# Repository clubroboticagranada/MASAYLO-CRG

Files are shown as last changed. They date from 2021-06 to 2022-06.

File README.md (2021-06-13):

# MASAYLO-CRG
MASAYLO-CRG es un robot creado a partir de la idea de Antonio Gómez (https://github.com/agomezgar/masaylo) del que se van a desarrollar las tres versiones que se describen en la documentación y que tiene como propósito principal ser un robot sencillo de imprimir y de construir y que pueda servir para iniciar en el tema STEAM al alumnado desde los últimos cursos de educación primaria hasta bachillerato y ciclos formativos pasando por las distintas etapas de la ESO.

[Acceso a la documentación del proyecto](https://clubroboticagranada.github.io/MASAYLO-CRG/)

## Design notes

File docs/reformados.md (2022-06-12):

# <FONT COLOR=#8B008B>Mejoras en algunos diseños</font>
***
En este apartado se incluyen los enlaces a los archivos originales de diseño y los archivos en formato stl y step de algunas partes en las que se ha detectado una posible mejora de los diseños originales, todos ellos sin perder la base de la que se partió.

## <FONT COLOR=#007575>**Brazo aparta objetos**</font>
Se ha detectado un debilidad estructural en la parte circular del alojamiento para la pala del servo que es debida fundamentalmente a dos cosas: la primera es porque es muy fino y la segunda está en la forma en que se imprime, que provoca una debilidad por estar en el sentido de las capas. También se ha reforzado la anchura de la pala para hacer un poco mas consistente.

A continuación se ponen los enlaces a todos los archivos.

<center>

| Archivo | Comentarios |
|---|---|
| [brazo-reformado-src.FCStd](../img/3D/modificados/src/brazo-modificado-src.FCStd) | Brazo aparta objetos con alojamiento para la pala del servo reforzado y con mas anchura de pala |

</center>

| Imagen | Archivo STL | Archivo STEP |
|:-:|---|---|
| Brazo aparta objetos reforzado | [brazo-modificado.stl](../img/3D/modificados/stl/brazo-modificado.stl) | [brazo-modificado.step](../img/3D/modificados/step/brazo-modificado.step) |

</center>

En las imágenes siguientes vemos el brazo en tiempo de diseño, impreso en 3D y un detalle de la parte del alojamiento de la pala donde se aprecia mucho mejor el detalle del refuerzo.

</center>

| Captura | Imagen | Detalle |
|---|---|---|
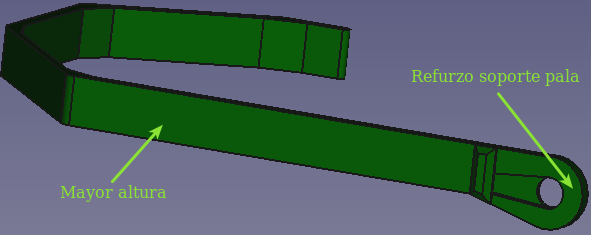
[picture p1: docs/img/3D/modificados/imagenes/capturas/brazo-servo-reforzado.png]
Captura del brazo reforzado
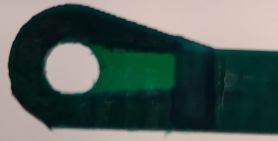
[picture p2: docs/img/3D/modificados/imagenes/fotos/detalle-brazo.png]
Detalle del brazo reforzado
|  | Imagen del brazo reforzado |  |

</center>

## <FONT COLOR=#007575>**Ballcaster**</font>
Se ha detectado un problema de falta de deslizamiento en determinadas superficies lo que provoca que el robot no se mueva todo lo bien que debiera en esos casos. A título de ejemplo indicaremos que sobre un determinado tipo de suelo de vinilo se mueve de forma correcta pero sobre otro suelo vinílico de otra marca ya no lo hace. Esto nos ha llevado a diseñar dos nuevos modelos para el ballcaster, uno se basa en un tornillo de cabeza perdida de M6 de 30 mm de longitud y el otro en poner la clásica canica como superficie de contacto.

A continuación se ponen los enlaces a todos los archivos.

<center>

| Archivo | Comentarios |
|---|---|
| [soportes-ballcaster-modificados.FCStd](../img/3D/modificados/src/soportes-ballcaster-modificados.FCStd) | Archivo fuente con el diseño de los dos tipos de ballcaster |

</center>

| Imagen | Archivo STL | Archivo STEP |
|:-:|---|---|
| Ballcaster con canica | [soporte-ballcaster-canica.stl](../img/3D/modificados/stl/soporte-ballcaster-canica.stl) | [soporte-ballcaster-canica.step](../img/3D/modificados/step/soporte-ballcaster-canica.step) |
| Ballcaster con tornillo de cabeza perdida | [soporte-ballcaster-cabeza-perdida.stl](../img/3D/modificados/stl/soporte-ballcaster-cabeza-perdida.stl) | [soporte-ballcaster-cabeza-perdida.step](../img/3D/modificados/step/soporte-ballcaster-cabeza-perdida.step) |

</center>

En las imágenes siguientes vemos ambos modelos en tiempo de diseño, impresos en 3D y un detalle del elemento ya montado.

</center>

| Captura | Imagen | Montaje |
|---|---|---|
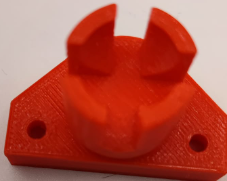
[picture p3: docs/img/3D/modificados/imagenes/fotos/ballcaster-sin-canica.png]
Imagen del ballcaster para canica
| Captura del ballcaster para canica |  | Montaje del ballcaster para canica |
| Captura del ballcaster para tornillo de cabeza perdida | Imagen del ballcaster para tornillo de cabeza perdida | Montaje del ballcaster para tornillo de cabeza perdida |

</center>

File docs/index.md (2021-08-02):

# <FONT COLOR=#8B008B>MASAYLO - CRG</font>
MASAYLO-CRG es un robot creado a partir de la idea de Antonio Gómez (https://github.com/agomezgar/masaylo) del que se van a desarrollar las tres versiones que se exponen a continuación

## <FONT COLOR=#007575>**MASAYLO-CRG-UNO**</font>
Esta versión, basada en la placa [Keyestudio UNO](https://wiki.keyestudio.com/Ks0172_keyestudio_UNO_with_Pin_Header_Interface) está pensada para que el alumnado de los últimos cursos de primaria y los del primer ciclo de ESO trabajen los temas STEAM. En la imagen siguiente vemos el aspecto que presenta el robot MASAYLO-CRG-UNO en fase de diseño. La programación de este modelo la podemos realizar a partir del IDE de Arduino (instalando la librería correspondiente) o a partir del entorno gráfico MASAYLOBLOCKLY.

<center>

| Aspecto general de MASAYLO-CRG-UNO |
|:|
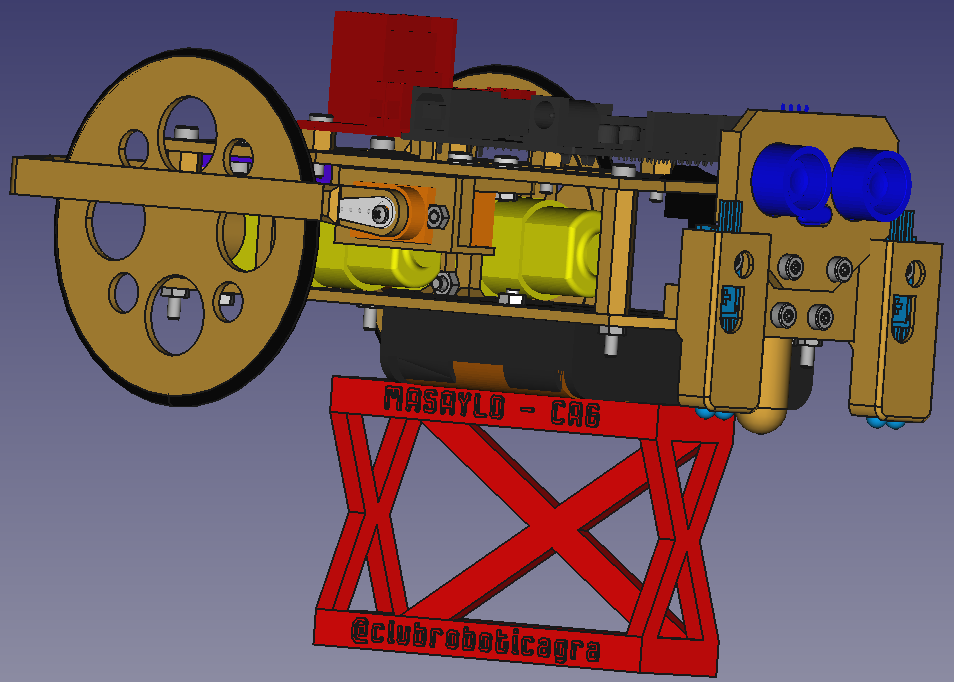
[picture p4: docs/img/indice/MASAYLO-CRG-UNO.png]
Aspecto general de MASAYLO-CRG-UNO
|  |

</center>

## <FONT COLOR=#007575>**MASAYLO-CRG-NANO**</font> 
Se trata de un modelo totalmente similar al anterior pero que en esta ocasión va a utilizar una placa tipo Arduino Nano con una shield que permite también disponer de pines de conexionado rápido. En la imagen de la izquierda vemos la placa y en la de la derecha la shield. El aspecto del robot una vez montado es totalmente similar al de la imagen anterior con la salvedad del cambio de placa.

<center>

| Aspecto placa Nano | Aspecto de la shield para placa Nano |
|:|:|
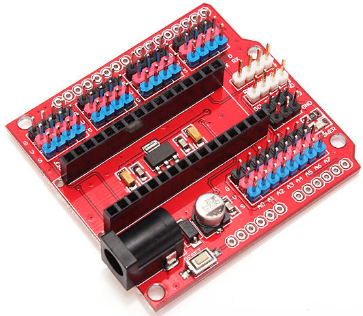
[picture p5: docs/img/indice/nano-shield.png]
Aspecto de la shield para placa Nano
| Aspecto placa Nano |  |

</center>

## <FONT COLOR=#007575>**MASAYLO-CRG-IoT**</font> 
En este caso el modelo se implementa a partir de una placa Node MCU ESP32 con shield que incluye los drivers para motores. Este modelo se dirige a los últimos cursos de ESO, bachillerato y Ciclos Formativos y su principal objetivo, sin dejar atrás la sencillez del robot, es trabajar, además de los temas STEAM, el Internet Of Thing (IoT) o internet de las cosas. Básicamente el robot va dotado de conexión WiFi con todo lo que ello conlleva. La idea principal es poder programarlo a partir de un entorno de programación por bloques, poder desarrollar APPs para móviles o tablets para su control a partir de un entorno gráfico como Blocky, montando nuestro propio servidor para tal fin. Otro objetivo de este robot es poder realizar colaboraciones a distancia consistentes en, por ejemplo, ejercer el control de un robot situado en cualquier parte del mundo desde el lugar en el que el alumnado está trabajando con la APP. En la imagen siguiente a la izquierda vemos el aspecto de la placa ESP32 y a la derecha el de la shield. El aspecto del robot una vez montado es totalmente similar al montado para la versión UNO con la salvedad del cambio de placa y que el driver de motores está integrado en la shield.

<center>

| Aspecto placa Node MCU ESP32 de 30 pines | Aspecto de la shield para placa ESP32 |
|:|:|
| Aspecto placa Node MCU ESP32 de 30 pines | Aspecto de la shield para placa ESP32 |

</center>
  
El propósito principal es que sea un robot sencillo de imprimir y de construir y que pueda servir para iniciar en el tema STEAM al alumnado desde los últimos cursos de educación primaria hasta bachillerato y ciclos formativos pasando por las distintas etapas de la ESO.

Se ha pretendido que los diseños 3D sean fácilmente imprimibles, sin necesidad de soportes y aconsejamos una altura de capa de 0.2mm. Se ha procurado que los tiempos de impresión sean lo más cortos posible pero al mismo tiempo versátiles para las posibles diferencias entre las distintas placas a utilizar. En el apartado de descripción del hardware se pondrán algunos enlaces recomendados para adquisición del material aunque, como no podía ser de otra manera, cada quien lo puede adquirir donde mejor le parezca.

Cualquiera de los modelos puede ser utilizado para otra etapa formativa u objetivo y lo podremos adaptar a nuestras necesidades, siendo esto posible porque se suministran los archivos fuente de diseño y programación y para ello solamente tenemos que cumplir con los requisitos establecidos en las [licencias](./Miscelanea/lic.md).

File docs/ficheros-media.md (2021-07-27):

# <FONT COLOR=#8B008B>Ficheros 3D para impresoras de precisión media</font>
En este apartado se incluyen los enlaces a los archivos originales de diseño y los archivos en formato stl y step.

Los archivos disponibles en este apartado están diseñados pensando en imprimir en impresoras 3D estándar de bajo coste. Estas impresoras se caracterizan por tener ciertas tolerancias en las impresiones finales, requerir calibraciones con cierta asiduidad, etc. Las impresiones con los archivos de este apartado están pensados para compensar estas tolerancias, en especial en los problemas típicos que se no han presentado, como son el ajuste del eje de los motores a la ranura de la rueda o el encaje de las tuercas empotradas en su alojamientos.

## <FONT COLOR=#007575>**Archivos fuente de diseño**</font>
Creados con [FreeCAD](https://www.freecadweb.org/) que puedes modificar, cambiar según necesidades o utilizar para aprender el manejo de esta potente herramienta.

<center>

| Archivo | Comentarios |
|---|---|
| [ruedas](../img/3D-media-precision/src/ruedas-hueco-eje-mayor.FCStd) | Rueda con una sola junta tórica y dos versiones para dos juntas, una con esta juntas y la otra separadas. |
| [soporte-ballcaster-media.FCStd](../img/3D/src/soporte-sensores-IR-ballcaster.FCStd) | Solamente contiene la pieza del ballcaster. El soporte de los sensores verticales de IR es el mismo que en alta precisión |

</center>

## <FONT COLOR=#007575>**Archivos STL y STEP**</font>
* Archivos en formato **stl**, listos para llevar a tu programa de laminación preferido y hacerlos realidad con tu impresora.

La configuración de impresión debe adaptarse en cada caso a la impresora disponible, aunque hacemos las siguientes recomendaciones:

- Balsas: No
- Soportes de impresión: No
- Resolución: 0,2 mm
- Relleno: 15 - 20%
- Marca de filamento: cualquiera
- Color del filamento: el preferido
- Material: PLA

* Archivos en formato **step**, para poder cargarlos en otros programas de diseño CAD.

En la tabla siguiente están los enlaces a estos dos tipos de ficheros.

<center>

| Imagen | Archivo STL | Archivo STEP |
|:-:|---|---|
| Rueda una junta | [rueda-una-junta.stl](../img/3D-media-precision/stl/rueda-una-junta-eje-motor-mayor.stl) | [rueda-una-junta.step](../img/3D-media-precision/step/rueda-una-junta-eje-motor-mayor.step) |
| Rueda dos juntas | [rueda-dos-juntas.stl](../img/3D-media-precision/stl/rueda-dos-juntas-eje-motor-mayor.stl) | [rueda-dos-juntas.step](../img/3D-media-precision/step/rueda-dos-juntas-eje-motor-mayor.step) |
| Rueda dos juntas ancha | [rueda-dos-juntas-ancha.stl](../img/3D-media-precision/stl/rueda-dos-juntas-ancha-eje-motor-mayor.stl) | [rueda-dos-juntas-ancha.step](../img/3D-media-precision/step/rueda-dos-juntas-ancha-eje-motor-mayor.step) |
| Ballcaster precisión media | [soporte-ballcaster-media.stl](../img/3D-media-precision/stl/soporte-ballcaster-media.stl) | [soporte-ballcaster-media.step](../img/3D-media-precision/step/soporte-ballcaster-media.step) |
</center>

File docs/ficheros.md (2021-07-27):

# <FONT COLOR=#8B008B>Ficheros 3D para impresoras de alta precisión</font>
***
En este apartado se incluyen los enlaces a los archivos originales de diseño y los archivos en formato stl y step.

Los archivos disponibles en este apartado están diseñados pensando en imprimir en una impresora del tipo [Prusa MK3S, MK3S+, Prusa Mini o Prusa Mini+](https://www.prusa3d.es/) Originales. Estas impresoras, además de tener una calidad de impresión muy buena, están optimizadas para que las impresiones finales tengan muy poca tolerancia, en lo que respecta a dimensiones, con relación a las medidas originales de diseño. Es muy posible,si no disponemos de impresoras como estas o de calidades similares, que al imprimir estos diseños tengamos algún problema a la hora de ensamblar nuestro robot y tengamos que retocar a mano ciertas partes. Ejemplos típicos de esto que se no han dado son el ajuste del eje de los motores a la ranura de la rueda o el encaje de las tuercas empotradas en su alojamientos.

<FONT COLOR=#FF0000><FONT SIZE="5">**Si no dispones de una impresora como las citadas, o similar, te aconsejamos que utilices los archivos que se suministran en el apartado [3D precisión media](./ficheros-media.md)** para las piezas incluidas en dicho apartado.</font></font>

## <FONT COLOR=#007575>**Archivos fuente de diseño**</font>
Creados con [FreeCAD](https://www.freecadweb.org/) que puedes modificar, cambiar según necesidades o utilizar para aprender el manejo de esta potente herramienta.

<center>

| Archivo | Comentarios |
|---|---|
| [plataforma-base-src.FCStd](../img/3D/src/plataforma-base-src.FCStd) | Para colocar el portapilas, los motores DC, el zumbador y el ballcaster o punto de apoyo estilo rueda loca |
| [soporte-zumbador-src.FCStd](../img/3D/src/soporte-zumbador-src.FCStd) | Para colocar un zumbador pasivo. Esta pieza también se puede colocar en la plataforma superior |
| [soporte-sensores-IR-ballcaster.FCStd](../img/3D/src/soporte-sensores-IR-ballcaster.FCStd) | Contiene dos piezas, el ballcaster y el soporte de los sensores verticales de IR |
| [soportes-ultrasonidos.FCStd](../img/3D/src/soportes-ultrasonidos.FCStd) | Contiene los soporte fijo y móvil para el sensor HC-SR04 |
| [plataforma-superior-src.FCStd](../img/3D/src/plataforma-superior-src.FCStd) | Para colocar cualquiera de las placas, el interruptor y sujetar el servo del brazo |
| [ruedas.FCStd](../img/3D/src/ruedas.FCStd) | Rueda con una sola junta tórica y dos versiones para dos juntas, una con esta juntas y la otra separadas. |
| [base-servo-src.FCStd](../img/3D/src/base-servo-src.FCStd) | Pieza para sujetar un servo tipo SG90 |
| [brazo-src.FCStd](../img/3D/src/brazo-src.FCStd) | Brazo aparta objetos con alojamiento para la pala del servo |
| [separadores-src.FCStd](../img/3D/src/separadores-src.FCStd) | M3x5 para placa UNO y driver y M3x28 para unir plataformas base y superior |
| [soporte-pruebas.FCStd](../img/3D/src/soporte-pruebas.FCStd) | Pieza pensada para poner encima el robot y poder hacer pruebas sin que este se mueva del sitio |
| [disco-encoder.FCStd](../img/3D/src/disco-encoder.FCStd) | Disco de 23 mm de diámetro con 20 ranuras acoplable a eje de motor para encoder optico |
| [conjunto-src.FCStd](../img/3D/src/conjunto-src.FCStd) | Muestra la colocación de los distintos elementos en fase de diseño |
| [Todo en un archivo zip](../img/3D/src.zip) | Para descargar todos los archivos en un clic |

</center>

## <FONT COLOR=#007575>**Archivos STL y STEP**</font>
* Archivos en formato **stl**, listos para llevar a tu programa de laminación preferido y hacerlos realidad con tu impresora.

La configuración de impresión debe adaptarse en cada caso a la impresora disponible, aunque hacemos las siguientes recomendaciones:

- Balsas: No
- Soportes de impresión: No
- Resolución: 0,2 mm
- Relleno: 15 - 20%
- Marca de filamento: cualquiera
- Color del filamento: el preferido
- Material: PLA

* Archivos en formato **step**, para poder cargarlos en otros programas de diseño CAD.

En la tabla siguiente están los enlaces a estos dos tipos de ficheros.

<center>

| Imagen | Archivo STL | Archivo STEP |
|:-:|---|---|
| Ballcaster | [ballcaster.stl](../img/3D/stl/ballcaster.stl) | [ballcaster.step](../img/3D/step/ballcaster.step) |
| Base para servo | [base-servo.stl](../img/3D/stl/base-servo.stl) | [base-servo.step](../img/3D/step/base-servo.step) |
| Brazo | [brazo.stl](../img/3D/stl/brazo.stl) | [brazo.step](../img/3D/step/brazo.step) |
| Disco encoder óptico | [disco-encoder.stl](../img/3D/stl/disco-encoder.stl) | [disco-encoder.step](../img/3D/step/disco-encoder.step) |
| Base | [plataforma-base.stl](../img/3D/stl/plataforma-base.stl) | [plataforma-base.step](../img/3D/step/plataforma-base.step) |
| Plataforma superior | [plataforma-superior.stl](../img/3D/stl/plataforma-superior.stl) | [plataforma-superior.step](../img/3D/step/plataforma-superior.step) |
| Rueda una junta | [rueda-una-junta.stl](../img/3D/stl/rueda-una-junta.stl) | [rueda-una-junta.step](../img/3D/step/rueda-una-junta.step) |
| Rueda dos juntas | [rueda-dos-juntas.stl](../img/3D/stl/rueda-dos-juntas.stl)| [rueda-dos-juntas.step](../img/3D/step/rueda-dos-juntas.step) |
| Rueda dos juntas ancha | [rueda-dos-juntas-ancha.stl](../img/3D/stl/rueda-dos-juntas-ancha.stl)| [rueda-dos-juntas-ancha.step](../img/3D/step/rueda-dos-juntas-ancha.step) |
| Porta sensores IR | [porta-sensores-IR.stl](../img/3D/stl/porta-sensores-IR.stl) | [porta-sensores-IR.step](../img/3D/step/porta-sensores-IR.step) |
| Separador M3x5mm | [separador-M3x5.stl](../img/3D/stl/separador-M3x5.stl) | [separador-M3x5.step](../img/3D/step/separador-M3x5.step) |
| Separador M3x28mm | [separador-M3x28.stl](../img/3D/stl/separador-M3x28.stl) | [separador-M3x28.step](../img/3D/step/separador-M3x28.step) |
| Banco para pruebas | [soporte-para-pruebas.stl](../img/3D/stl/soporte-para-pruebas.stl) | [soporte-para-pruebas.step](../img/3D/step/soporte-para-pruebas.step) |
| Soporte para zumbador pasivo | [soporte-zumbador.stl](../img/3D/stl/soporte-zumbador.stl) | [soporte-zumbador.step](../img/3D/step/soporte-zumbador.step) |
| Soporte HC04 fijo | [ultrasonidos-fijo.stl](../img/3D/stl/ultrasonidos-fijo.stl) | [ultrasonidos-fijo.step](../img/3D/step/ultrasonidos-fijo.step) |
| Soporte HC04 movil | [ultrasonidos-movil.stl](../img/3D/stl/ultrasonidos-movil.stl) | [ultrasonidos-movil.step](../img/3D/step/ultrasonidos-movil.step) |
| Todos los archivos en un zip | [Todos los stl en un zip](../img/3D/stl.zip) | [Todos los step en un zip](../img/3D/step.zip) |

</center>

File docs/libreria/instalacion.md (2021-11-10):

# <FONT COLOR=#8B008B>Instalación de la librería para Arduino</font>
La librería se instala como cualquier librería de arduino:

* Descargamos la [Librería](https://github.com/clubroboticagranada/masaylo-libreria/blob/main/Masaylo.zip).

* Abrimos el IDE de Arduino (entorno de desarrollo de Arduino). Para instalarlo si no lo tienes, lo puedes descargar en la dirección: [https://www.arduino.cc/en/software](https://www.arduino.cc/en/software)
* Nos dirigimos al Menú Programa > Incluir librería > Añadir biblioteca .ZIP ...

<center>

| Incluir librería añadir .zip|
|:|
| Incluir librería añadir .zip |

</center>

* En la siguiente ventana elegimos la ruta de la biblioteca o librería a instalar, que en nuestro caso es Masaylo.zip, habrá que recordar dónde la descargamos previamente.

| Incluir librería elegir .zip|
|:|
| Incluir librería elegir .zip |

</center>

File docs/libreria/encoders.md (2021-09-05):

# <FONT COLOR=#8B008B>Encoders y Masaylo</font>
Masaylo puede incorporar dos sensores de infrarrojos tipo encoder, uno en cada una de las ruedas del mismo. Estos dispositivos sirven para poder determinar de forma optica el ángulo de giro que se desplaza cada rueda, y por tanto también somos capaces de conocer los desplazamientos del robot. Con estos elementos podemos girar un determinado ángulo nuestro robot o bien moverlo una cierta distancia.

<center>

| Encoders esquema | Encoders foto |
|:|:|
| Encoders esquema | Encoders foto |

</center>

Las órdenes que tenemos para controlar los encoders son las siguientes:

* ***objetoMasaylo.encoders (pinIzdoEncoder, pinDchoEncoder, diametro cm)***: Configura los pines de los sensores infrarrojos de los encoders y el diámetro en cm de las ruedas. Si no pasas parámetros *objetoMasaylo.encoders()*, pone los valores *objetoMasaylo.encoders(2,3,7.8)*, por tanto se asigna el pin digital 2 al sensor izquierdo y el 3 al derecho, además configura un diámetro de rueda de 7.8 cm. Recordar que esta instrucción al ser de configuración debe estar en el setup de nuestro programa. En el ejemplo *m.encoders (2,3,7.8)*.
* ***objetoMasaylo.distancia (distancia cm)***: Espera hasta que ambas ruedas del robot se han movido la cantidad de cm que le hemos pasado. En el ejemplo *m.distancia (20)*.
* ***objetoMasaylo.angulo (angulo grados)***: Espera hasta que ambas ruedas del robot han girado el angulo pasado. En el ejemplo *m.angulo (90)*.
* ***objetoMasaylo.vueltas (n_vueltas)***: Espera hasta que ambas ruedas del robot Masaylo han girado el numero de vueltas indicadas.

En el ejemplo que presentamos a continuación (ejemplo 3 de la librería), hacemos un bucle for para repetir cuatro veces el desplazamiento del robot 20 cm y el giro hacia derechas de 90º, por tanto el robot debe realizar un desplazamiento en forma de cuadrado. 

<center>

| Uso de encoders |
|:|
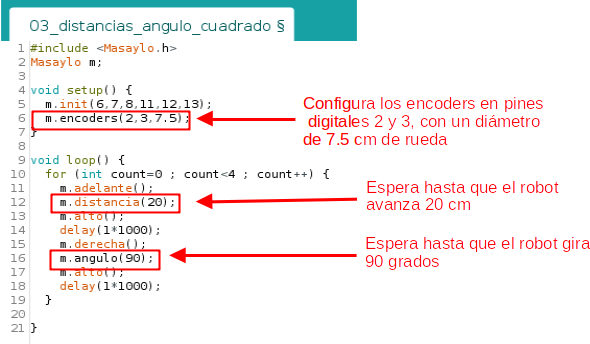
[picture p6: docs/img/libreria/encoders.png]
Uso de encoders
|  |

</center>

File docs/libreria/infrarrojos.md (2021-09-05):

# <FONT COLOR=#8B008B>Infrarrojos y Masaylo</font>
Masaylo incorpora dos sensores de infrarrojos alojados en sendos portasensores en la parte delantera cercanos al suelo, el objeto de los mismos es detectar reflexión o no de luz infrarroja sobre una superficie, pudiendo distinguir entre superficies que reflejan (blanco) y otras que no lo hacen (negro).

<center>

| Infrarrojos |
|:|
| Infrarrojos |

</center>

Las órdenes que tenemos para controlar los sensores de infrarrojos son las siguientes:

* ***objetoMasaylo.infrarrojos (pinIzdoIr,pinDchoIr)***: Configura los pines de los sensores infrarrojos de suelo del robot. Si no pasas parámetros *objetoMasaylo.infrarrojos()*, pone los valores *objetoMasaylo.infrarrojos(14,15)*, asociando el sensor izquierdo al pin 14 (A0), y el derecho al pin 15 (A1), esta instrucción debe estar en el setup de nuetro programa. En nuestro caso del ejemplo *m.infrarrojos (14,15)*.
* ***objetoMasaylo.nIzquierda ()***: Nos devuelve "true" si el sensor de infrarrojos izquierdo está a negro y "false" si no lo está. En nuestro ejemplo *m.nIzquierda()*.
* ***objetoMasaylo.nDerecha ()***: Nos devuelve "true" si el sensor de infrarrojos derecho está a negro y "false" si no lo está. En nuestro ejemplo *m.nDerecha()*.
* ***objetoMasaylo.bIzquierda ()***: Nos devuelve "true" si el sensor de infrarrojos izquierdo está a blanco y "false" si no lo está. En nuestro ejemplo *m.bIzquierda()*.
* ***objetoMasaylo.bDerecha ()***: Nos devuelve "true" si el sensor de infrarrojos derecho está a blanco y "false" si no lo está. En nuestro ejemplo *m.bDerecha()*.

En el ejemplo que presentamos a continuación (ejemplo 9 de la librería), se configura el sensor de infrarrojos, y posteriormente, con varios condicionales, se comprueba todas las combinaciones posibles de estados de blanco y negro de los sensores, para mostrar el estado actual de los mismos en la pantalla del ordenador a través de comunicación serie.

<center>

| Uso de infrarrojos |
|:|
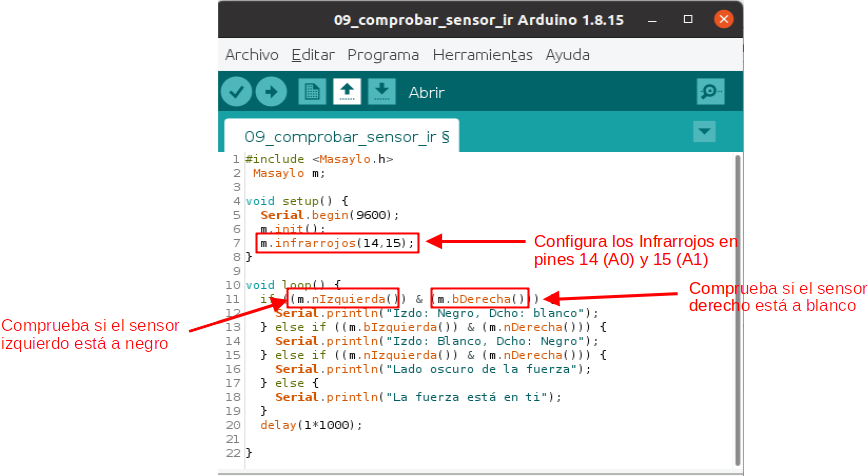
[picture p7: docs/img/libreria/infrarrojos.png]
Uso de infrarrojos
|  |

</center>

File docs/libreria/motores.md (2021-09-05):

# <FONT COLOR=#8B008B>Controlar motores de Masaylo</font>

<center>

| Motores |
|:|
| Motores |

</center>

Para el control de los dos motores de corriente contínua que mueven a Masaylo, lo primero que debemos hacer es crear un objeto tipo robot Masaylo, para ello pondremos la línea antes de void setup(), ***Masaylo objetoMasaylo***, en nuestro caso *Masaylo m* (nuestro robot Masaylo se llama m).

<center>

| Crear objeto Masaylo|
|:|
| Crear objeto Masaylo |

</center>

En la función setup(), ya sabéis que se ejecuta una sola vez, vamos a definir los pines de los motores, lo que se puede hacer de dos maneras:

* Sin pasar parámetros (sin colocar nada entre los paréntesis), ***objetoMasaylo.init()***, en nuestro caso de ejemplo *m.init()*: con esta orden indicamos que los pines de los motores son los que trae por defecto *objetoMasaylo.init(6,7,8,11,12,13)*, siendo el orden de los pines definidos de izquierda a derecha,  pin de control de velocidad de giro (PWM) del motor izquierdo, pin A del motor izquierdo,  pin B del motor izquierdo, pin de control de velocidad de giro (PWM) del motor derecho, pin A del motor derecho,  pin B del motor derecho.
* Pasando parámetros de pines (colocándolos entre paréntesis), ***objetoMasaylo.init (pinPWMMotorIzdo,pinAMotorIzdo,pinBMotorIzdo,pinPWMMotorDcho,pinAMotorDcho,pinBMotorDcho)***, de esta manera podríamos conectar nuestros motores a los pines que deseemos, un ejemplo podría ser *m.init(6,7,8,11,12,13)*.

Pasamos a explicar las instrucciones para mover el robot:

* ***objetoMasaylo.adelante (velocidad)***: Mueve el robot Masaylo hacia delante, le podemos pasar el valor de la velocidad a la que lo hace (entre 0 y 255), si no pasamos valor, paréntesis sin valor, lo hace a 255. En nuestro caso del ejemplo *m.adelante()*.
* ***objetoMasaylo.atras (velocidad)***: Mueve el robot Masaylo hacia atrás, le podemos pasar el valor de la velocidad a la que lo hace (entre 0 y 255), si no pasamos valor,  paréntesis sin valor, lo hace a 255. En nuestro caso del ejemplo *m.atras()*.
* ***objetoMasaylo.izquierda (velocidad)***: Gira (pivota) el robot Masaylo hacia la izquierda, le podemos pasar el valor de la velocidad a la que lo hace (entre 0 y 255), si no pasamos valor, paréntesis sin valor, lo hace a 255. En nuestro caso del ejemplo *m.izquierda()*.
* ***objetoMasaylo.derecha (velocidad)***: Gira (pivota) el robot Masaylo hacia la derecha, le podemos pasar el valor de la velocidad a la que lo hace (entre 0 y 255), si no pasamos valor, paréntesis sin valor, lo hace a 255. En nuestro caso del ejemplo *m.derecha()*.
* ***objetoMasaylo.alto ()***: Para el robot Masaylo. En nuestro caso del ejemplo *m.alto()*.

A continuación vemos estas órdenes reflejadas en el ejemplo 01 de la librería:

<center>

| Ejemplo 01 de la librería |
|:|
| Ejemplo 01 de la librería |

</center>

En el ejemplo 02 vemos como se pasan valores de velocidad a los movimientos de nuestro robot:

<center>

| Ejemplo 02 de la librería |
|:|
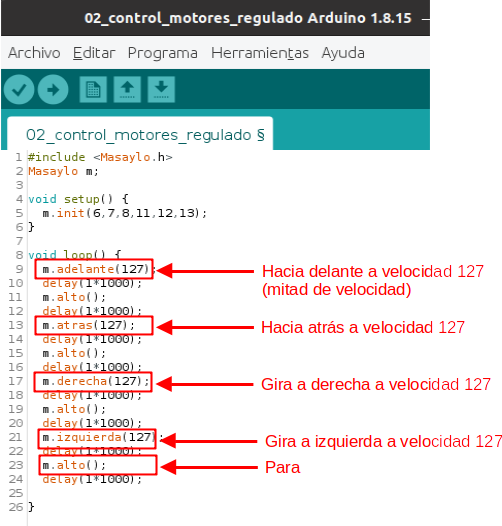
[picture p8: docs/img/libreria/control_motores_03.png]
Ejemplo 02 de la librería
|  |

</center>

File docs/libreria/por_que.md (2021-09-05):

# <FONT COLOR=#8B008B>El por qué de la librería</font>
Unos de los problemas para controlar robots muchas veces es la ausencia de instrucciones amigables en arduino para controlar sus elementos (motores dc, sensor de ultrasonidos, sensores infrarrojos para seguir líneas, control de distancias y giros a través de encoders, servomotores y zumbadores), todo ello pensando en facilitar el uso de dicho robot para estudiantes de secundaria. Por este motivo, a través de la colaboración entre el ***Club de Robótica Granada*** y ***Antonio Gómez***, nos planteamos adaptar la librería de su robot Masaylo para el control de una revisión de dicho robot.

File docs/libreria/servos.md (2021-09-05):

# <FONT COLOR=#8B008B>Servomotores y Masaylo</font>
Masaylo incorpora dos servomotores, uno que nos sirve para girar el sensor de ultrasonidos situado en la zona delantera del robot, y otro para girar el brazo que sirve para capturar objetos. Los servomotores que presenta Masaylo son los microservos *SG-90* que permiten un giro entre 0º y 179º.

| Servomotores |
|:|
| Servomotores |

</center>

Las órdenes que tenemos para controlar los servomotores son:

* ***objetoMasaylo.servos (pin servocabeza, pin servobrazo)***: Configura los pines de los servos de la cabeza y del brazo respectivamente. Si no pasas parámetros *objetoMasaylo.servos()*, pone los valores *objetoMasaylo.servos(5,4)*, por tanto el servo de la cabeza (ultrasonidos) es asignado al pin digital 5 y el servo del brazo al pin digital 4, esta instrucción debe estar en el setup de nuestro programa. En el ejemplo *m.servos(5,4)*.
* ***objetoMasaylo.giracabeza (grados)***: Gira el servo de la cabeza un ángulo dado entre 0º y 179º. En el ejemplo *m.giracabeza (i)*, siendo i una variable en este caso.
* ***objetoMasaylo.girabrazo (grados)***: Gira el servo del brazo un ángulo dado entre 0º y 179º.
  
En el ejemplo que presentamos a continuación (ejemplo 6 de la librería) se configura los pines de los servomotores, para posteriormente producir un movimiento giratorio alternativo del sensor de ultrasonidos, moviéndolo con un microservo de 10º a 170º y de 170º a 10º.

<center>

| Control de servomotores |
|:|
| Control de servomotores |

</center>

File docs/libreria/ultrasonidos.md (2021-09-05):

# <FONT COLOR=#8B008B>Ultrasonidos y Masaylo</font>
Masaylo incorpora un sensor de ultrasonidos en su parte delantera, que nos servirá para medir distancias a los objetos que pueda encontrar en su camino.

<center>

| Sensor de Ultrasonidos |
|:|
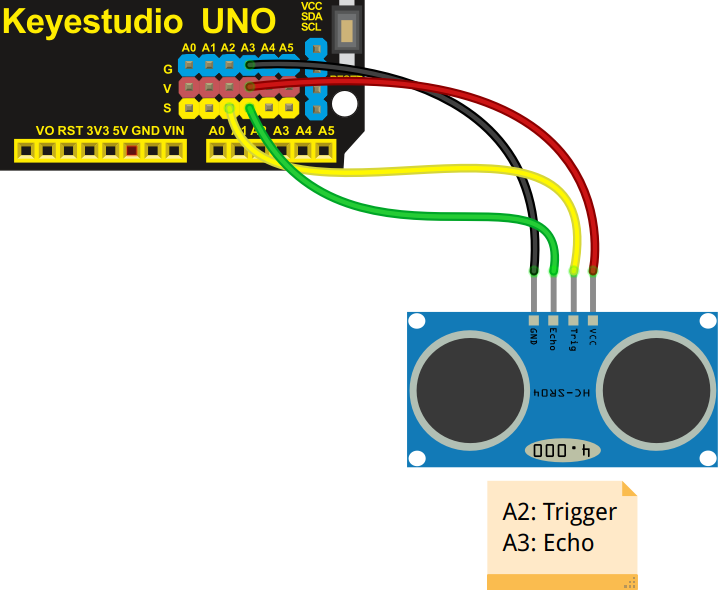
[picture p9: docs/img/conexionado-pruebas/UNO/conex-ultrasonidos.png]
Sensor de ultrasonidos
|  |

</center>

Las órdenes que tenemos para controlar el sensor de ultrasonidos son:

* ***objetoMasaylo.ultrasonidos (pinTrigger,pinEcho)***: Configura los pines trigger y echo del sensor de ultrasonidos. Si no pasas parámetros *objetoMasaylo.ultrasonidos()*, pone los valores *objetoMasaylo.ultrasonidos(16,17)*, de esta forma el pin del Trigger es el 16 (A2), y el pin del Echo es el 17 (A3), esta instrucción debe estar en el setup de nuestro programa. En nuestro caso del ejemplo *m.ultrasonidos (16,17)*.
* ***objetoMasaylo.distancia ()***: Nos devuelve la distancia en cm entre el sensor de ultrasonidos y el objeto que tenga enfrentado. En nuestro caso del ejemplo *m.distancia()*.
  
En el ejemplo que presentamos a continuación (ejemplo 8 de la librería), se configura el sensor de ultrasonidos, para mostrar por el puerto serie la distancia a la que se encuentra un objeto enfrentado al robot masaylo.

<center>

| Uso de ultrasonidos |
|:|
| Uso de ultrasonidos |

</center>

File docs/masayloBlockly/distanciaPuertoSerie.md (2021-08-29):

# <FONT COLOR=#8B008B>Detección de obstáculos. Uso del puerto serie</font>

En esta práctica aprenderemos a inicializar el sensor de ultrasonidos HC-SR04 del robot Masaylo y utilizarlo para detectar obstáculos, calcular la distancia a la que se encuentran y enviar dicho dato a nuestro ordenador para que podamos leerlo de manera directa a través del *monitor del puerto serie*

## <FONT COLOR=#007575>**¿Qué es el monitor del puerto serie?**</font>

El puerto serie es el canal de comunicación que utiliza Arduino para comunicarse con nuestro ordenador a través de nuestro cable USB, para cargar los programas compilados a través del IDE o enviar y recibir información. Los pines digitales 0 (Rx) y 1 (Tx) del microcontrolador son los encargados de realizar dicha comunicación, razón por la que se aconseja dejar ambas patillas sin conectar en nuestro sistema de control si vamos a necesitar comunicación o en el momento de cargar un nuevo programa.

El IDE de Arduino nos facilita dicha comunicación utilizando los comandos *Serial.begin(velocidad)* (la velocidad estándar suele ser de 9600 baudios), y los comandos *Serial.print(texto)* para escribir, *Serial.println(texto)* para escribir con retorno de carro, o *Serial.read(dato)* para recibir información. Para abrir este canal de comunicación, dicha IDE nos ofrece un icono muy característico.

<center>

| Icono de apertura del puerto serie en el IDE de Arduino |
| :-: |
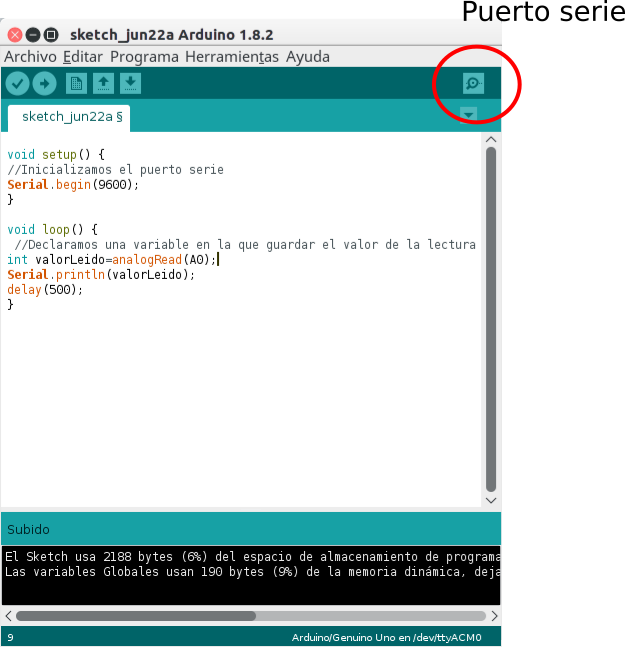
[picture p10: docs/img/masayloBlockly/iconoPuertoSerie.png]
Icono del puerto serie
|  |

</center>

Al hacer click en dicho icono, se abre una nueva ventana en la que Arduino imprimirá la correspondiente información a medida que transcurra el programa.

<center>

| Ventana del puerto serie en el IDE |
| :-: |
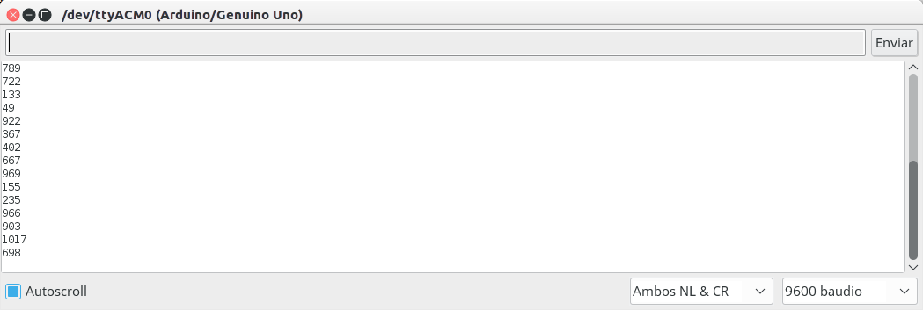
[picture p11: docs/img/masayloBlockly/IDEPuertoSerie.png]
Ventana del puerto serie
|  |

</center>

Como siempre, MasayloBlockly nos facilitará esta tarea. Dentro del conjunto de bloques de programación asignados a "modo experto" (alcanzable, como el lector recordará, a través del icono de preferencias Configuracion ),podemos incluir en la zona de opciones el grupo "Puerto Serie", del que utilizaremos, en esta actividad de iniciación, las siguientes piezas:

| Icono|Función |
|---|---|
 | Inicio del puerto serie | Inicializar el puerto serie a la velocidad en baudios indicada (9600 por defecto, configurable) |
 | Escribir línea | Arduino escribirá en el puerto serie el texto o dato que le indiquemos (incluye un texto editable por defecto, pero lo sustituiremos por la lectura del sensor) |

 <font color=#ff0000>**NOTA: LA PIEZA DE INICIALIZACIÓN DEL PUERTO SERIE NO ESTÁ PREPARADA PARA ENCAJAR CON LAS OTRAS, PUESTO QUE HACE REFERENCIA A UNA TAREA DE CONFIGURACIÓN PREVIA AL HILO GENERAL QUE DESARROLLARÁ EL PROGRAMA. NO HAY PROBLEMA EN DEJARLA EN EL ESPACIO DE TRABAJO DE MODO INDEPENDIENTE DE LAS DEMÁS**
 
 **OTRA NOTA: POR MOTIVOS DE CONFIGURACIÓN, EL MONITOR DEL PUERTO SERIE DE MASAYLOBLOCKLY SÓLO DEVUELVE LECTURAS DESPUÉS DE LEER UN RETORNO DE CARRO. ESO SIGNIFICA QUE SI UTILIZAMOS LA PIEZA *ENVIAR A PUERTO SERIE* SIN COMPLETAR CON *ESCRIBIR LÍNEA*, NO APARECERÁ INFORMACIÓN ALGUNA EN LA VENTANA DE DICHO MONITOR**
 </font>

 Como actividad de ampliación, sugerimos al lector que utilice el bloque de opciones "Textos" disponible en el menú de preferencias para combinar textos con el resultado medido, tal y como podrá ver en la solución final que ofrecemos.

## <FONT COLOR=#007575>**Uso del sensor de ultrasonidos como detector de obstáculos**</font>

En la sección de [análisis de elementos de la versión UNO](../../conexionado-pruebas/UNO/elementos/#sensor-de-distancia-hc-sr04) se explica sobradamente las características y el conexionado del sensor de ultrasonidos. En MasayloBlockly es muy fácil inicializar el sensor de ultrasonidos indicando los pines a que hemos conectado ***ECHO*** y ***TRIGGER***, y obtener lecturas periódicas de la distancia a cualquier obstáculo que se pueda encontrar en el rango de alcance de dicho sensor.

<center>

| El sensor de ultrasonidos puede detectar obstáculos y medir su distancia |
| :-: |
| Ventana del puerto serie |

</center>

Las piezas que utilizaremos para tal fin serán:

| Icono|Función |
|---|---|
 | Inicialización del Sensor | Inicializar el sensor de ultrasonidos indicando los pines TRIGGER y ECHO (por defecto, A2 y A3, pero la pieza es editable) |
 | Lectura de distancia | Esta pieza devuelve la lectura en cm indicada por el sensor en su última lectura |

## <FONT COLOR=#007575>**Objetivos de la práctica**</font>

Como ya hemos explicado, queremos mostrar el uso del puerto serie al usuario no avezado de un modo sencillo, utilizándolo como canal de comunicación para obtener las distancias obtenidas por el sensor de distancia en lecturas periódicas. Podemos, pues, establecer los siguientes objetivos:

+ Inicializar el puerto serie del robot Masaylo estableciendo una velocidad estándar (9600 baudios).
+ Inicializar el robot Masaylo indicando, en su caso, los pines de control de motores.
+ Inicializar el sensor de ultrasonidos indicando los pines de conexión a **TRIGGER** y **ECHO**, en caso de ser distintos a los establecidos por defecto.
+ Realizar una lectura de distancia y pasarla al puerto serie para su lectura por parte del usuario.
+ Esperar un segundo.
+ Repetir el bucle.

<center>

| Práctica: lectura de distancias a través del puerto serie |
|:-:|
| Leyendo el puerto serie |

</center>

### <FONT COLOR=#007575>**Programa: lectura de distancias medidas por el sensor US a través del puerto serie**</font>

La siguiente imagen desarrolla el programa utilizado (<font color=#0000FF>Nota: este programa está disponible en el botón de Ejemplos del menú principal, con el título "Envía la distancia al obstáculo detectado al puerto serie de tu ordenador").</font>

<center>

| Programa: envío de los datos de distancia al puerto serie |
|:-:|
| Programando con PWM |

</center>

### <FONT COLOR=#007575>**Resultado: lectura de distancias a través del puerto serie**</font>

Para abrir el monitor del puerto serie, sólo hay que hacer doble click en el icono Monitor serie para abrir la ventana del monitor y hacer click en el botón ***Arrancar** (debe asegurarse de que la velocidad estipulada es 9600) para iniciar la comunicación con el sistema de control del Masaylo:

<center>

| Lectura de los datos de distancia usando el monitor de MasayloBlockly |
|:-:|
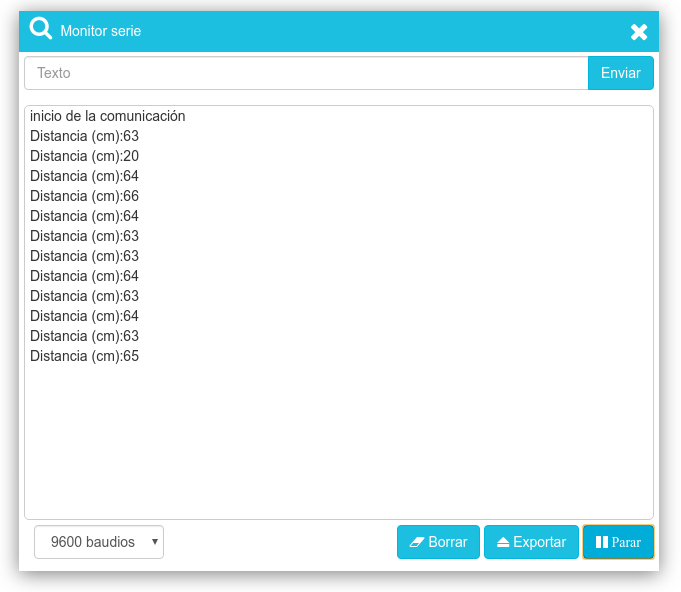
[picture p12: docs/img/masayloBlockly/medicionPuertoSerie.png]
Leyendo el puerto serie
|  |

</center>

### <FONT COLOR=#007575>**Ejercicio de ampliación: programar un sistema de desplazamiento que evite obstáculos**</font>

Con lo mostrado hasta aquí, el lector debería ya estar suficientemente capacitado para programar a Masaylo de modo que éste se mueva de forma autónoma evitando los obstáculos que se presenten. En el botón de Ejemplos del menú principal hay precisamente un algoritmo que cumple este objetivo, llamado "Aprende a detectar obstáculos con el sensor US y a esquivarlos mediante movimientos aleatorios".

<center>

| Ejercicio de ampliación: movimiento autónomo con detección y evasión de obstáculos |
|:-:|
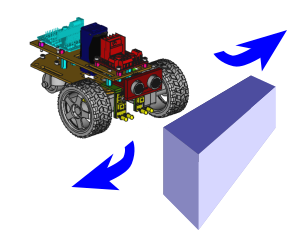
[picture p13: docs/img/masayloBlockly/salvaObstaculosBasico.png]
|  |

</center>

## <FONT COLOR=#007575>**Vídeo explicativo: uso del puerto serie para leer distancias a obstáculos detectados**</font>

<iframe width="560" height="315" src="https://www.youtube.com/embed/zfkvxzSqDQE" title="YouTube video player" frameborder="0" allow="accelerometer; autoplay; clipboard-write; encrypted-media; gyroscope; picture-in-picture" allowfullscreen></iframe>

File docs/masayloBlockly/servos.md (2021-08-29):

# <FONT COLOR=#8B008B>Uso de servomotores en brazo y cabeza</font>

Como se suele decir en inglés, "last but no least", por último, pero no por ello menos importante, Masaylo nos ofrece también la opción de utilizar servomotores de posición de modelo SG-90 o similar que permiten el movimiento angular, si así lo deseamos, del sensor de ultrasonidos (aunque también se nos ofrece la opción de dejarlo fijo) y de un brazo auxiliar que posibilitaría la captura y/o desplazamiento de pequeños obstáculos.

<center>

| Masaylo puede incorporar dos servomotores que agreguen movilidad a algunas partes|
|:-:|
| Instalando servos |

</center>

## <FONT COLOR=#007575>**Inicialización y uso de los servomotores**</font>

En MasayloBlockly podemos encontrar las siguientes piezas de programación para controlar estos servomotores:

| Icono| Función |
|:-:|---|
| Inicio de servomotores | Inicializar los servomotores indicando sus pines para cabeza (sensor de US) y brazo. Si no se va a respetar el conexionado por defecto, es aconsejable utilizar patillas con PWM |
| girarCabeza | Indicar el ángulo al que queremos girar el sensor de ultrasonidos. 90 º constituye la posición central|
| Girar brazo | Cuando Masaylo está en marcha hacia adelante, espera a haber avanzado la distancia indicada antes de pasar a la siguiente orden|
| Esperar a girar un ángulo determinado | Indicar el ángulo al que queremos girar el brazo auxiliar. 90 º constituye la posición central|

## <FONT COLOR=#007575>**Objetivos de la práctica**</font>

Limitémonos en esta ocasión a probar el servomotor del cabezal del sensor de ultrasonidos (el brazo auxiliar obedecería exactamente del mismo modo) de acuerdo a la siguiente pauta:

+ Inicializar el robot Masaylo.
+ Inicializar ambos servos, especificando el pin al que va conectado cada uno.
+ Partiendo de 10 º, realizar el giro hasta una posición de 170 º, con variaciones de 10 º a cada cambio
+ Invertir el proceso y girar progresivamente de 170 º a 10 º
+ Repetición del bucle

### <FONT COLOR=#007575>**Más bloques lógicos: *repetir hasta que* y *repetir por intervalos* . Trabajo con variables**</font>

Seguimos aprovechando para enriquecer nuestro acervo de comandos lógicos, tan necesarios en programación. En esta ocasión, utilizaremos dos nuevas piezas que permiten la repetición en bucle de conjuntos de órdenes conforme al cumplimiento de determinadas condiciones. Además, aunque no es necesario para este programa, utilizaremos variables por primera vez:

| Icono| Función |
|:-:|---|
| Repetir hasta que | Esta pieza nos permite insertar en su seno un conjunto de órdenes que se repetirán **MIENTRAS SE ESTÉ CUMPLIENDO LA CONDICIÓN QUE ESTIPULEMOS**|
| girarCabeza | De comprensión algo más compleja, pero de suma utilidad para el programador, esta pieza cuenta con una variable a la que dar un *valor inicial*, un *valor final* y un *valor de variación*. Los comandos que albergue en su interior se irán repitiendo en bucle mientras dicha variable se encuentre entre su valor inicial y su final, añadiéndole el valor de variación a cada finalización del bucle. Permite crear algoritmos que repiten ciertas secuencias que se repiten progresivamente con ligeros cambios asociados a dicha variable|

Aunque no es el objetivo de estas líneas hacer un estudio exhaustivo de todas las características de cualquier lenguaje de programación, no está de más saber que es común trabajar con variables. A este respecto, MasayloBlockly también presenta su correspondiente bloque de opciones que empieza con el botón **Crear variable** (indicar su nombre en la ventana emergente que aparecerá) para a continuación ampliar el abanico a las siguientes posibilidades:

<center>

| Menú de trabajo con variables en MasayloBlockly|
|:-:|
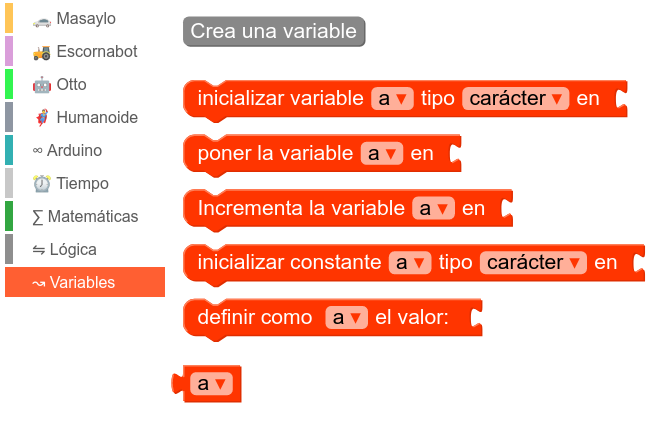
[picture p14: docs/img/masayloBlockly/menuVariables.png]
Menú de variables
|  |

</center>

### <FONT COLOR=#007575> **Programa: giro progresivo a izquierda y derecha** </font>

La imagen siguiente presenta la solución a la práctica propuesta(<font color=#0000FF>Nota: este programa está disponible en el botón de Ejemplos del menú principal, con el título "Gira el cabezal del sensor de ultrasonidos").</font>

Conviene aclarar dos cosas:

1. En condiciones normales, en los bucles que atañen a los movimientos de servomotores, se debe establecer un intervalo mínimo de pausa para no dañar el motor. La librería de Masaylo los incluye ya de serie, por lo que no es necesario, pero en otros robots esto debe ser tenido en cuenta.
2. No es necesario el uso de variables en la segunda parte del programa (habría bastado volver a utilizar una pieza ***Repetir por intervalos***)

<center>

| Práctica: giro del cabezal del sensor de US|
|:-:|
| Giro del cabezal del sensor de ultrasonidos |

</center>

## <FONT COLOR=#007575>**Vídeo explicativo: control de los servomotores de Masaylo**</font>

<iframe width="560" height="315" src="https://www.youtube.com/embed/d8RRcyau6k8" title="YouTube video player" frameborder="0" allow="accelerometer; autoplay; clipboard-write; encrypted-media; gyroscope; picture-in-picture" allowfullscreen></iframe>

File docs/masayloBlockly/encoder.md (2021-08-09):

# <FONT COLOR=#8B008B>Trabajo con encoder. Control básico de distancias y ángulos</font>

Masaylo nos ofrece también la posibilidad de instalar dos encoder modelo  [FC-03](../../conexionado-pruebas/UNO/elementos/#encoder-infrarrojos-fc-03), que permiten un cierto control sobre el ángulo de giro de los motores DC de desplazamiento. Estos sensores, de por sí, son de difícil manejo para los aficionados maker con una cierta experiencia en la implementación de sistemas con Arduino. Además, precisan del manejo de **interrupciones** por parte del microprocesador, concepto éste reservado para estudiantes más avanzados. No obstante, la librería de Masaylo resuelve con cierta elegancia todos estos inconvenientes, permitiendo un control, si no perfecto, sí bastante adecuado de distancias recorridas y ángulos de desplazamiento.
<font color=#ff0000>**Nota: al contrario que en el resto de sensores, los pines de conexión de los encoder no son opcionales. Deben ser forzosamente 2 y 3, aunque puedan intercambiarse entre sí. Esto se debe a que la librería gestiona el funcionamiento de estos sensores basándose en el uso de interrupciones, que en las tarjetas Arduino UNO y NANO deben ser forzosamente estas patillas**</font>

<font color=#0000ff>Repetimos que el uso de estos encoder en Arduino es bastante complicado, por lo que el lector no debería esperar resultados perfectos. Si sujetamos a Masaylo en el aire, es decir, probamos los programas en vacío, obtendremos el funcionamiento más aproximado. Una vez en el suelo, dependiendo del estado de las pilas, podemos encontrar errores más o menos aproximados. </font>

## <FONT COLOR=#007575>**Control de distancias y ángulos en MasayloBlockly**</font>

MasayloBlockly aprovecha al máximo las características de la librería de Masaylo para ofrecernos el siguiente despliegue de opciones:

| Icono| Función |
|:-:|---|
| Inicio de encoders | Inicializar los encoder indicando sus pines a izquierda y derecha. El diámetro hace referencia al de las ruedas de Masaylo. Si el usuario modificara dicho tamaño, debe especificarlo para el correcto cálculo de distancias recorridas. |
| Esperar un número de vueltas determinado | Cuando Masaylo está en marcha hacia adelante, espera a que sus ruedas hayan dado el número de vueltas especificado antes de pasar a la siguiente orden|
| Esperar a recorrer una distancia determinada | Cuando Masaylo está en marcha hacia adelante, espera a haber avanzado la distancia indicada antes de pasar a la siguiente orden|
| Esperar a girar un ángulo determinado | Cuando Masaylo está girando, espera a haber avanzado el ángulo marcado por el usuario antes de pasar a la siguiente orden|

## <FONT COLOR=#007575>**Objetivos de la práctica**</font>

En esta ocasión, nos proponemos utilizar los encoder para hacer que Masaylo haga un recorrido que dibuje un cuadrado de 20 cm. 
Nuestro programa deberá cumplir los siguientes objetivos:

+ Inicializar el robot Masaylo indicando, en su caso, los pines de control de motores.
+ Inicializar los encoder, indicando la patilla a que están conectados (forzosamente deben ser los pines digitales 2 y 3).
+ Repetir en bucle cuatro veces el siguiente conjunto de órdenes:
    + Ir hacia adelante
    + Esperar 20 cm
    + Parar durante 1 segundo
    + Girar a la derecha
    + Esperar a haber completado los 90 º
    + Parar durante 1 segundo
+ Fin del programa. Interrumpir ciclo de trabajo.

### <FONT COLOR=#007575>**Nuevo bloque de control de flujo: uso de bucles**</font>

Aprovechando que hay que repetir conjuntos de órdenes, presentaremos otra de las piezas importantes dentro de la opción **Lógica** de MasayloBlockly: el comando *Repetir x veces*

<center>

| Comando de control de flujo: repetir x veces|
|:-:|
| Leyendo el puerto serie |

</center>

### <FONT COLOR=#007575>**Programa: recorrer un cuadrado perfecto**</font>

La imagen siguiente presenta la solución a la práctica propuesta(<font color=#0000FF>Nota: este programa está disponible en el botón de Ejemplos del menú principal, con el título "Aprende a usar los encoder de ranura para recorrer un cuadrado perfecto").</font>

<center>

| Práctica: recorrer un cuadrado perfecto |
|:-:|
| Leyendo el puerto serie |

</center>

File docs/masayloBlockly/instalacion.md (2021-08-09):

# <FONT COLOR=#8B008B>Mi primer programa. Instalación de librerías</font>
Para compilar y cargar los binarios en Arduino, MasayloBlockly utiliza la herramienta **[arduino-cli](https://github.com/arduino/arduino-cli)**, una solución integral que gestiona la instalación de librerías y tarjetas (Arduino o ESP), la compilación y el volcado del código. Si bien es una herramienta completamente portable y autónoma, MasayloBlockly creará una carpeta en nuestro disco duro (incluso en sus versiones portables) que utilizará para trabajar con archivos temporales. Además, arduino-cli necesita un archivo de configuración e instalar el núcleo de compatibilidad (core) con las tarjetas Arduino y, opcionalmente, tarjetas ESP, así como las librerías que usa MasayloBlockly con estos sistemas de control.

## <FONT COLOR=#007575>**Pasos de instalación detallados**</font>

La primera vez que intentamos compilar/cargar un programa con una nueva versión de MasayloBlockly, el software lo detectará y enviará un mensaje en una ventana emergente indicando que necesita instalar algunas librerías.
<center>

Mensaje de instalación 

</center>

El proceso que sigue a continuación va informando al usuario de manera ordenada en sucesivas ventanas emergentes de los pasos que se van dando. Como el proceso es muy parecido en los sistemas operativos Windows y Linux, procedemos a documentarlo en Linux.

Tras cerrar el primer popup, se abre otro indicando al usuario que espere un mensaje de confirmación. El siguiente paso es crear una carpeta llamada *masaylo* en la carpeta 
> /home/usuario/.masaylo

Una vez creada dicha carpeta, un nuevo mensaje avisa de que se va a proceder a copiar las librerías necesarias en la carpeta 
>/home/usuario/Arduino/libraries

<font color=#00FF00>Si nunca se había trabajado con Arduino antes, dicha carpeta se creará. Si, por el contrario, el usuario ya había experimentado con el IDE de Arduino, dicha carpeta ya existirá, y simplemente se añadirán las carpetas necesarias.</font>
<center>

| Creación de la carpeta .masaylo |
|:-:|
| Paso 1 |

</center>

Como puede verse en la anterior figura, el proceso es lo bastante rápido como para que se solapen algunos pasos. Esto no perjudica en absoluto el resultado final, más bien al contrario.

Una vez copiadas las librerías, se procede a instalar la compatibilidad con las tarjetas Arduino de microcontrolador AVR con las que trabaja MasayloBlockly

<font color=#FF0000>**AVISO: ES NECESARIA UNA CONEXIÓN A INTERNET**</font>
<center>

Paso 2</center>

Dependiendo de la potencia de nuestro ordenador, este proceso puede alargarse un poco. No obstante, en poco tiempo surgirá un nuevo popup de confirmación:

<center>Paso 3</center>

Sólo nos queda instalar la compatibilidad con ESP8266 (como la NodeMCU) y ESP32. Como es opcional, la nueva ventana abierta nos permite elegir si queremos hacer esta instalación.

<center>Paso 4</center>

<FONT color=#FF0000>**DISCLAIMER: Arduino-cli necesita descargar los archivos necesarios para trabajar con estas carpetas de un servidor de Espresiff. Hemos podido comprobar que, en ocasiones, este servidor no responde correctamente y nos podemos encontrar con un mensaje de error. Ello únicamente supone que MasayloBlockly aún no puede trabajar con dichas tarjetas, pero el resto de la instalación se ha llevado a cabo con éxito. En otro apartado hemos dejado un link a un script que nos permitirá volver a intentarlo si nos encontramos con este problema.**</font>

Si elegimos instalar los core de ESP (muy recomendable), se nos avisará de que este proceso puede ser algo más largo que los anteriores.

<center>Paso 5</center>

Si todo va bien, un último mensaje nos confirmará que ya estamos preparados para empezar a trabajar.

<center>Paso 6</center>

## <FONT COLOR=#007575>**Vídeo explicativo: instalación de librerías y archivos de características**</font>

<iframe width="560" height="315" src="https://www.youtube.com/embed/ZMTX7RswBtI" title="YouTube video player" frameborder="0" allow="accelerometer; autoplay; clipboard-write; encrypted-media; gyroscope; picture-in-picture" allowfullscreen></iframe>

## <FONT COLOR=#007575>**¿Qué hacer si falla la instalación de ESP8266 y ESP32?**</font>

Si falla la instalación de tarjetas ESP, no estaremos preparados para usar MasayloBlockly para programar sistemas IoT (Internet of Things, Internet de las cosas), de modo que tenemos dos posibilidades:

+ Desinstalar Masaylo y repetir el proceso (en Linux, bastaría con borrar la carpeta *./masaylo* de nuestra home)
+ Instalar manualmente estas tarjetas con un script (un programa de consola).

### <font color=#0000ff>[LINK A SCRIPT DE INSTALACIÓN DE TARJETAS ESP](instalaESP.zip)</font>

### <FONT COLOR=#007575>**Vídeo explicativo: uso de script de instalación de tarjetas ESP8266 y ESP32**</font>

<iframe width="560" height="315" src="https://www.youtube.com/embed/62xZ-LqR8eM" title="YouTube video player" frameborder="0" allow="accelerometer; autoplay; clipboard-write; encrypted-media; gyroscope; picture-in-picture" allowfullscreen></iframe>

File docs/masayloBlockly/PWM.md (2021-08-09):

# <FONT COLOR=#8B008B>Control de velocidad. Uso de PWM</font>

## <FONT COLOR=#007575>**¿En qué consiste la técnica del PWM?**</font>

Si bien los microcontroladores en que se basan nuestras Arduino pueden **leer** entradas analógicas (señales que pueden tomar infinitos valores de modo variable entre un valor mínimo y uno máximo, normalmente 0 V y 5 V) en algunos de sus pines, no es menos cierto que no pueden **escribir** de este modo en ninguna salida. Ello dificulta en un principio el control de velocidad de robots como Masaylo, que utiliza motores DC cuya velocidad es proporcional al voltaje que  se les aplica. Tal como se explica en el [análisis de elementos de la versión UNO](../../conexionado-pruebas/UNO/elementos/#motores-dc-3-a-6v), la velocidad de dichos motores puede oscilar entre las 125 rpm y las 230 rpm (sin carga) según la tensión varíe entre 3 y 6 V.

Un enfoque del control de movimientos usando salidas digitales sólo permitiría soluciones del tipo todo-nada:

<center>

| Pin de control 1 | Pin de control 2 | Movimiento del motor |
| :---: | :---: | :--- |
| 0 | 0 | Paro |
| 0 | 1 | Sentido de las agujas del reloj MÁXIMA VELOCIDAD |
| 1 | 1 | Sentido contrario al de las agujas del reloj MÁXIMA VELOCIDAD |
| 1 | 1 | Paro |

</center>

La técnica PWM (Pulse Width Modulation, modulación por anchura de pulso) consiste en EMULAR un valor determinado de tensión en un pin alternando los valores mínimo y máximo (0 V/5 V, normalmente) en el tiempo de modo que el equilibrio entre ambos de como resultado final la tensión buscada.

<center>

| Emulación de salidas analógicas por PWM. Imagen de Wikimedia Commons, obra de *Thewrightstuff* |
| :-: |
| Explicación PWM |

</center>

Esta técnica se puede utilizar en algunos pines (no en todos) de nuestras tarjetas microcontroladoras, utilizando el comando *analogWrite(pin,valor)* en el IDE de Arduino en lenguaje C++, siendo *pin* la patilla conectada a nuestro motor y *valor* un número entre 0 (0 V) y 255 (5 V)

## <FONT COLOR=#007575>**Control de velocidad en MasayloBlockly**</font>

Afortunadamente para el estudiante primerizo, con MasayloBlockly **no necesitaremos conocimiento alguno de PWM** para modificar la velocidad de los motores de nuestro Masaylo. En el bloque de opciones correspondiente, disponemos de una única pieza en la que podemos elegir el movimiento (adelante, atrás, izquierda, derecha) y su velocidad en %:

<center>

| Pieza de control de velocidad de movimiento en MasayloBlockly |
| :-: |
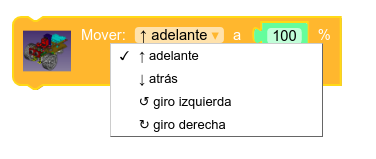
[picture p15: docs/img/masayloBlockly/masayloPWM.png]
Control de velocidad PWM
|  |

</center>

Simplemente haciendo click en la entrada de la pieza referida a la velocidad, podremos modificarla sin problemas a un valor entre 0 % y 100 %
Ello hace infinitamente más fácil programar la secuencia de movimientos de nuestro robot a velocidad controlada en nuestras primeras aproximaciones a la robótica educativa (si bien, obviamente, recomendamos al estudiante avanzado que se familiarice con el control PWM en el IDE de Arduino a través de *analogWrite()*);

## <FONT COLOR=#007575>**Objetivos de la práctica**</font>

Imitando al programa anterior, buscamos ahora la siguiente secuencia de movimientos:

+ Adelante a 100 % durante 3 segundos.
+ Giro a izquierda a 60 % durante 0.5 segundos.
+ Adelante de nuevo a 100 % durante 3 segundos.
+ Giro a derecha a 60 % durante 0.5 segundos.
+ Movimiento hacia atrás a 100 % durante 3 segundos.
+ Giro a izquierda a 60 % durante 1 segundo.
+ Fin de la secuencia.

### <FONT COLOR=#007575>**Programa: movimientos a velocidad variable**</font>

Procedemos de nuevo a crear un programa que cumpla con los objetivos marcados por la práctica, utilizando siempre la misma pieza y eligiendo en cada momento el sentido del movimiento y su potencia, tal y como indica la próxima ilustracion. (<font color=#0000FF>Nota: este programa está disponible en el botón de Ejemplos del menú principal, con el el título "Utiliza PWM para controlar la velocidad de movimientos del Masaylo").</font>

<center>

| Programa: secuencia de movimientos a velocidad variable |
|:-:|
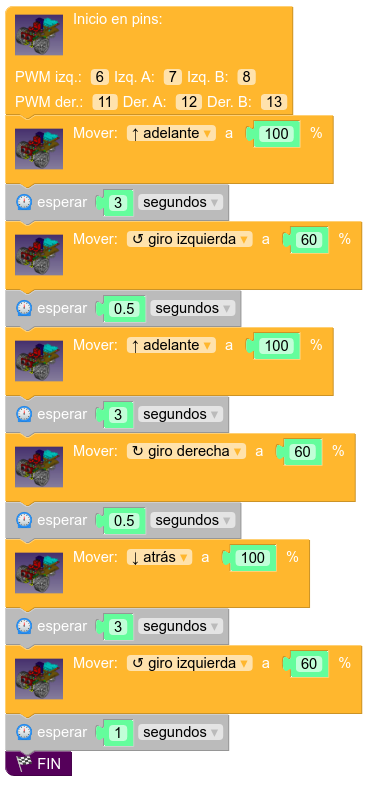
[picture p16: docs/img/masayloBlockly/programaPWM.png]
Programando con PWM
|  |

</center>

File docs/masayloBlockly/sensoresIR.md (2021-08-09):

# <FONT COLOR=#8B008B>Introducción a los bloques lógicos. Uso de sensores de infrarrojos</font>

Pasamos a continuación a familiarizarnos con el uso de los sensores de infrarrojos [FC-51](../../conexionado-pruebas/UNO/elementos/#sensores-de-infrarrojos), que pueden funcionar como sensores de obstáculos a pequeñas distancias o, como es el caso de Masaylo, para discriminar el color negro del blanco, lo que permite la creación de robots siguelíneas.

En esta práctica aprenderemos a inicializar los sensores de infrarrojos, también llamados IR, de Masaylo y utilizarlos para indicar si el robot detecta blanco o negro tanto a su derecha como a su izquierda a medida que éste avanza. Esta información se procesará y se ofrecerá al usuario a través del monitor del puerto serie, al estilo de la práctica anterior con el sensor de ultrasonidos.

<center>

| Práctica: lectura de sensores de infrarrojos a través del puerto  serie|
| :-: |
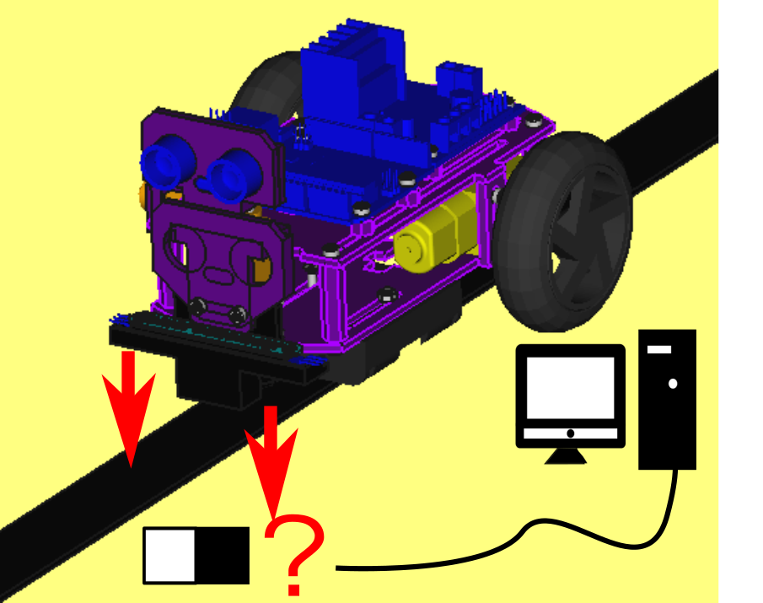
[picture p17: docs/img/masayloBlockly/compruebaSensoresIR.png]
|  |

</center>

## <FONT COLOR=#007575>**Presentación de nuevos bloques. Uso de la lógica en programación. Bloques si/si no**</font>

Para utilizar los sensores de infrarrojos en MasayloBlockly, seguimos la misma filosofía de trabajo que con el sensor de ultrasonidos: inicializar ambos sensores y recoger su lectura, aunque en este caso el abanico de piezas es algo más amplio:

| Icono| Función |
|:-:|---|
 | Inicio de sensores IR | Inicializar los sensores IR indicando sus pines a izquierda y derecha |
 | Negro en sensor izquierdo | Devuelve *verdadero* si pisa negro por la izquierda, y *falso* si pisa blanco |
 | Negro en sensor derecho | Devuelve *verdadero* si pisa negro por la derecha, y *falso* si pisa blanco |
 | Blanco en sensor izquierdo | Devuelve *verdadero* si pisa blanco por la izquierda, y *falso* si pisa negro |
 | Blanco en sensor izquierdo | Devuelve *verdadero* si pisa blanco por la derecha, y *falso* si pisa negro |

 Pero lo realmente importante en esta sección, es que por primera vez vamos a presentar de modo específico el trabajo con bloques lógicos, que si bien han aparecido ya en algún ejemplo de ampliación, no han sido aún tratados con cierta rigurosidad. Dichos bloques están agrupados en la opción **Lógica ** de la zona de bloques de opciones. Como creemos sinceramente en el concepto del aprendizaje significativo, en esta ocasión sólo vamos a trabajar con dos de los bloques de esta agrupación, que permitirán al lector comprender su papel en programación a través de su uso en esta práctica:

| Icono|Función |
|:-:|---|
 | Bloque SI | Bloque de control de flujo SI (si se cumple la condición, se ejecutará el bloque de comandos que se introduzca dentro de este bloque)|
 | Bloque de comparación | Compara dos elementos y devuelve *verdadero* si la condición de comparación se cumple (A *y* B, A *o* B, etc...) |

 El bloque SI, como algunas otras piezas disponibles en MasayloBlockly, incluye un pequeño icono azul de un engranaje en su parte superior izquierda que permite personalizarlo y añadirle funcionalidades (en el caso de la imagen, podemos crear bloques SI/SI NO, SI/DE LO CONTRARIO SI, etc...).

 <center>

| Algunos bloques incluyen un pequeño icono de personalización para complementar su significado|
| :-: |
| Icono del puerto serie |

</center>

## <FONT COLOR=#007575>**Objetivos de la práctica**</font>

Nuestro programa deberá cumplir los siguientes objetivos:

+ Inicializar el puerto serie del robot Masaylo estableciendo una velocidad estándar (9600 baudios).
+ Inicializar el robot Masaylo indicando, en su caso, los pines de control de motores.
+ Inicializar los sensores de infrarrojos, indicando la patilla a que están conectados (por defecto, los pines analógicos A0 y A1).
+ Realizar la lectura de ambos sensores.
+ Pasar el estado de ambos sensores por el puerto serie. Si ambos están en negro, lanzaremos el mensaje "Lado oscuro de la fuerza". Si ambos están en blanco, el mensaje será "La fuerza está en tí" (un guiño del programador a los lectores boomer).
+ Esperar un segundo y repetir el bucle.

Como el usuario pronto comprobará, la personalización del bloque lógico SI nos facilitará mucho el trabajo.

<center>

| Práctica: lectura de distancias a través del puerto serie |
|:-:|
| Leyendo el puerto serie |

</center>

### <FONT COLOR=#007575>**Programa: comprobación de sensores IR a través del puerto serie**</font>

Presentamos a continuación la solución a la práctica propuesta(<font color=#0000FF>Nota: este programa está disponible en el botón de Ejemplos del menú principal, con el título "Envía al puerto serie de tu ordenador la medición (blanco/negro) de tus sensores IR").</font>

<center>

| Programa: envío de la información de los sensores IR al puerto serie |
|:-:|
| Lectura de sensores IR, programa |

</center>

### <FONT COLOR=#007575>**Ejercicio de ampliación: programar un robot siguelíneas**</font>

La programación de siguelíneas (normalmente, una línea negra sobre un fondo blanco) es un clásico en la pedagogía de la Robótica Educativa. El uso de motores DC como los de Masaylo, baratos y accesibles de muy difícil control, complica bastante esta tarea. No obstante, presentamos a continuación una propuesta que puede suponer un buen punto de partida. Dependiendo de las distintas condiciones del circuito y del propio robot, será seguramente necesario adaptarla a dichas circunstancias, moderando las velocidades propuestas.

<center>

| Ejercicio de ampliación: Masaylo siguelíneas |
|:-:|
| Leyendo el puerto serie |

</center>

## <FONT COLOR=#007575>**Vídeo explicativo: uso del puerto serie para leer sensores de infrarrojos**</font>

<iframe width="560" height="315" src="https://www.youtube.com/embed/EG4oevlr-Z8" title="YouTube video player" frameborder="0" allow="accelerometer; autoplay; clipboard-write; encrypted-media; gyroscope; picture-in-picture" allowfullscreen></iframe>

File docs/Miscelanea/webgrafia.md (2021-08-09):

# <FONT COLOR=#8B008B>Webgrafía y bibliografía</font>

***

* [Wikipedia](https://es.wikipedia.org/wiki/Wikipedia:Portada)

* [Wiki de Keyestudio](https://wiki.keyestudio.com/Ks0172_keyestudio_UNO_with_Pin_Header_Interface)

* [Blog de Luis Llamas](https://www.luisllamas.es/)

* [Detalles sobre Arduino Nano CH340](http://actrl.cz/blog/index.php/2016/arduino-nano-ch340-schematics-and-details/)

* [Robótica con Arduino. Introducción a la programación de sistemas de control](https://serendipiaeditorial.com/robotica-con-arduino/) por Antonio Gómez García y María Dolores Nogueras Atance

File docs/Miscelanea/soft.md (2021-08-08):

# <FONT COLOR=#8B008B>Software utilizado</font>

* Dibujo 3D [FreeCAD 0.19](https://www.freecadweb.org/)
  
* Sistema operativo principal: [Ubuntu 20.04.4 LTS (Focal Fossa)](https://releases.ubuntu.com/20.04/)
  
* Paquete ofimático de referencia: [LibreOffice](https://es.libreoffice.org/)
  
* Libreria Material para MkDocs
  
* [Visual Studio Code](https://code.visualstudio.com/)
  
* Creación de GIF animados para Ubuntu [Peek](https://ubunlog.com/peek-gif-animados-ubuntu/)
  
* Sistema principal de capturas de pantalla: [Shutter 0.94](http://shutter-project.org)
  
* Dibujo 2D vectorial [Inkscape](https://inkscape.org/es/)

* Retoque de imágenes [GIMP](https://www.gimp.org/)

* Creación de GIF animado a partir de video con [FFMPEG](https://www.ffmpeg.org/) y [GIMP](https://www.gimp.org/)

* [IDE de Arduino](https://www.arduino.cc/en/software)

* [Masaylo Blockly releases](https://github.com/agomezgar/masayloBlockly/releases)

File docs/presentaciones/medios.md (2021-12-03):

# <FONT COLOR=#8B008B>Apariciones en medios de comunicación</font>

* Entrevista realizada por Onda Cero a Antonio:

<center>

[Enlace a la entrevista](https://www.ondacero.es/emisoras/castilla-la-mancha/ciudad-real/noticias/masaylo-primer-robot-educativo-open-source-origen-castellanomanchego_20211119619786d69e04bd0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)

</center>

* Publicado artículo el día 19 de noviembre en la revista digital EducarCLM: [Enlace al artículo](https://educarenclm.castillalamancha.es/content/masaylo-robot-open-source-de-origen-castellanomanchego)

* Publicado artículo el día 24 de noviembre en el Diario de la mancha, Lanza: [Enlace al artículo](https://www.lanzadigital.com/agenda-cultural/1053424-2/)

* Artículo el día 29 de noviembre de 2021 en [La Tribuna de Ciudad Real](https://www.latribunadeciudadreal.es/amp/noticia/za9c1ffb5-f010-8cd1-61c86735327f85b5/202111/un-simpatico-robot-en-el-ambito-educativo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)

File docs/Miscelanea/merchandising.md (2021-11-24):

# <FONT COLOR=#8B008B>Merchandising</font>
En este apartado simplemente te queremos mostrar algunas de las cosillas que hemos ido haciendo en torno al robot para utilizar en las presentaciones y que los asistentes a las mismas puedan llevarse un pequeño recuerdo.

* **Pegatina rectangular**

Creada con una imagen de Masaylo incluye un código QR que enlaza con la web del proyecto. Su aspecto es el de la imagen siguiente:

<center>

| Archivo fuente | Aspecto |
|---|:-:|
| [Formato svg](../img/merchandising/pegatina-rectangular/pegatina.svg) | Imagen de la pegatina |

</center>

* **Logotipo "I love Masaylo"**

Se crea el logotipo circular con la leyenda y se realizan pegatinas circulares con el mismo. A continuación tenemos la imágenes del mismo en distintas resoluciones.

<center>

| 200 px | 250 px | 300 px | 550 px |
|:-:|:-:|:-:|:-:|
| 200 px | 250 px | 300 px | 550 px |

</center>

* **Se imprime una primera tirada de camisetas como la de la imagen siguiente:**

<center>

Camiseta blanca con logo Masaylo

</center>

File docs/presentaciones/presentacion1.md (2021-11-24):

# <FONT COLOR=#8B008B>Primera presentación de MASAYLO-CRG en sociedad</font>

***Masaylo, el robot educativo Open Source nacido en Ciudad Real***

La tarde del próximo viernes 26 de noviembre de 2021 el IES Maestro Juan de Ávila de Ciudad Real albergará la presentación oficial a la comunidad educativa del robot Masaylo a cargo de D. Federico Coca y D. Manuel Hidalgo, colaboradores del Parque de las Ciencias de Granada, invitados por el profesor Antonio Gómez.

## <FONT COLOR=#007575>¿Qué es Masaylo?</font>
Masaylo es un robot impreso en 3D de carácter Open Source basado en el uso de la tarjeta microcontroladora Arduino, pieza central de las actividades de programación en la materia de Tecnología Robótica que se imparte en 4º de ESO en los centros públicos castellano-manchegos. Dicho robot fue diseñado originalmente por los profesores del IES Maestro Juan de Ávila de Ciudad Real Antonio Gómez y M.ª Dolores Nogueras, aunque ahora es el centro de un proyecto en el que colaboran profesores y expertos de la comunidad maker de varias ciudades de Castilla la Mancha y Andalucía.

Masaylo es un robot de carácter modular concebido para su uso en varias materias de Educación Secundaria, pero también de Educación Primaria. El profesor puede construir varias modalidades de este sistema, dependiendo de su experiencia previa y la complejidad de las actividades que desee desarrollar en el aula. Su diseño se centró desde el principio en ofrecer un montaje sencillo para el profesor o el alumno inexperto, así como escasas exigencias económicas, al ser montable en su mayor parte con materiales ya existentes normalmente en cualquier Aula-Taller de Tecnología.

## <FONT COLOR=#007575>¿Qué significa Open Source?</font>
El término Open Source (“Fuente abierta”, en castellano), es una filosofía basada en compartir diseños, programas y  montajes mediante una colaboración abierta. El movimiento Open Source sostiene que todo el mundo debería tener libre acceso al conocimiento, que al compartirse se extiende y enriquece más fácilmente.

Dentro de su concepción Open Source, todo lo que tiene que ver con Masaylo (diseño, fuentes para imprimir en 3D, instrucciones de montaje, programas…) se pone a disposición de profesores, alumnos y cualquier aficionado interesado en la Robótica para que puedan, no sólo aprender, sino modificar, compartir y distribuir todo lo relacionado con la Robótica a nivel de Educación Secundaria. El grupo de expertos maker que está detrás de este simpático robot mantiene de forma totalmente altruista toda una plataforma que incluye, por un lado, los ficheros que permiten construir todas las piezas utilizando una impresora 3D, como sus fuentes (los archivos de diseño originales que permiten realizar modificaciones a cada pieza), las bibliotecas de programación e incluso un entorno de desarrollo basado en el juego con piezas de tipo<FONT COLOencia de Ciudad Real.

Este tipo de actividades implican la colaboración de alumnos de 4º de ESO con experiencia previa en programación, que actúan como monitores de los niños más pequeños que acuden a estas actividades, enseñándoles a programar y experimentar con distintas magnitudes físicas utilizando robots como Masaylo. Esta concepción asegura un aprendizaje significativo tanto en los jóvenes como en los niños, al basarse en el descubrimiento y la experimentación, además del alto grado de motivación que presenta.

Masaylo ha participado también ya un par de veces en algunos talleres coordinados por el IES Maestro Juan de Ávila que se celebran en el Aula Hospitalaria del HGUCR, actividades éstas que permiten a los niños y niñas ingresados disfrutar por una tarde de actividades de formación y aprendizaje utilizando, de nuevo, el juego y el descubrimiento como herramientas.

En la actualidad se están diseñando también propuestas de formación para profesores de Educación Primaria interesados en proyectos STEAM que les permitiera crear sus propias actividades para sus respectivos grupos clase con autonomía y seguridad.

## <FONT COLOR=#007575>Club Robótica Granada: papel del Parque de las Ciencias en el proyecto</font>
Si bien Masaylo es de factura original ciudadrrealeña, varios integrantes del Club Robótica Granada, entidad fuertemente vinculada al Parque de las Ciencias de esta misma ciudad llevan más de un año participando muy activamente en el continuo rediseño y mejora de este robot desde el punto de vista de la comunidad educativa. Papel particularmente activo e importante en las actuales expectativas del proyecto tienen los dos ponentes de la presentación, D. Federico Coca y D. Manuel Hidalgo, viejos conocidos del mundillo maker y referencias de la robótica educativa a nivel nacional, así como otros profesores igualmente respetados en el ámbito de la educación y la impresión 3D, como D. Pedro Ruiz o D. Prudencio Luna.

El Club Robótica Granada no sólo está teniendo un importante papel en el diseño y desarrollo de este robot, sino que también impulsa de forma muy activa el reconocimiento del proyecto en el ámbito educativo andaluz. Masaylo se ha presentado como alternativa introductoria a la programación en la Escuela Técnica Superior de Ingenierías Informática y de Telecomunicación de la Universidad de Granada (ETSIIT) y en un futuro próximo se realizará una presentación oficial previa en Granada a la comunidad maker andaluza.

## <FONT COLOR=#007575>Ceremonia de presentación</font>
La ceremonia de presentación se realizará el próximo viernes 26 de abril, a las 17’30 h en el Salón de Actos del IES Maestro Juan de Ávila de Ciudad Real y con la colaboración de la Casa de la Ciencia de Ciudad Real.Actuarán como ponentes los desarrolladores de Masaylo D. Antonio Gómez, D. Federico Coca y D. Manuel Hidalgo. Al final de la ceremonia, la Casa de la Ciencia donará un robot Masaylo al Aula Hospitalaria del Hospital General Universitario de Ciudad Real.

## <FONT COLOR=#007575>Video de presentación</font>
A continuación puedes el video de presentación realizado por Antonio:
<iframe width="560" height="315" src="https://www.youtube.com/watch?v=V29Tz-neiIE" title="YouTube video player" frameborder="0" allow="accelerometer; autoplay; clipboard-write; encrypted-media; gyroscope; picture-in-picture" allowfullscreen></iframe>

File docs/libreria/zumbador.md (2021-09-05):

# <FONT COLOR=#8B008B>Sonidos y Masaylo (Zumbador)</font>
Masaylo incorpora un zumbador piezoeléctrico en su parte trasera, que nos servirá para reproducir sonidos y/o melodías.

<center>

| Zumbador |
|:|
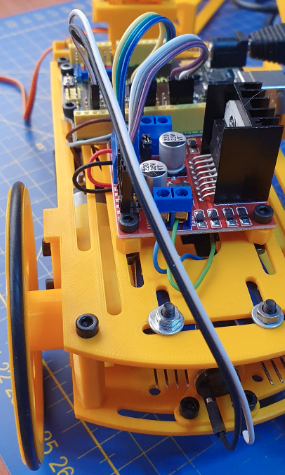
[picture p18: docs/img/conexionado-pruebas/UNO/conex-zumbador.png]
Zumbador
|  |

</center>

Las órdenes que tenemos para controlar el zumbador son las siguientes:

* ***objetoMasaylo.buzzer (pin buzzer)***: Configura el pin del buzzer. Si no pasas parámetros *objetoMasaylo.buzzer()*, pone los valores *objetoMasaylo.buzzer(1)*, por tanto habría que conectarlo al pin digital 1. Esta orden como es de configuración debe estar en el setup de nuestro programa. En el ejemplo *m.buzzer(1)*.
* ***objetoMasaylo.tono (frecuencia Hz, duración ms)***: emite un sonido en el zumbador configurado anteriormente, de una cierta frecuencia en Hz y duración en ms. En el ejemplo hay varias apliacciones como *m.tono (re,duracion)*, siendo re y duración constantes con valores enteros.

En el siguiente ejemplo (ejemplo 10 de la librería), se implementa una escala musical, creando constantes con las frecuencias de las notas de la escala, y constantes con la duración en ms de la nota y el retardo entre nota y nota.

~~~
#include <Masaylo.h>
Masaylo m;

const int do2 = 261;
const int re = 293;
const int mi = 329;
const int fa = 349;
const int sol = 392;
const int la = 440;
const int si = 493;
const int duracion = 500;
const int retardo = 100;

//no hay definiciones

void setup() {
  m.init();
  m.buzzer(1);

}

void loop() {
  m.tono(do2,duracion);
  delay(retardo);
  m.tono(re,duracion);
  delay(retardo);
  m.tono(mi,duracion);
  delay(retardo);
  m.tono(fa,duracion);
  delay(retardo);
  m.tono(sol,duracion);
  delay(retardo);
  m.tono(la,duracion);
  delay(retardo);
  m.tono(si,duracion);
  delay(retardo);

}
~~~

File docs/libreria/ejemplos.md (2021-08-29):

# <FONT COLOR=#8B008B>Ejemplos de Masaylo</font>
La librería de *Masaylo* incorpora una serie de ejemplos para poder probar el robot de forma directa, para ello vamos al menú Archivo > Ejemplos > Masaylo, y escogemos el ejemplo que nos interese.

<center>

| Ejemplos de *Masaylo* |
|:|
| Ejemplos de Masaylo |

</center>

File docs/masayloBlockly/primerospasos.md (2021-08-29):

# <FONT COLOR=#8B008B>Primeros pasos. Vista general de MasayloBlockly</font>

## <FONT COLOR=#007575>**Organización general del escritorio**</font>
El entorno de programación nos ofrece un escritorio dividido en cuatro grandes zonas:

+ Menú principal
+ Menú de opciones de programación (desplegará un submenú con distintos comandos según la opción elegida)
+ Zona principal de trabajo
+ Zona de traducción simultánea a C++ (desplegable o no a elección del usuario)

<center>

| Organización general del entorno de trabajo |
|:-:|
| Organización general |

</center>

## <FONT COLOR=#007575>**Menú principal**</font>

El menú principal ofrece las siguientes opciones, simbolizadas por iconos:

+ Gráfico o código **Modo gráfico/modo texto** Hacer click en este icono conmutará la barra de la zona de opciones de programación por el código en modo texto del algoritmo en el que estamos trabajando, a semejanza de lo que ocurre en la zona de traducción a C++, pero con la opción añadida de **poder editar el código generado** (no es recomendable para usuarios inexpertos), de modo que podamos introducir pequeñas variaciones a nuestro gusto.
+ Nuevo **Nuevo** abre un nuevo programa en blanco, reiniciando el flujo de trabajo (obviamente)
+ Ejemplos **Ejemplos** ofrece una selección de programas precargados, principalmente (en el momento de escribir estas líneas) para *Escornabot* y *Masaylo*
+ Cargar **Cargar programa** abre un programa guardado previamente. Los programas se guardan en formato XML con extensión *.block*
+ Guardar **Guardar programa** guarda nuestro trabajo en el directorio que indiquemos.
+ Configuracion **Preferencias** abre una subventana que nos permite, entre otras cosas, elegir los bloques de comandos de que queremos disponer y el idioma en que queremos trabajar (inglés, francés y español, aunque de momento sólo está garantizado el funcionamiento en español).
+ Monitor serie **Monitor puerto serie** abre una subventana con acceso al monitor del puerto serie.
+ Elección de tarjeta **Tarjetas disponibles** despliega una selección con las tarjetas que MasayloBlockly puede programar. <font color=#ff0000>**Importante: debe elegirse ANTES de empezar a programar, o grabar nuestro programa antes de cambiar de tarjeta, pues cualquier cambio provocará un borrado de la zona de trabajo**</font>
+ Elección de puerto USB **Elección de puerto USB** en este desplegable aparecerán los puertos USB disponibles. El usuario deberá indicar el puerto (normalmente, sólo habrá uno disponible) en que ha conectado la tarjeta Arduino.
+ Compilar **Compilar** Este botón dará la orden de iniciar el proceso de compilación del programa. Si todo es correcto, un mensaje de confirmación lo indicará. De lo contrario, se indicará qué fallo se ha cometido en un mensaje de pop-up. Este proceso no es obligatorio (basta con pinchar directamente en la opción de volcado), **pero es un hábito aconsejable**.
+ Cargar **Cargar** Una vez compilado (aunque, repetimos, no es un paso obligatorio), el siguiente paso es cargar el programa en el sistema de control (robótico o no) que hayamos conectado, previa selección del puerto USB. Al cabo de unos segundos, si se ha elegido correctamente el tipo de tarjeta utilizada y el puerto conectado, un mensaje de confirmación nos indicará que todo el proceso se ha realizado correctamente. Acabamos de volcar nuestro programa en la tarjeta Arduino.
+ Exportar **Exportar** Después de la compilación, se nos ofrece la oportunidad de guardar el programa compilado en binario en nuestro disco duro, con fines educativos o académicos.
+ Cargar **Cargar** Una vez compilado (aunque, repetimos, no es un paso obligatorio), el siguiente paso es cargar el programa en el sistema de control (robótico o no) que hayamos conectado, previa selección del puerto USB. Al cabo de unos segundos, si se ha elegido correctamente el tipo de tarjeta utilizada y el puerto conectado, un mensaje de confirmación nos indicará que todo el proceso se ha realizado correctamente. Acabamos de volcar nuestro programa en la tarjeta Arduino.
+ Deshacer **Deshacer** Deshace el último paso.
+ Rehacer **Rehacer** Rehace el último paso.
+ Snapshot **Tomar instantánea** Graba el programa en su versión gráfica en formato *.png en la carpeta que indique el usuario.
+ Traducir **Desplegar la zona de código** Abre o cierra la zona de traducción simultánea a C++ del programa que el usuario está generando.

## <FONT COLOR=#007575>**Menú de opciones de programación**</font>

De manera muy intuitiva, las distintas agrupaciones de comandos utilizables se ofrecen de manera ordenada en la zona izquierda de la pantalla. Dichos comandos pueden combinarse entre sí (es decir, si por ejemplo empezamos a trabajar con el bloque *Masaylo*, ello no quiere decir que no podamos utilizar piezas de la agrupación *Tiempo* o *Estructura*).

Hay dos modos de trabajo, elegibles desde el icono de Preferencias Configuracion, perfectamente configurables: *"Primerizo"* o *"Experto"*.  Cada uno de ellos nos permite elegir qué agrupaciones de piezas deseamos que aparezca en este menú. Podemos elegir todas las disponibles, o por el contrario podemos especificar sólo las que vamos a necesitar, al objeto de no enfrentarnos a un conjunto excesivo de opciones que pueda hacer el trabajo con este entorno demasiado confuso.
<center>

| Apariencia de la subventana de configuración |
|:-:|
| Ventana de preferencias Podemos elegir las distintas agrupaciones de comandos que queremos usar |
</center>

Obsérvese la presencia del botón **"Vaciar memoria caché"**. Si en algún momento la aplicación ofrece algún comportamiento extraño, o el usuario detecta corrupción o mal funcionamiento en la plantilla que organiza la apariencia de la aplicación, esta opción reseteará al programa a sus opciones de inicio.

## <FONT COLOR=#007575>**Zona principal de trabajo y espacio de traducción simultánea**</font>

En esta zona, inicialmente en blanco, iremos "encajando" las distintas piezas que representen las órdenes que queremos incluir en nuestro programa. 

A medida que vamos especificando las órdenes que queremos añadir al programa, y si hemos activado la zona de traducción simultánea con el icono Traducir, podremos acceder a la redacción del programa equivalente en lenguaje C++ que causaría el mismo efecto en el sistema de control si utilizaramos el IDE de Arduino.
<center>

| Espacio de traducción Simultánea a C++ | 
|:-:|
| Zona de traducción simultánea |

</center>

La zona de traducción simultánea <font color=FF0000>no es editable y por lo tanto no se puede modificar.</font>. Si queremos editar el código necesitaremos utilizar la herramienta Gráfico o código **Conmutación a modo texto**

El espacio de traducción simultánea incorpora, a su vez, dos herramientas útiles, representadas por sus respectivos iconos:

+ Guardar sketch**Guardar sketch** Permite guardar el sketch con extensión *.ino (la extensión estándar para el IDE de Arduino) en la carpeta señalada por el usuario con el nombre que desee.
+ Copiar sketch**Copiar sketch** Guarda el texto del sketch en memoria para utilizarlo en funciones de copia y pega en otros programas.

## <FONT COLOR=#007575>**Conmutación a modo texto**</font>

Como se ha explicado al principio de esta sección, el icono Gráfico o código tiene la función de desactivar el modo gráfico en el que trabaja, haciendo desaparecer el editor visual de código, tornándolo por el texto en lenguaje C++, al estilo de lo que se ve en la *zona de traducción simultánea*, pero con la característica particular de que el usuario puede editar y modificar el código (asumiendo el riesgo correspondiente).
<center>

| La conmutación a modo texto nos permite editar el código |
|:-:|
| Conmutación en modo texto |

</center>

## <FONT COLOR=#007575>**Nota interesante: estructura de un programa en Arduino**</font>

Si bien la meta de MasayloBlockly es permitir a sus usuarios programar sus propios robots/sistemas de control sin tener conocimiento de C++, esta información sobre los códigos *.ino sí que puede resultarle útil.

Por definición, cualquier código en Arduino tiene, COMO MÍNIMO (obviando la inclusión de librerías y la declaración de variables globales), dos funciones generales en las que se introducen las órdenes correspondientes a cada "pieza" de nuestra zona de trabajo:

+ **Función de configuración** ***(setup)***. En esta función introducimos todos los comandos referentes a la configuración (entradas, salidas, uso digital/analógico...) del sistema. <font color=#00FF00>**ESTA FUNCIÓN SE EJECUTA AL ARRANCAR EL PROGRAMA, UNA ÚNICA VEZ. AL LLEGAR A LA ÚLTIMA ORDEN, DA PASO A *loop()***</font> Para repetir esta función, habría que reiniciar la tarjeta o apagar y volver a encender el sistema.
+ **Función principal** ***(loop)***. Empieza después de ejecutarse la función ***setup()***. Esta función contiene los comandos generales que regirán el comportamiento de nuestro robot o sistema de control, gobernados por nuestra tarjeta controladora, sea ésta Arduino, ESP8266 o ESP32. <font color=#00FF00>**ESTA FUNCIÓN SE REPITE INVARIABLEMENTE. CADA VEZ QUE LLEGA A LA ÚLTIMA ORDEN QUE CONTIENE Y LA EJECUTA, VOLVERÁ DE NUEVO AL COMIENZO. ES LO QUE SE CONOCE COMO UN BUCLE**</font>. Dependiendo del programa, el conjunto de comandos que contiene esta función puede llegar a ejecutarse <ins>varias veces por segundo</ins>.

¿Qué implica esta filosofía de programación?. Que el usuario novel puede cometer un fallo como el del siguiente ejemplo: supongamos que queremos programar a un robot **Masaylo** para que al arrancar, vaya hacia adelante durante un segundo, y luego se pare. Eso supone dar tres órdenes (nos pararemos con más detalle sobre las características de este programa en próximas secciones). El problema es que dichas órdenes se estipulan (como puede verse en la ilustración) dentro de la función *loop()*. Según lo que acabamos de explicar, ello supone que al llegar a la última orden **(ALTO)**, el bucle se reiniciará, ejecutando inmediatamente de nuevo la orden **ADELANTE**, que obviamente anula el paro de los motores. El resultado práctico es que nuestro Masaylo empezará un movimiento hacia adelante continuo, sin que podamos percibir que el robot se detenga nunca.

<center>

| Ejemplo de programa con resultado inesperado debido a la repetición en bucle de las órdenes |
|:-:|
| Programa en bucle con resultado inesperado |

</center>

¿Significa ello que no podemos crear programas que se ejecuten una única vez?. No, por supuesto. Para ello podemos utilizar una pieza especial denominada <font color=#00FFA9>FIN</font>, disponible en el bloque **Arduino** en el modo Primerizo, y en el bloque **Estructura** en el modo Experto, que allá donde la pongamos (nota para usuarios más expertos) insertará un bucle eterno de tipo *while(true);*, paralizando a partir de ahí la ejecución del resto del código.
<center>

| Ejecución de un programa una única vez con la pieza Fin |
|:-:|
| Interrupción del bucle loop |

</center>

## <FONT COLOR=#007575>**Preparándonos para crear nuestro primer programa**</font>

Esta introducción, aunque mínima, debería ser suficiente para que el usuario se mueva con cierta soltura por todas las características que ofrece este entorno gráfico de programación. Como hemos comentado ya aún tenemos pendiente un último paso, que es el de la [instalación de librerías](../instalacion), y que se llevará a cabo una vez creemos nuestro primer programa y tratemos de compilarlo o volcarlo directamente en el micro de nuestro robot.

## <FONT COLOR=#007575>**Vídeo explicativo: características generales de MasayloBlockly**</font>

<center>
<iframe width="560" height="315" src="https://www.youtube.com/embed/Z_kqKgx22EM" title="YouTube video player" frameborder="0" allow="accelerometer; autoplay; clipboard-write; encrypted-media; gyroscope; picture-in-picture" allowfullscreen></iframe>
</center>

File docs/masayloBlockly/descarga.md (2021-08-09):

# <FONT COLOR=#8B008B>Instalación de MasayloBlockly</font>

A lo largo de las próximas secciones presentaremos una pequeña introducción a **MasayloBlockly**, un software de programación de sistemas de control basados en Arduino, ESP8266 y ESP32. Si bien no es una herramienta imprescindible para programar el robot Masaylo, sí que puede suponer una ayuda para el lego que desea introducirse a este mundillo de la Robótica Educativa y que no está familiarizado con el IDE de Arduino que se utiliza normalmente en estos menesteres.

<center>

 Logo de MasayloBlockly 

</center>

A grandes rasgos, la utilidad de MasayloBlockly es ofrecer al usuario un entorno gráfico en el que puede arrastrar distintas "piezas" de puzzle, cada una de las cuales supone un comando, función, lectura de parámetro, etc... en el lenguaje C++ que utiliza el IDE de Arduino para programar sus tarjetas. Esta filosofía de trabajo permite crear programas sencillos (o complejos) y volcarlos en robots o sistemas de control basados en estos tipos de microcontrolador. Como se verá en los próximos apartados, se trata de un proceso muy intuitivo y amigable, pero extremadamente potente.
<center>

| Zonas de trabajo de MasayloBlockly|
|:-:|
| Zonas de trabajo de MasayloBlockly |

</center>

## <FONT COLOR=#007575>**Origen de MasayloBlockly**</font>

MasayloBlockly ha sido diseñado por [Antonio Gómez](https://twitter.com/antoniotecnocr) y [María Dolores Nogueras Atance](https://casadelaciencia.es/equipo/), ambos profesores de Tecnología en Educación Secundaria, con el objetivo de facilitar al máximo el trabajo con robots educativos como Masaylo, [OttoDIY](https://wikifactory.com/+OttoDIY/otto-diy/files), [OttoDIY versión Humanoide](https://wikifactory.com/+OttoDIY/humanoid/files) y [Escornabot](https://escornabot.com/es/index), entre otros.

Según la experiencia en taller de ambos profesores a lo largo de los años, la programación directa de este tipo de sistemas (léase lenguaje C++ en el caso del IDE de Arduino), se hace muy difícil y confusa para alumnos de cursos inferiores a 4º de ESO. Esta herramienta pretende posibilitar la programación directa de sistemas de control que trabajen con sensores y actuadores simples a los alumnos más jóvenes de nuestro sistema educativo, separando este ámbito de trabajo del aprendizaje directo de lenguajes de programación complejos como C++, que implica un pensamiento abstracto y una madurez intelectual asociada a niveles superiores.
Apilando piezas de puzzle al más puro estilo Scratch, el alumnado (o el simple aficionado) puede construir algoritmos sencillos explicando al ordenador cómo pretende que trabaje el sistema de control que está programando (robótico o no) sin un conocimiento directo del lenguaje implicado.

Este software es una adaptación de [Blocklino](https://github.com/fontainejp/blocklino), obra de [Jean Philippe Fontaine](https://github.com/fontainejp), que a su vez es una adaptación/integración/mejora de trabajos como [BlocklyDuino](https://github.com/BlocklyDuino/BlocklyDuino) o [ArduBlockly](https://github.com/carlosperate/ardublockly). Esta es la magia del software libre. La colaboración y la libre difusión del conocimiento es lo que está impulsando con tanta intensidad el conocimiento y el enriquecimiento del mundo académico estos últimos años.

El motor gráfico de la aplicación está basado en la librería en JavaScript [Google Blockly](https://github.com/google/blockly), que permite insertar un editor visual de código en webs y apps móviles.

## <FONT COLOR=#007575>**Descarga e instalación del software**</font>

MasayloBlockly, como sus antecesores, es software libre con licencia [Creative Commons Zero v1.0 Universal](https://github.com/agomezgar/masayloBlockly/blob/master/LICENSE.md). En su [repositorio](https://github.com/agomezgar/masayloBlockly) está disponible por completo el código fuente que integra este entorno de programación. En su apartado [*releases*](https://github.com/agomezgar/masayloBlockly/releases) están disponibles para descargar todas las versiones que sus creadores han ido liberando a lo largo del ciclo de vida de este software.
###[Aquí están disponibles para descarga las distintas versiones para Windows y Linux de MasayloBlockly](https://github.com/agomezgar/masayloBlockly/releases)

Normalmente, cada versión de MasayloBlockly está disponible para Windows 10 (64 bits), Ubuntu (64 bits), así como una versión de 32 bits para versiones anteriores de Windows, que trata de dar respuesta a la limitación de medios informáticos en algunos centros educativos. En cada caso, se ofrece una versión portable (formato appImage en Linux, archivo *.exe en Windows), un instalador para Windows y la carpeta comprimida para Linux.

<center>

| Hay distintas versiones de MasayloBlockly para diversos sistemas operativos |
|:-:|
| Versiones de MasayloBlockly Hay distintas versiones de MasayloBlockly disponibles para descargar |

</center>
En Linux hay que proporcionar permisos de ejecución al archivo appImage descargado, si optamos por esta posibilidad. Si preferimos descargarnos la carpeta completa, hay que ejecutar el archivo *masaylo* , preferiblemente por consola:

> usuario@equipo:~/Descargas/masayloBlockly$/.masaylo

Si todo va bien, la aplicación arrancará, mostrándonos una pantalla parecida a ésta:
<center>

| Apariencia de la aplicación en el primer arranque |
|:-:|
| Primera pantalla |

</center>
Queda aún pendiente la [instalación de librerías](../instalacion) que MasayloBlockly necesita para poder volcar el código en C++. No obstante, es aconsejable primero hacer un pequeño recorrido sobre sus características para que el usuario adquiera cierta seguridad en su utilización. Demos, pues, nuestros primeros pasos por este entorno.

## <FONT COLOR=#007575>**Vídeo explicativo: descarga e instalación de MasayloBlockly**</font>

<center>

<iframe width="560" height="315" src="https://www.youtube.com/embed/XZpgklcsbIM" title="YouTube video player" frameborder="0" allow="accelerometer; autoplay; clipboard-write; encrypted-media; gyroscope; picture-in-picture" allowfullscreen></iframe>

</center>

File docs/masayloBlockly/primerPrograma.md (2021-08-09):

# <FONT COLOR=#8B008B>Mi primer programa: movimientos básicos de Masaylo</font>

## <FONT COLOR=#007575>**Objetivos de la práctica**</font>

Muy bien. Ya hemos instalado nuestra aplicación, hemos instalado nuestras librerías y archivos de características de microcontroladores y estamos preparados para realizar nuestra primera prueba práctica. Para ello, vamos a programar a nuestro Masaylo para que haga **una única vez** (ya explicamos en la sección [Primeros pasos](primerospasos.md) cómo introducir un punto de interrupción de programa con la tecla "Fin") la siguiente secuencia de movimientos:

+ Moverse hacia adelante durante 3 segundos.
+ Girar hacia la izquierda 0.5 segundos.
+ Mover hacia adelante otros 3 segundos.
+ Girar hacia la derecha durante 0.5 segundos.
+ Ir hacia atrás 3 segundos.
+ Girar hacia la izquierda durante 1 segundo.
+ Paro. Fin del programa.

## <FONT COLOR=#007575>**Creación del programa en MasayloBlockly**</font>

Todas las piezas que vamos a utilizar las obtendremos de los siguientes bloques de opciones:

+ Masaylo para todos los comandos de movimiento del robot
+ Masaylo (como es obvio) para los comandos de espera
+ Masaylo (en modo primerizo si utilizamos el icono de preferencias del menú principal) para insertar la pieza "Fin" que introducirá el punto de interrupción del programa.

### <FONT COLOR=#007575>**Inicialización de un robot en Arduino**</font>

Por norma, todos los programas referidos a robots en Arduino y derivados implican el uso de librerías especializadas inspiradas en la filosofía de la programación orientada a objetos (POO) que exigen, al principio del programa, que se declare e inicialize un objeto de la clase que integra las características del robot referido. En todos los casos, la pieza referida a la inicialización del robot estará siempre al principio del desplegable de cada bloque de opciones:

| Icono|Función |
|---|---|
 | Escornabot | Inicializar un [Escornabot](https://escornabot.com/es/index) |
 | OttoDIY | Inicializar un [OttoDIY](https://wikifactory.com/+OttoDIY/otto-diy/files) |
 | OttoHumanoid | Inicializar un [Otto Humanoide](https://wikifactory.com/+OttoDIY/humanoid/files) |
  | Masaylo estándar | Inicializar un robot Masaylo estándar|
  | Masaylo personalizado | Inicializar un Masaylo que no lleva las conexiones por defecto que se aconsejan en la documentación (esto es, está personalizado)|

### <FONT COLOR=#007575>**Programa: movimientos básicos**</font>

Procedemos, pues, a crear nuestro programa con el objetivo de lograr los objetivos estipulados. Por esta vez, no nos pararemos a matizar la velocidad a la que queremos hacer cada movimiento (para lo que, obviamente, también disponemos del correspondiente comando en formato gráfico) y nos limitaremos a crear el siguiente programa (<font color=#0000FF>Nota: este programa está disponible en el botón de Ejemplos del menú principal, con el el título "Aprende a controlar los movimientos básicos del robot Masaylo").</font>

<center>

| Mi primer programa: movimientos básicos |
|:-:|
| Mi primer programa |

</center>

## <FONT COLOR=#007575>**Vídeo explicativo: mi primer programa: secuencia de movimientos simples**</font>

<iframe width="560" height="315" src="https://www.youtube.com/embed/RyXe9oCyVEE" title="YouTube video player" frameborder="0" allow="accelerometer; autoplay; clipboard-write; encrypted-media; gyroscope; picture-in-picture" allowfullscreen></iframe>

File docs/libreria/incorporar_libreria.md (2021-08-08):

# <FONT COLOR=#8B008B>Incorporar la librería en un programa</font>
El siguiente paso es que las instrucciones para controlar nuestro robot, que están dentro de la librería, estén disponibles, por eso debemos incluir la librería en nuestro código, para ello: Menú Programa > Incluir librería > Masaylo

<center>

| Escoger la librería una vez instalada |
|:|
| Escoger librería |

</center>

En el código aparecen en las dos primeras líneas:
~~~
#include <Encoder.h>
#include <Masaylo.h>
~~~
Estas dos líneas de código son las que incorporan la librería a nuestro programa para poder controlar el robot.

<center>

| Librería incorporada |
|:|
| Librería incorporada |

</center>

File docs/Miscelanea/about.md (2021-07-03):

# <FONT COLOR=#8B008B>Autores</font>

Este proyecto es una colaboración entre distintos miembros de [Club Robotica Granada](https://clubroboticagranada.github.io/) y [Antonio Gómez García](https://serendipiaeditorial.com/robotica-con-arduino/).

<center>

| Club Robotica Granada | Federico Coca  | Antonio Gómez | Pedro Ruiz |
|:|:|:|:|
| Club Robotica Granada | Federico Coca | Antonio Gómez | Pedro Ruiz |
| [GitHub](https://github.com/clubroboticagranada)  | [GitHub](https://github.com/fgcoca) |[GitHub](https://github.com/agomezgar) | [GitHub](https://github.com/pedroruizf) |
| [Twitter](https://twitter.com/clubroboticagra) | [Twitter](https://twitter.com/fgcoca) | [Twitter](https://twitter.com/antoniotecnocr) | [Twitter](https://twitter.com/pedroruizf) |

</center>

<center>

| Manuel Hidalgo | Prudencio Luna | José Luis Bueno | Maribel Ruiz |
|:|:|:|:|
| Manuel Hidalgo | Prudencio Luna | José Luis Bueno | Maribel Ruiz |
| [GitHub](https://github.com/leobotmanuel) | [GitHub](https://github.com/plunax) | --- | [GitHub](https://github.com/mruiz54) |
| [Twitter](https://twitter.com/leobotmanuel) | [Twitter](https://twitter.com/plunax) | [Twitter](https://twitter.com/jbtecno) | --- |

</center>

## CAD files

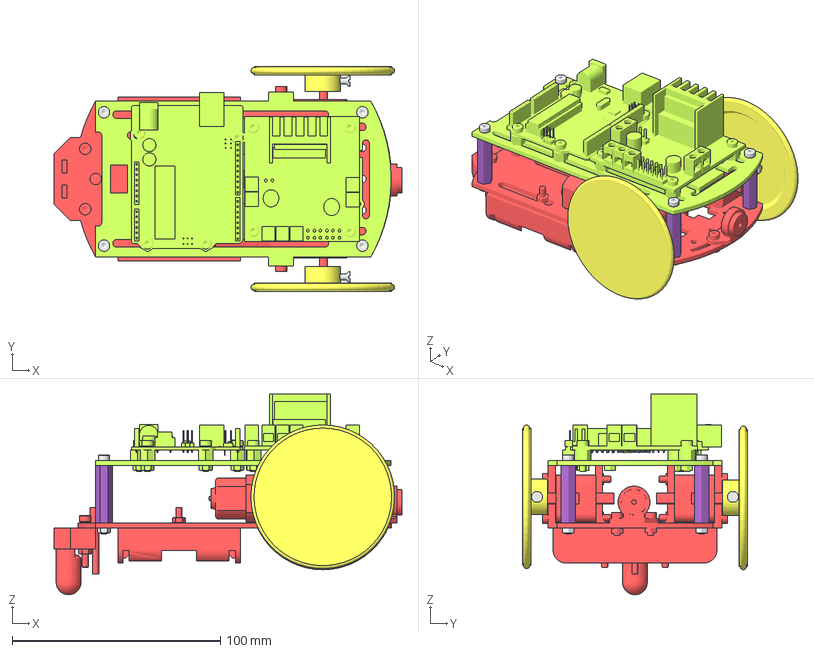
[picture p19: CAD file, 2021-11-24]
docs/ensamblesFreeCAD/src/ensamble3.FCStd
167.0 x 108.0 x 96.2 mm
separadorM3x028-004
separadorM3x031
separadorM3x028-008
separadorM3x028-009
M3x35-Screw
M3x35-Screw001
M3x35-Screw002
M3x35-Screw003
M3-Nut034
M3-Nut035
M3-Nut036
M3-Nut037
ruedaDerecha
ruedaIzquierda
M3-Nut055
M3-Nut056
M3x12-Screw002
M3x12-Screw003

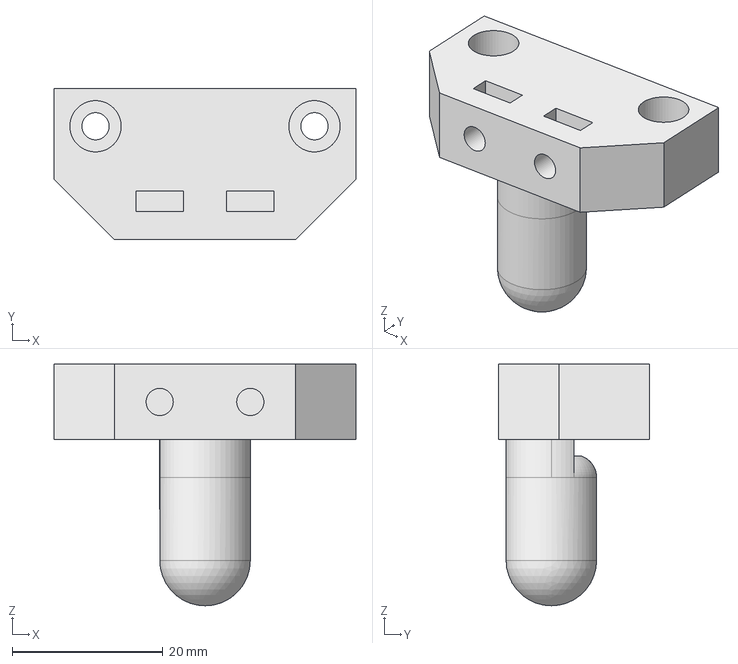
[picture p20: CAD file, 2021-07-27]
docs/img/3D-media-precision/src/soporte-ballcaster-media.FCStd
40.0 x 20.0 x 32.0 mm

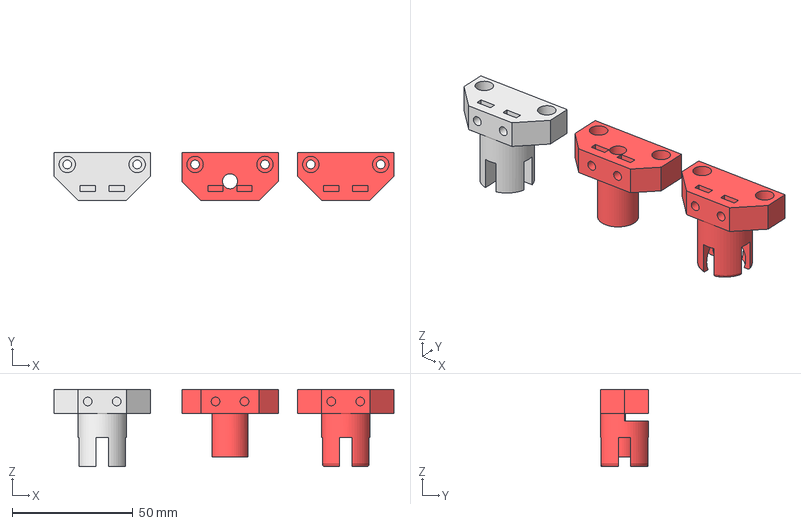
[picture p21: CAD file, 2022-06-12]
docs/img/3D/modificados/src/soportes-ballcaster-modificados.FCStd
141.0 x 20.0 x 32.0 mm
ballcaster-cabeza-perdida-src
ballcaster-canica-src

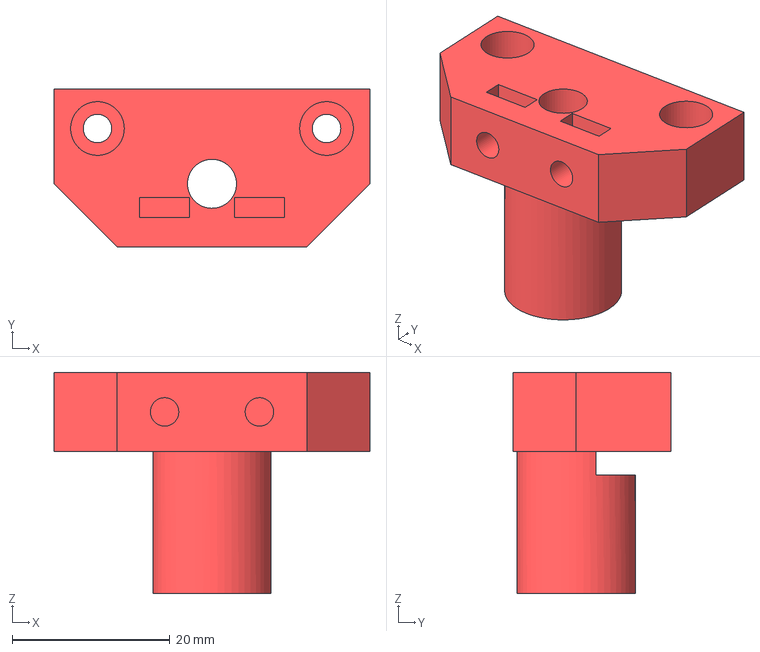
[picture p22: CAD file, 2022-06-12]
docs/img/3D/modificados/step/soporte-ballcaster-cabeza-perdida.step
40.0 x 20.0 x 28.0 mm

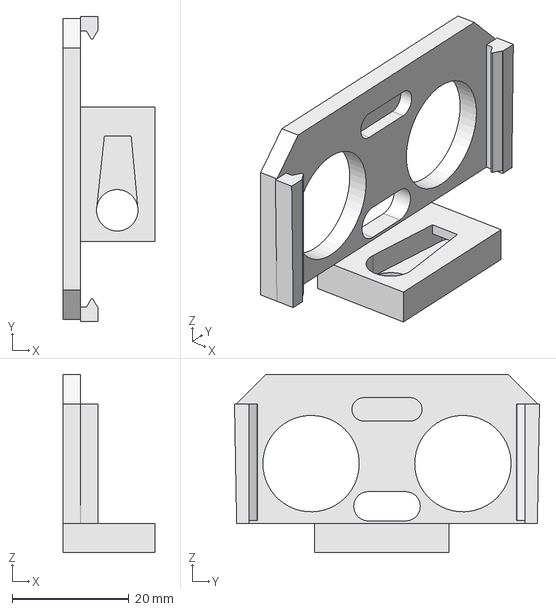
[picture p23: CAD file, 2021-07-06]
docs/img/3D/src/soportes-ultrasonidos.FCStd
15.8 x 52.2 x 30.6 mm

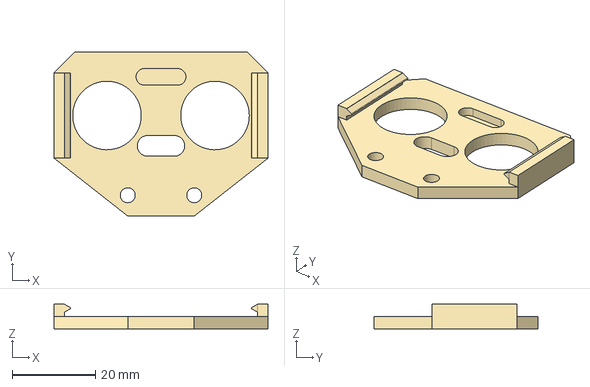
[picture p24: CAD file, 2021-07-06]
docs/img/3D/step/ultrasonidos-fijo.step
51.5 x 39.5 x 6.00 mm

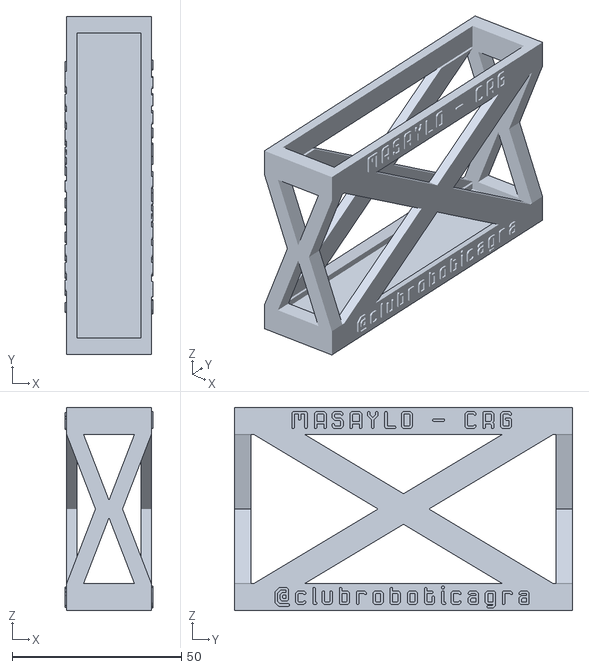
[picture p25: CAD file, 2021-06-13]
docs/img/3D/stl/soporte-para-pruebas.stl
26.0 x 100.0 x 60.0

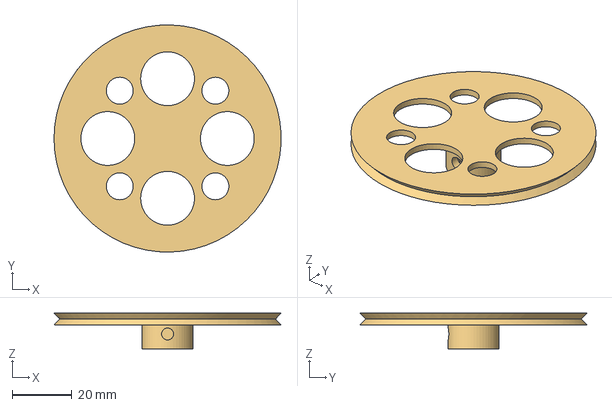
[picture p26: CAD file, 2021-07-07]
docs/img/3D-media-precision/src/ruedas-hueco-eje-mayor.FCStd
75.9 x 76.0 x 12.0 mm

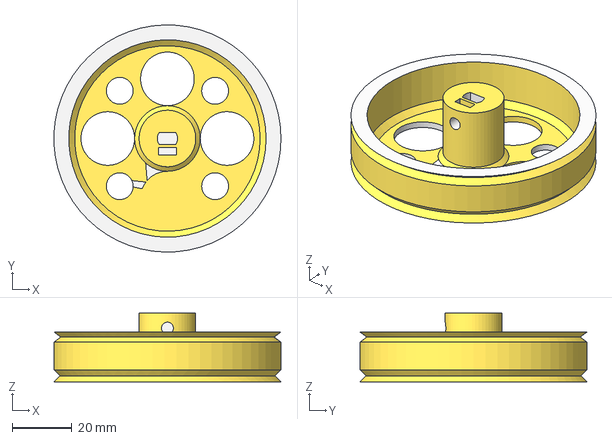
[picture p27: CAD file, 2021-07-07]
docs/img/3D-media-precision/step/rueda-dos-juntas-ancha-eje-motor-mayor.step
76.1 x 76.2 x 23.0 mm

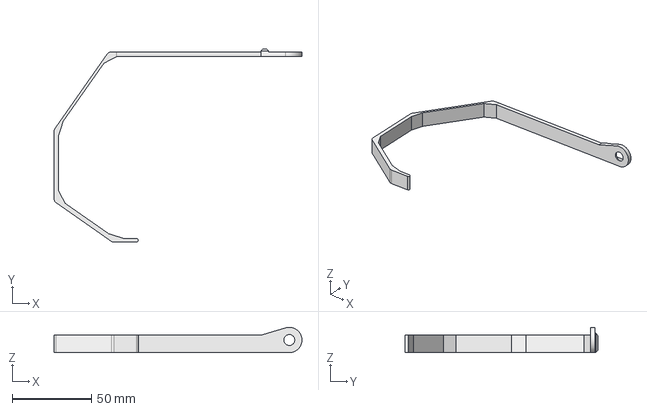
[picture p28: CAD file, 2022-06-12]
docs/img/3D/modificados/src/brazo-modificado-src.FCStd
156.4 x 122.0 x 16.0 mm

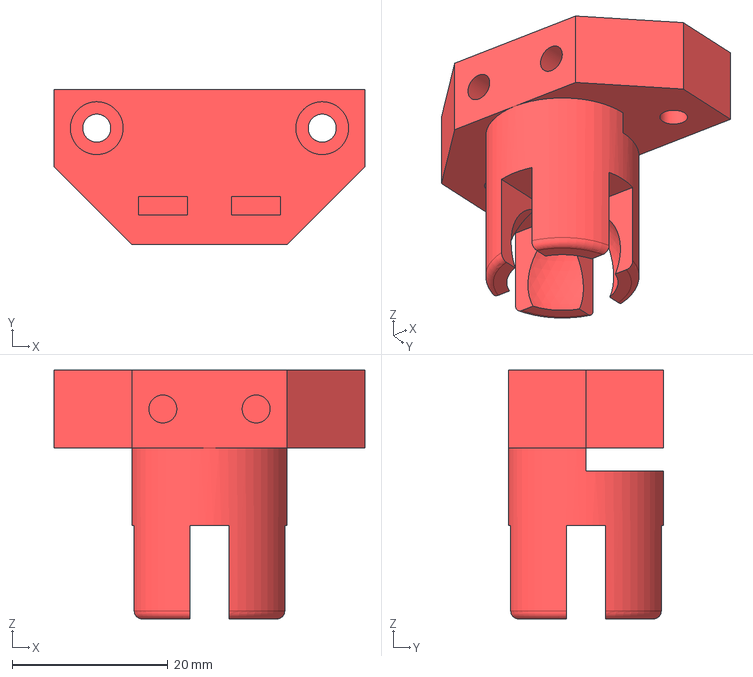
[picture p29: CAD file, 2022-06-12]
docs/img/3D/modificados/step/soporte-ballcaster-canica.step
40.0 x 20.0 x 32.0 mm

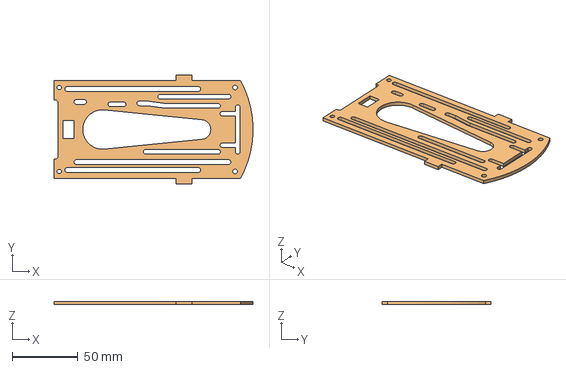
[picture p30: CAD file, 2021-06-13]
docs/img/3D/src/plataforma-superior-src.FCStd
151.7 x 83.4 x 2.50 mm
plataforma-superior-copy

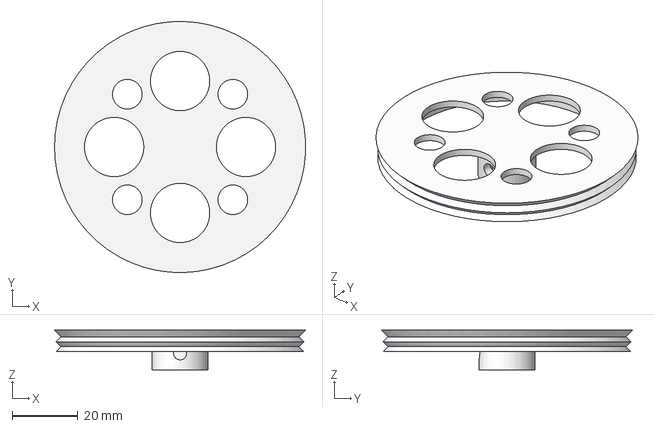
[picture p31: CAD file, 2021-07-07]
docs/img/3D-media-precision/step/rueda-dos-juntas-eje-motor-mayor.step
76.1 x 76.1 x 12.0 mm

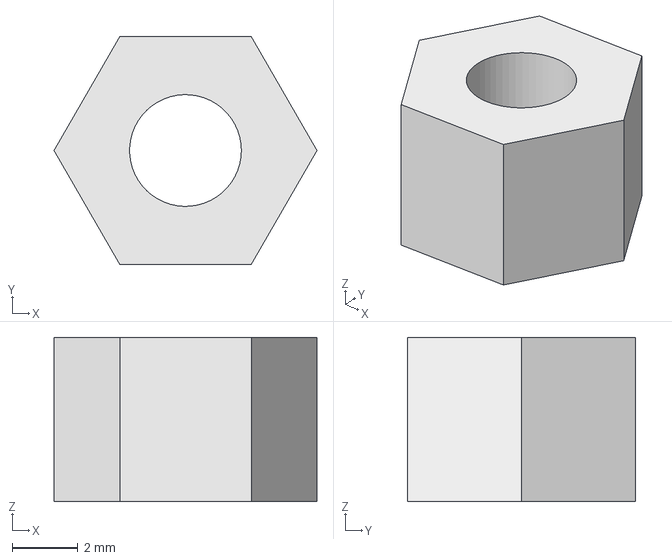
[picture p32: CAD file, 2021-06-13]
docs/img/3D/src/separadores-src.FCStd
8.00 x 6.93 x 5.00 mm

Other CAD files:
docs/img/3D-media-precision/step/soporte-ballcaster-media.step
docs/img/3D/step/ultrasonidos-movil.step
docs/img/3D/modificados/step/brazo-modificado.step
docs/img/3D/step/base-servo.step
docs/img/3D-media-precision/step/rueda-una-junta-eje-motor-mayor.step
docs/img/3D-media-precision/stl/rueda-dos-juntas-ancha-eje-motor-mayor.stl
docs/img/3D-media-precision/stl/rueda-dos-juntas-eje-motor-mayor.stl
docs/img/3D-media-precision/stl/rueda-una-junta-eje-motor-mayor.stl
docs/img/3D-media-precision/stl/soporte-ballcaster-media.stl
docs/img/3D/modificados/stl/brazo-modificado.stl
docs/img/3D/modificados/stl/soporte-ballcaster-cabeza-perdida.stl
docs/img/3D/modificados/stl/soporte-ballcaster-canica.stl
docs/img/3D/src/base-servo-src.FCStd
docs/img/3D/src/brazo-src.FCStd
docs/img/3D/src/disco-encoder.FCStd
docs/img/3D/src/plataforma-base-src.FCStd
docs/img/3D/src/ruedas.FCStd
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

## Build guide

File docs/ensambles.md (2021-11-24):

# <FONT COLOR=#8B008B>Ejemplos de ensamblajes del robot</font>
A continuación están los enlaces a los archivos fuente de ensamblado con FreeCAD y a sus correspondientes animaciones.

* **Motores, portapilas, buzzer y ballcaster**

<center>

| Fuente | Animación |
|:-:|:-:|
| [Ensamble motores, portapilas, buzzer y ballcaster](../ensamblesFreeCAD/src/ensamble1.FCStd) | Animación del ensamble |

</center>

* **Driver L298 y placa UNO**

<center>

| Fuente | Animación |
|:-:|:-:|
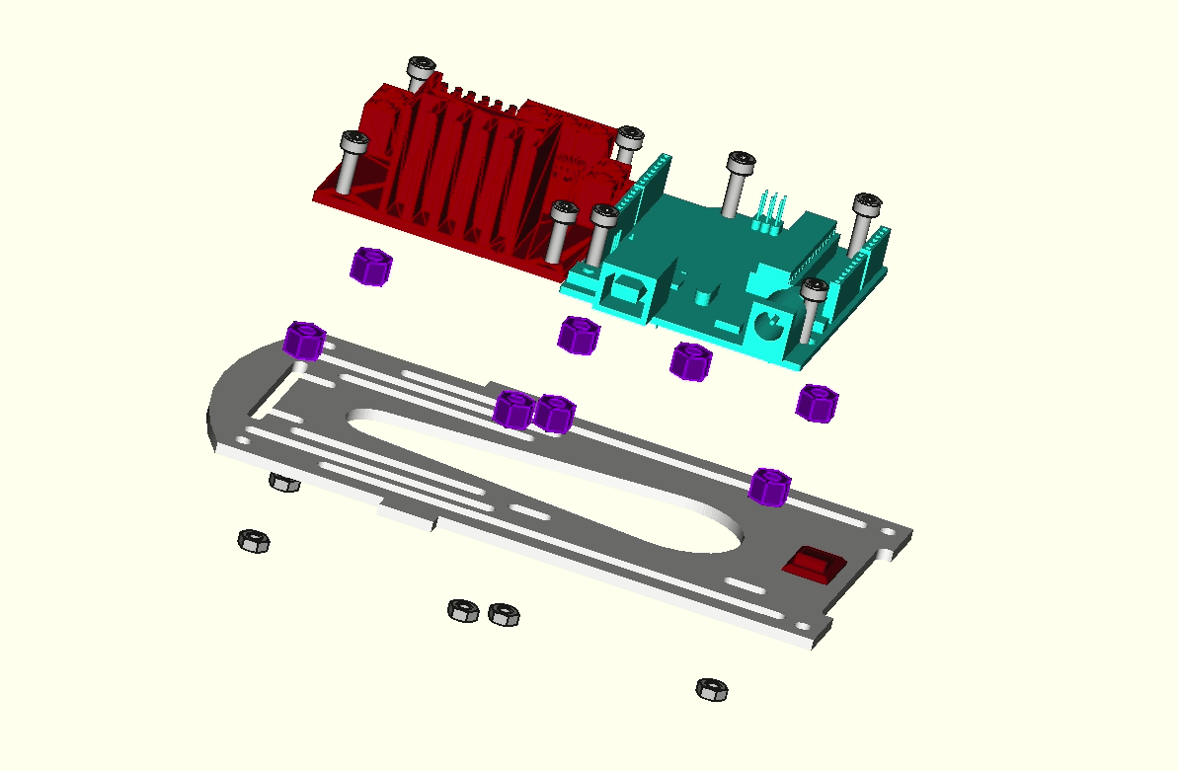
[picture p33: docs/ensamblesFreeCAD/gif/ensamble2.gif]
Animación del ensamble
| [Ensamble L298 y UNO](../ensamblesFreeCAD/src/ensamble2.FCStd) |  |

</center>

* **Plataformas inferior y superior y ruedas**

<center>

| Fuente | Animación |
|:-:|:-:|
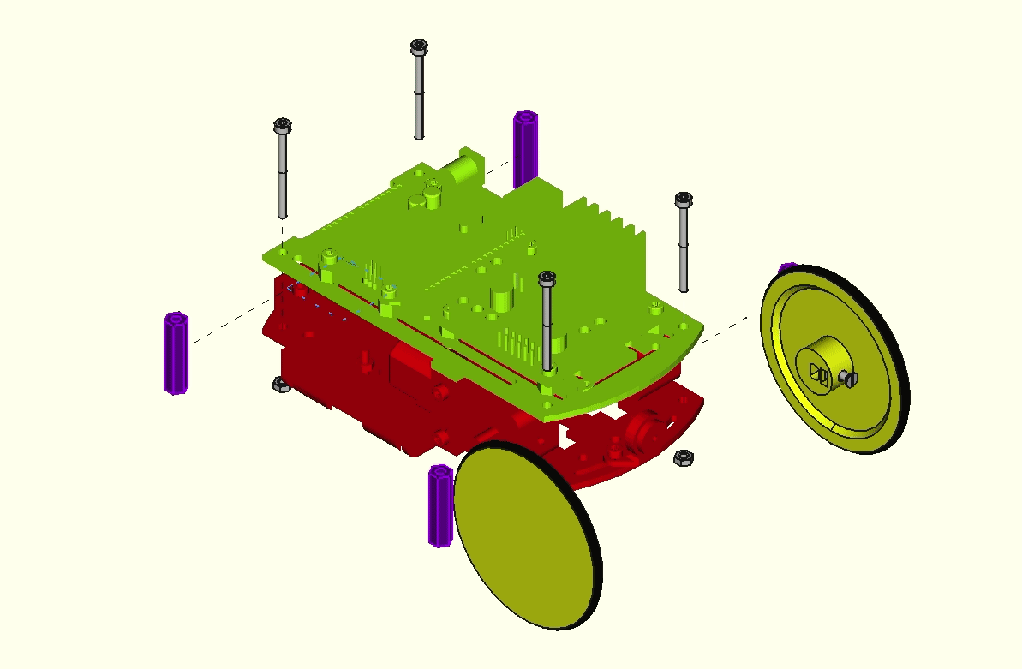
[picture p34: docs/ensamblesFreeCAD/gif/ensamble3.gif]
Animación del ensamble
| [Ensamble Plataformas y ruedas](../ensamblesFreeCAD/src/ensamble3.FCStd) |  |

</center>

* **Sensor de infrarrojos**

<center>

| Fuente | Animación |
|:-:|:-:|
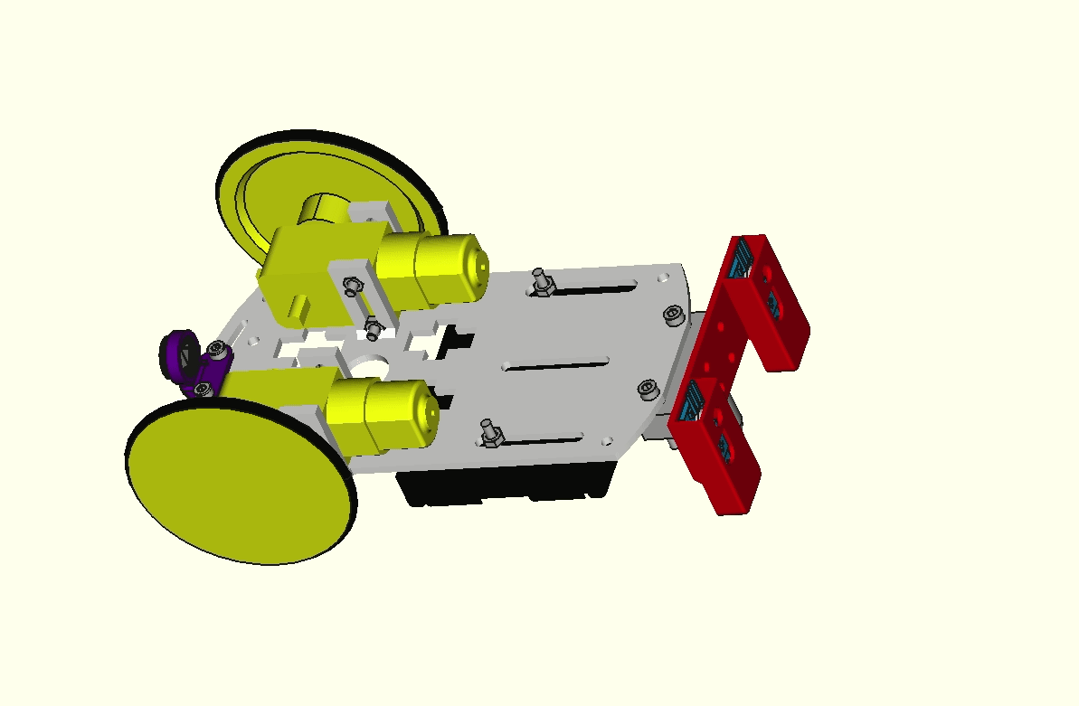
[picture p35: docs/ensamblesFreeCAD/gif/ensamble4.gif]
Animación del ensamble
| [Ensamble sensor IR](../ensamblesFreeCAD/src/ensamble4.FCStd) |  |

</center>

Si quieres verlos en FreeCAD debes tener instalado el banco de trabajo **Exploded Assembly**

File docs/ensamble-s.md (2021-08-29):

# <FONT COLOR=#8B008B>Materiales necesarios y ensamblado plataforma superior</font>

***

## <FONT COLOR=#007575>**Plataforma superior**</font>
En esta pieza es donde vamos a colocar el servo para el brazo aparta objetos y los elementos de electrónica correspondientes a cada versión. El brazo lo podemos colocar tanto a la derecha como a la izquierda y recordemos que de forma opcional podemos poner también el soporte del zumbador o un sensor fijo de ultrasonidos. El aspecto de la pieza denominada plataforma superior lo vemos en la imagen siguiente.

<center>

| Plataforma superior en fase de diseño | Plataforma superior |
|:-:|:-:|
| Plataforma superior en fase de diseño | Porta HC-SR04 fijo impreso |

</center>

## <FONT COLOR=#007575>**Brazo aparta objetos**</font>
Se trata de una especie de gancho accionado por un servo SG-90 que nos va a servir para apartar objetos detectados por el sensor HC-SR04 del camino o trayectoria a seguir. La idea es que el brazo estará normalmente replegado hacia las ruedas y que, cuando vamos siguiendo una línea o resolviendo un laberinto o simplemente desplazándonos con el robot y detectamos enfrente un objeto del tamaño de una lata de refresco, se accione el brazo para envolverlo, el robot realice un giro arrastrando el objeto fuera de su trayectoria, posteriormente deshaga el giro, retraiga el brazo y continue su camino. El aspecto del brazo en fase de diseño e impreso lo vemos en la imagen siguiente.

<center>

| Brazo en fase de diseño | Brazo impreso |
|:-:|:-:|
| Brazo en fase de diseño | Brazo impreso |

</center>

| **P7. Brazo aparta objetos** | Imágenes |
|---|:-:|
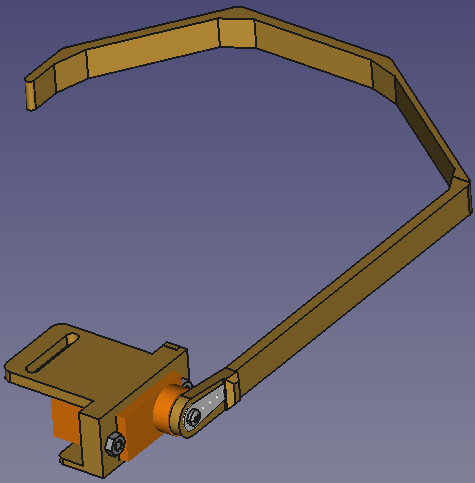
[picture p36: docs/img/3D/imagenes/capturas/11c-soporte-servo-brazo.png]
Brazo con servo en fase de diseño
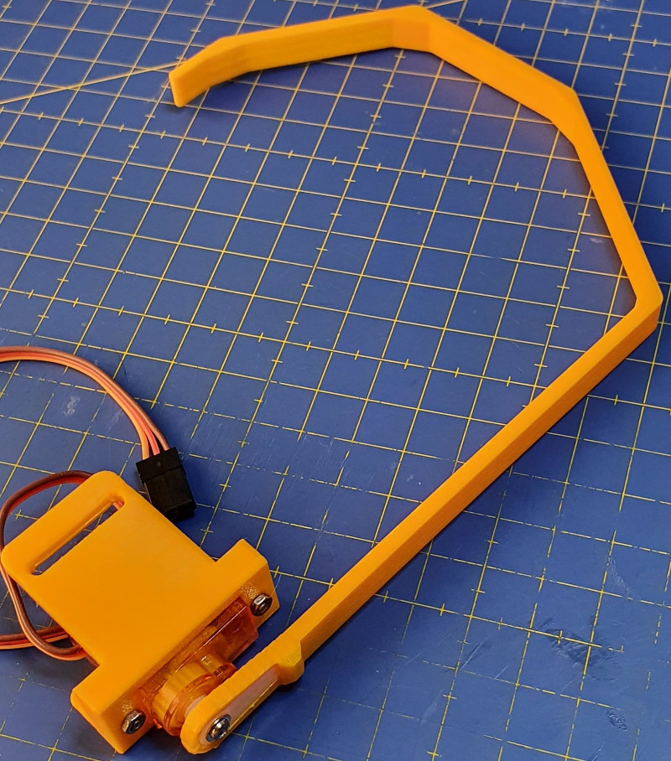
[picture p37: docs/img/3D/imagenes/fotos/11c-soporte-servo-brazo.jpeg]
Brazo con servo
| <br>Necesitamos:</br><br>- 1 brazo impreso</br><br>- 1 soporte para servo impreso</br><br>- 1 pala de un brazo para el servo</br><br>- 1 tornillo de rosca chapa de los que vienen con el servo</br><br>- 1 servo SG-90</br><br>- 2 tornillos M2x10mm</br><br>- 2 tuercas M2</br><br>- 2 tornillos M3x10mm</br><br>- 2 tuercas M3</br><br>Montamos el servo en su soporte y lo sujetamos con los tornillos M2x10. Colocamos la pala en el alojamiento del brazo y atornillamos este conjunto al servo con el tornillo de rosca chapa. El conjunto anterior lo montamos sobre la plataforma superior en el lugar escogido para ello que deberá estar lo mas cercano posible a la parte delantera del robot si imprimimos el brazo a su tamaño original. </P> <P align="right"><FONT COLOR="#7D3C98">En las imágenes vemos el aspecto de las piezas tanto en fase de diseño como impresas --></FONT></P></br><br>Es conveniente realizar el posicionamiento del engranaje del servo de forma adecuada antes de continuar. Teniendo en cuenta que el servo puede girar 180º colocamos el engranaje con la mano o con ayuda de una de las palas del servo en tal posición que permita el movimiento correcto del brazo o del sensor de ultrasonidos.</br> |<br></br><br></br> |

En las imagenes siguientes vemos la plataforma superior con el brazo colocado.

<center>

| Plataforma superior con brazo en fase de diseño | Plataforma superior con brazo |
|:-:|:-:|
| Plataforma superior con brazo en fase de diseño | Plataforma superior con brazo |

</center>

## <FONT COLOR=#007575>**Interruptor, Placa UNO y driver motores**</font>
Introducimos el interruptor en el orificio rectangular de la plataforma superior destinado para ello y ejerciendo un poco de presión lo encajamos en su lugar.

| **P8. Placa UNO y driver motores** | Imágenes |
|---|:-:|
| <br>Necesitamos:</br><br>- 7 separadores M3x5mm impresos</br><br>- 7 tornillos M3x12mm</br><br>- 7 tuercas M3</br><br>- 1 placa UNO con pines extendidos</br><br>- 1 placa driver de motores L298</br><br>Utilizando separadores M3x5mm impresos y tornillos M3x12mm con sus tuercas, colocamos tanto la placa UNO como la placa de drivers en su lugar, que con el interruptor ya colocado nos deja la plataforma superior acabada. </P> <P align="right"><FONT COLOR="#7D3C98">En la imágen vemos el aspecto del separador en fase de diseño --></FONT></P></br> |<br>Separador M3x5mm en fase de diseño</br> |

En la imagen siguiente vemos la plataforma superior en el estado actual.

<center>

| Plataforma superior finalizada en fase de diseño |
|:-:|
| Plataforma superior finalizada en fase de diseño |

</center>

## <FONT COLOR=#007575>**Ensamble de las dos plataformas**</font>

| **P9. Ensamble de las dos plataformas** | Imágenes |
|---|:-:|
| <br>Necesitamos:</br><br>- 4 separadores M3x28mm impresos</br><br>- 4 tornillos M3x40mm</br><br>- 4 tuercas M3</br><br>Utilizando los separadores M3x28mm impresos y tornillos M3x40mm con sus tuercas, sujetamos la plataforma superior a la inferior. </P> <P align="right"><FONT COLOR="#7D3C98">En la imágen vemos el aspecto del separador en fase de diseño --></FONT></P></br> |<br>Separador M3x5mm en fase de diseño</br> |

En la imagen siguiente vemos las dos plataformas montadas.

<center>

| Plataformas superior e inferior montadas en fase de diseño | Plataformas superior e inferior montadas |
|:-:|:-:|
| Plataformas superior e inferior montadas en fase de diseño |Plataformas superior e inferior montadas |

</center>

## <FONT COLOR=#007575>**Sensores de ranura**</font>
El último paso a realizar es colocar los sensores de ranura sujetos a la plataforma superior y alineados con los discos ranurados de forma que estos giren libremente.
<center>

| **P10. Sensores de ranura** | 
|---|
| <br>Necesitamos:</br><br>- 2 sensores de ranura</br><br>- 2 tornillos M3x10mm</br><br>- 2 tuercas M3</br><br>- 2 arandelas M3</br><br>Sujetamos ambos sensores en su lugar. </P> |

</center>

En las imagenes siguientes vemos en detalle el aspecto de estos sensores montados en su lugar.

<center>

| Sensores de ranura en fase de diseño | Sensores de ranura montados |
|:-:|:-:|
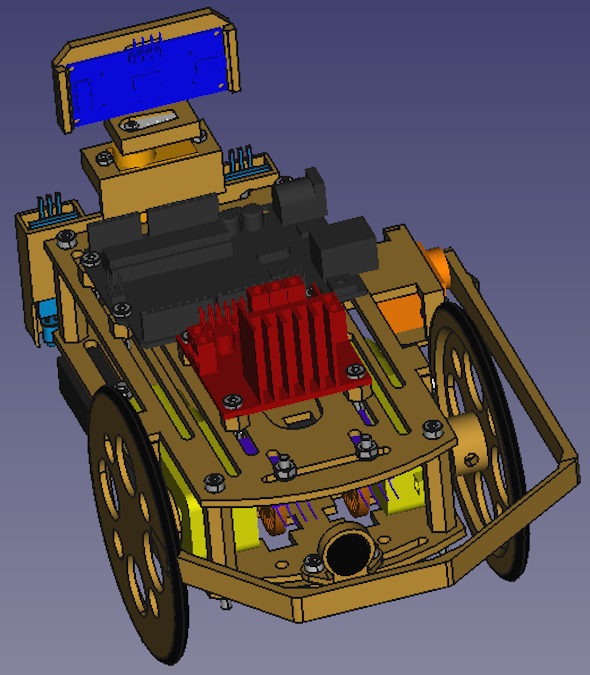
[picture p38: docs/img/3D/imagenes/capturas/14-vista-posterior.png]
Sensores de ranura en fase de diseño
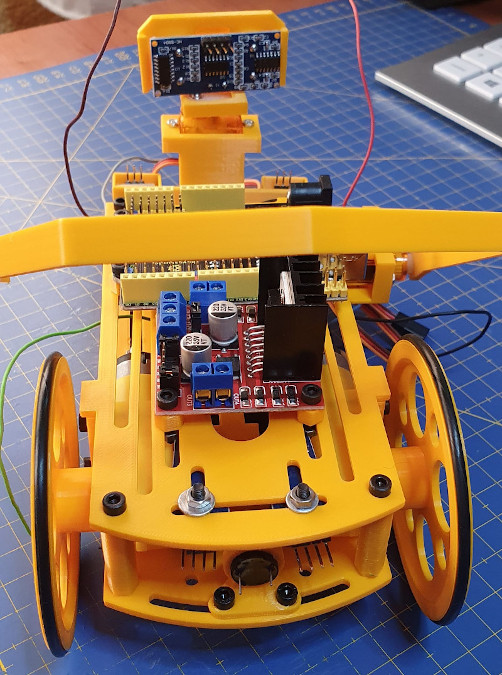
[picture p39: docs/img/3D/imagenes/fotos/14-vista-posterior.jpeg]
Sensores de ranura montados
|  | |

</center>

## <FONT COLOR=#007575>**Aspecto final del robot**</font>
Una vez finalizado el montaje de todos los elementos el robot presenta, en fase de diseño, el aspecto que vemos en las imágenes siguientes.

<center>

| Robot ensamblado en fase de diseño | Robot ensamblado en fase de diseño sobre el soporte de pruebas |
|:-:|:-:|
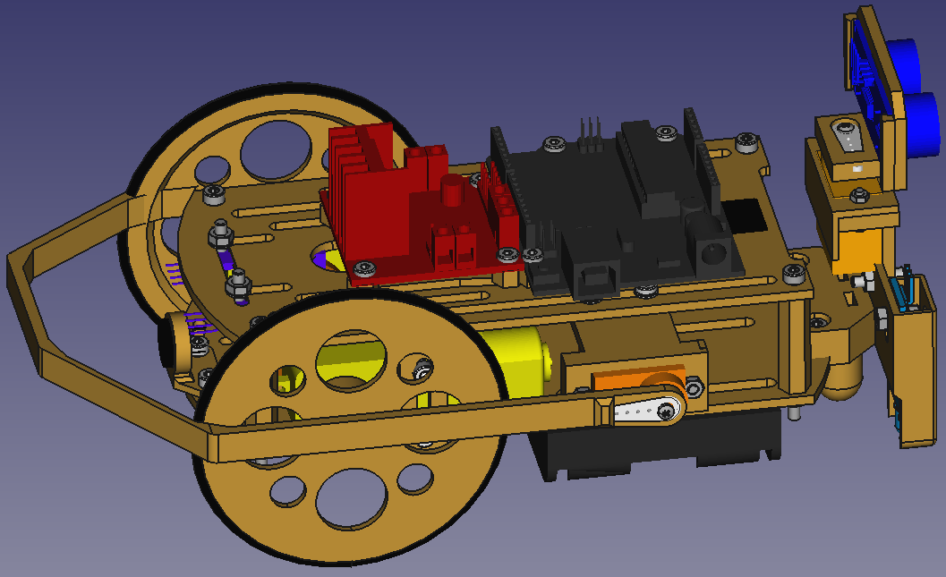
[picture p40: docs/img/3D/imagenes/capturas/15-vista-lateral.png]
Robot ensamblado en fase de diseño
|  |Robot ensamblado en fase de diseño sobre el soporte de pruebas |

</center>

En las imágenes siguientes vemos el robot con el ensamblado finalizado.

<center>

| Robot ensamblado | Robot ensamblado |
|:-:|:-:|
| Robot ensamblado |Robot ensamblado |

</center>

En la imagen siguiente vemos el robot ensamblado colocado sobre el soporte de pruebas listo para comenzar el conexionado y pruebas del montaje.

<center>

| Robot ensamblado sobre su soporte |
|:-:|
| Robot ensamblado sobre su soporte |

</center>

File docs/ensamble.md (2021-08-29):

# <FONT COLOR=#8B008B>Materiales necesarios y ensamblado plataforma base</font>

***

Vamos a realizar el paso a paso de montaje del robot utilizando para ellos la versión **MASAYLO-CRG-UNO**. El montaje de las otras versiones es totalmente similar y la única diferencia va a estar en la placa de control teniendo la plataforma superior habilitados orificios para las distintas placas. En cada uno de los pasos iremos indicando los materiales necesarios para su consecución.

Las herramientas necesarias para llevar a cabo el proceso van a depender del tipo de cabeza de tornillo que utilicemos, pero en cualquier caso necesitaremos destornilladores adecuados y unos alicates de punta plana por si es necesario sujetar algún tornillo.

Para los motores y el interruptor necesitaremos unos trozos de cable de distintos colores (rojo y negro a ser posible para distinguir bien la alimentación) de entre 10 y 15 cm de longitud. Estos cables irán directamente soldados a las patillas correspondientes de los motores y del interruptor. En el apartado correspondiente se detalla el proceso.

## <FONT COLOR=#007575>**Motores, Portapilas e interruptor**</font>

| **P0. Motores** | Imágenes |
|---|:-:|
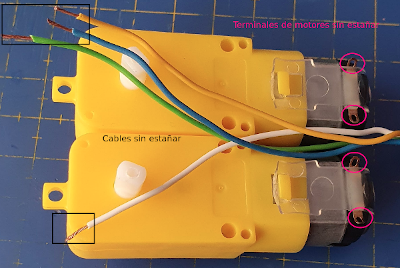
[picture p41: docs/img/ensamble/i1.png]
Motores y cables sin soldar
| <br>Si partimos de la base que los motores no vienen ya preinstalados con cables, necesitamos:</br><br>- 2 motores DC de 3 a 6V con reductora</br><br>- 4 trozos de hilos de diferentes colores</br><br>- Tijeras o pelacables</br><br>- Soldador para electrónica</br><br>- Se aconseja usar estaño de 1mm sin plomo con núcleo de resina y composición del 99% de Sn, 0.3% de Ag y 0.7% de Cu</br><br><P align="right"><FONT COLOR="#7D3C98">En la imagen vemos los motores y los cables sin soldar --></FONT></P></br> |  |
| </br><br><P align="right"><FONT COLOR="#7D3C98">En la imagen vemos los motores con los cables soldados --></FONT></P></br>  | Motores cableados |

| **P0. Portapilas** | Imágenes |
|---|:-:|
| <br>Lo ideal es adquirirlo con los cables ya instalados, aunque existen otras opciones que tendremos que analizar en cada caso. Para este paso necesitamos</br><br>- 1 portapilas 5xAA</br><br></br><br>Aunque sobresaldrá un poco por los laterales también nos puede valer un portapilas 6xAA</br><br><P align="right"><FONT COLOR="#7D3C98">En la imagen vemos el portapilas preparado con los cables --></FONT></P></br> | Portapilas con cables |

| **P0. Interruptor** | Imágenes |
|---|:-:|
| <br>Necesitamos:</br><br></br><br>- 1 mini interruptor basculante de 2 Pines tipo SPST de 10.5x15mm</br><br>- 2 trozos de hilos de diferentes colores, idealmente rojo y negro, para mantener el estándar de colores de alimentación<br></br><br>Debemos tener presente que con los cables soldados y la forma de colocación del interruptor (por presión en la plataforma superior) no podemos tener realizadas las conexiones a priori, es mas interesante realizar estas conexiones mediante, por ejemplo una clema, que permite un montaje cómodo y que podemos quitar si es necesario en el futuro.</br><br><P align="right"><FONT COLOR="#7D3C98">En la imagen tenemos el interruptor preparado para la instalación --></FONT></P></br> | Portapilas con cables |

## <FONT COLOR=#007575>**Plataforma base**</font>
En fase de diseño el aspecto de la plataforma base lo vemos en la imagen siguiente.

<center>

Plataforma base en fase de diseño

</center>

| **P1. Plataforma base** | Imágenes |
|---|:-:|
| <br>Necesitamos:</br><br>- 1 plataforma base impresa</br> <br>- 1 portapilas</br><br>- 2 motores DC de 3 a 6V con reductora ya cableados</br><br>- 2 tornillos M3x8mm de cabeza avellanada</br><br>- 4 tornillos M3x30mm</br><br>- 6 tuercas M3</br><br></br><P align="right"><FONT COLOR="#7D3C98">En la imagen vemos el aspecto de la plataforma base una vez impresa --></FONT></P></br> | Plataforma base impresa |
| Sujetamos el portapilas a la base utilizando los dos tornillos M3x8 y dos tuercas. <br></br><P align="right"><FONT COLOR="#7D3C98">Debe queda como observamos en la imagen quedando el portapilas bajo la base --></FONT></P></br> | Plataforma base y portapilas |
| Utilizando dos tornillos M3x30 y dos tuercas por cada motor los colocamos y atornillamos a la plataforma base, teniendo cuidado de que los motores queden bien pegados a la base. La posición exacta de los motores viene determinada por los orificios existentes en su carcasa y las ranuras de las pestañas verticales de la pieza impresa, que deben quedar alineadas. En esta etapa es conveniente, tal y como se aprecia en la imágen, que el disco perforado del encoder esté situado en el eje del motor y que este quede mas o menos centrado en la ranura de la base. <br></br><P align="right"><FONT COLOR="#7D3C98">En la imagen vemos como debe quedar --></FONT></P></br> | Plataforma base con motores |

En las imágenes siguientes vemos los pasos anteriores en fase de diseño

<center>

| Plataforma base con portapilas | Plataforma base con motores |
|:-:|:-:|
| Plataforma base con portapilas | Plataforma base con motores |

</center>

## <FONT COLOR=#007575>**Opción zumbador pasivo**</font>

Podemos optar por colocar el zumbador pasivo en la plataforma base o bien colocarlo en la plataforma superior. A continuación vemos el aspecto de la pieza en fase de diseño.

<center>

Soporte para buzzer en fase de diseño

</center>

| **P2. Zumbador pasivo** | Imágenes |
|---|:-:|
| <br>Necesitamos:</br><br>- 1 soporte para buzzer impreso</br> <br>- 1 zumbador pasivo</br><br>- 2 tornillos M3x8mm</br><br>- 2 tuercas M3</br><br>- 2 cables tipo dupont H-H de 20 cm</br><br></br><P align="right"><FONT COLOR="#7D3C98">En la imagen vemos el aspecto de la pieza impresa --></FONT></P></br> | Soporte para buzzer impreso |

En la imagen siguiente vemos la plataforma base con el soporte para zumbador colocado en su lugar, tanto en fase de diseño como en la realidad.

<center>

| Plataforma base con buzzer en fase de diseño | Plataforma base con buzzer |
|:-:|:-:|
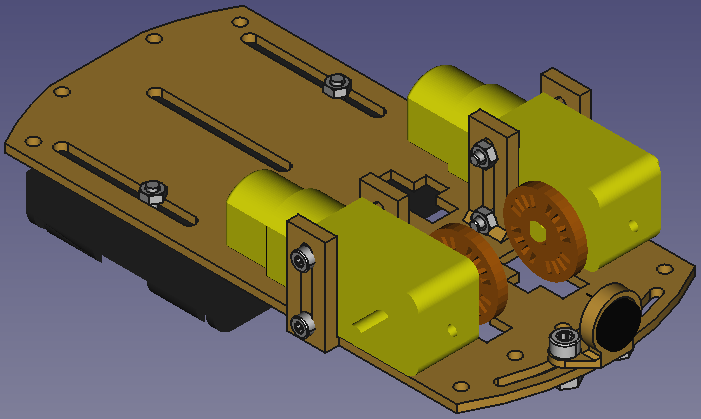
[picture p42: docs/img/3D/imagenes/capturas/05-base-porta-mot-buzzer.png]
Plataforma base con buzzer en fase de diseño
|  | Plataforma base con buzzer |

</center>

## <FONT COLOR=#007575>**Ballcaster y porta sensores IR**</font>
En realidad esta pieza podría ser una solamente pero se ha dividido en dos para evitar el uso de soportes en la impresión. El aspecto en fase de diseño de ambas piezas lo vemos en las imagenes siguientes:

<center>

|Ballcaster o Ballcaster en fase de diseño | Porta sensores de infrarrojos en fase de diseño|

</center>

| **P3. Ballcaster y porta sensores de infrarrojos** | Imágenes |
|---|:-:|
| <br>Necesitamos:</br><br>- 1 ballcaster impreso</br><br>- 1 portasensores IR impreso</br><br>- 2 tornillos M3x8mm</br><br>- 4 tornillos M3x10mm</br><br>- 6 tuercas M3</br><br>- 2 sensores IR de distancia ajustable detección 2 a 30cm</br><br>- 6 cables tipo dupont H-H de 20 cm</br><br>Colocamos y atornillamos los sensores IR con los tornillos M3x8. Empotramos dos tuerca M3 en la pieza ballcaster y colocamos esta pieza en la parte posterior del porta sensores alineando con los agujeros inferiores y atornillando con dos tornillos M3x10. Finalmente atornillamos el conjunto a la plataforma base utilizando dos tornillos M3x10 y alineando con los agujeros centrales de la base en la parte que muestra un trozo plano</br><P align="right"><FONT COLOR="#7D3C98">En la imagen vemos el aspecto del conjunto montado sobre las piezas impresas --></FONT></P></br> |<br>Soporte sensor IR fase diseño</br><br>Soporte sensor IR impreso y montado</br> |

En la imagen siguiente vemos la plataforma base con el soporte para sensores de infrarrojos y Ballcaster colocados en su lugar, tanto en fase de diseño como en la fase montaje real.

<center>

| Plataforma base con sensor IR en fase de diseño | Plataforma base con sensor IR |
|:-:|:-:|
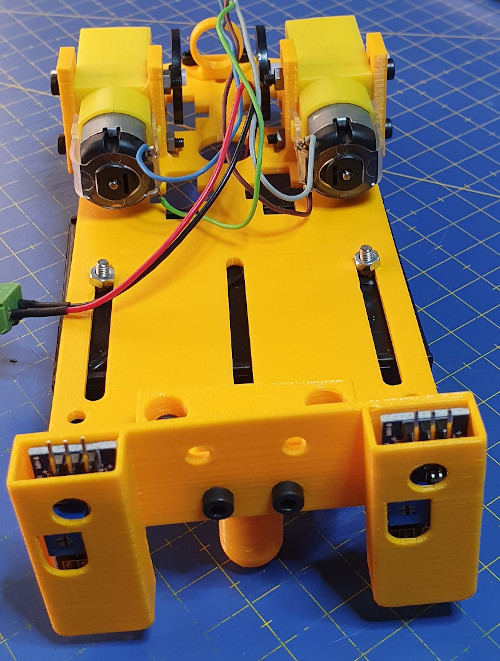
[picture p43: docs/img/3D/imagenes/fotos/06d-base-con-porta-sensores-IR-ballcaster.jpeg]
Plataforma base con sensor IR
| Plataforma base con sensor IR en fase de diseño |  |

</center>

## <FONT COLOR=#007575>**Ruedas**</font>
Nuestra propuesta va a incluir tres diseños que van a tener como diferencia el número y la posición de juntas tóricas. Las ruedas van a tener un radio exterior de 38 mm con una ranura que permite alojar una junta tórica de 75 mm de diámetro exterior y sección transversal de 3mm de diámetro. En la imagen siguiente vemos a la izquierda el modelo para dos juntas con separación de 10 mm entre ambas, en el centro la de una sola con la junta colocada y a la derecha tenemos el modelo de dos juntas sin distancia entre las mismas. Observamos como los diseños interiores de las ruedas son iguales en cuanto a geometría e indicaremos que el número y la posición de las juntas se establece para dar solución a las diferentes adherencias de superficies y evitar en lo posible que las ruedas derrapen cuando giran.

<center>

Los tres modelos de ruedas en fase de diseño

</center>

El orificio con la forma del eje del motor está dimensionado para que la rueda quede bien acoplada simplemente presionando sobre el eje, pero somos conscientes de que las impresoras 3D tienen ciertas tolerancias y no todas van a darnos exactamente las mismas dimensiones, por ello hemos previsto la posibilidad de realizar la sujeción mediante tornillo que ejerza presión contra el eje del motor y tuerca empotrada en el cilindro de la rueda. Este paso de montaje va a depender de la opción escogida y de si usamos o no tornillo prisionero.

| **P4. Ruedas** | Imágenes |
|---|:-:|
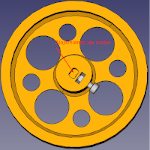
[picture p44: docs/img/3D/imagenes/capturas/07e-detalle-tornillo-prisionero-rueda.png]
Tornillo prisionero
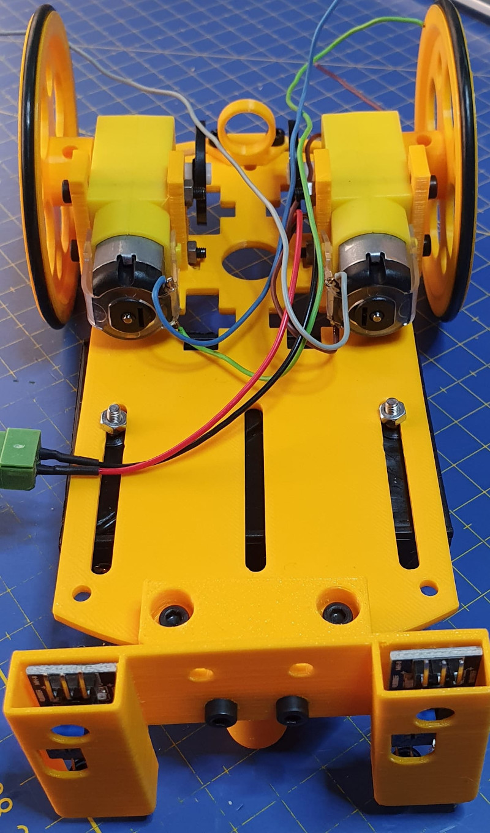
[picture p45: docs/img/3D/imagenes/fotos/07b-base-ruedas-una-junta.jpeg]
Base con ruedas de una junta montadas
| <br>Necesitamos:</br><br>- 2 ruedas impresas del modelo escogido</br><br>- 2 (o 4) juntas tóricas de 75x3mm</br><br>- 2 tornillos M3x10mm</br><br>- 2 tuercas M3</br><br>Colocamos haciendo presión si es necesario una rueda en cada eje de motor. Si es necesario porque el encaje anterior tiene holgura, empotramos una tuerca M3 en cada rueda y fijamos la posición de la rueda utilizando el tornillo prisionero. En la imagen inferior vemos el detalle del tornillo prisionero.</br><P align="center"><br></br></P> <P align="right"><FONT COLOR="#7D3C98">En la imagen vemos el aspecto del conjunto montado con las ruedas de una junta --></FONT></P></br> | |

En las imagenes siguientes vemos la plataforma base con cada tipo de ruedas en fase de diseño.

<center>

| Plataforma base con ruedas una junta | Plataforma base con ruedas dos juntas | Plataforma base con ruedas dos juntas separadas |
|:-:|:-:|:-:|
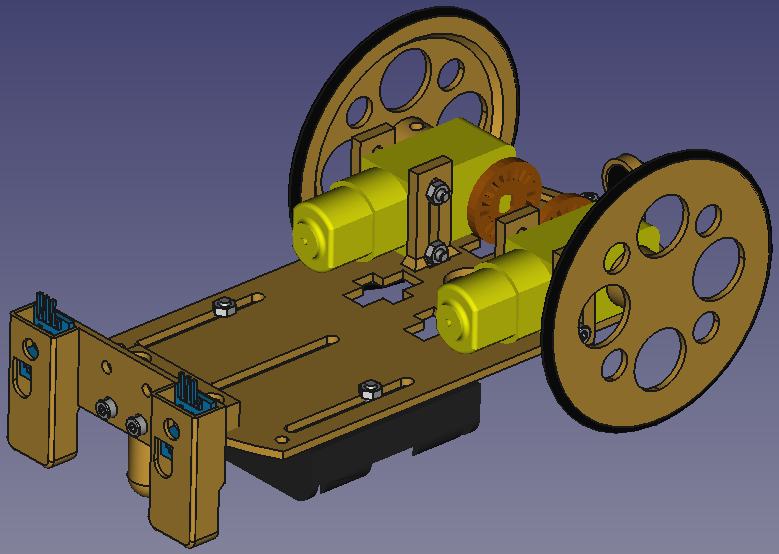
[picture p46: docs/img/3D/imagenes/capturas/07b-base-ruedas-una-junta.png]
Plataforma base con ruedas una junta
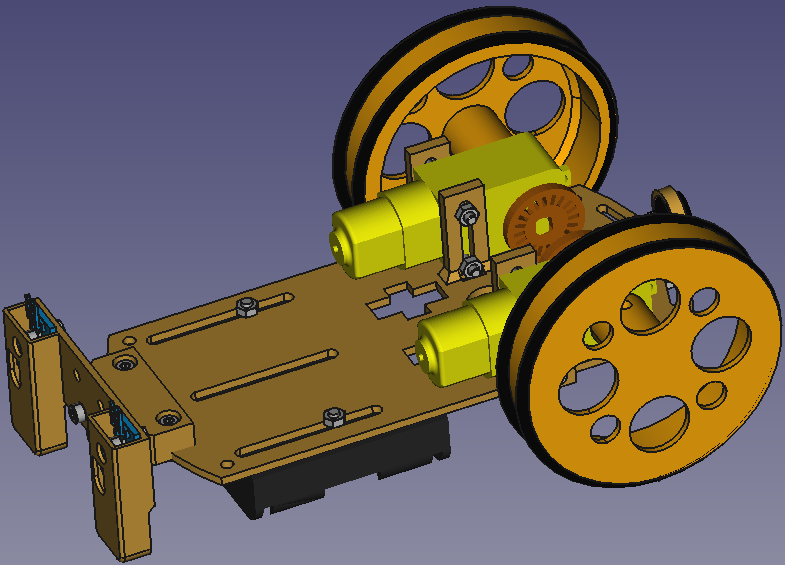
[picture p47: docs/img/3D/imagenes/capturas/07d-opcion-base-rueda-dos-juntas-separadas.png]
Plataforma base con ruedas dos juntas separadas
|  | Plataforma base con ruedas dos juntas |  |

</center>

## <FONT COLOR=#007575>**Soporte para servo SG-90**</font>
En esta pieza es donde colocamos y atornillamos el servo motor tanto para el brazo aparta objetos como para el sensor de ultrasonidos móvil. Si vamos a optar por la opción de ultrasonidos fijo solamente debemos montar un servo pero si optamos por la opción con sensor de ultrasonidos móvil debemos montar dos conjuntos.

| **P5. Servo SG-90** | Imágenes |
|---|:-:|
| <br>Necesitamos:</br><br>- 1 (o 2) soporte para servo impreso</br><br>- 1 (o 2) servomotores SG-90</br><br>- 2 (o 4) tornillos M2x10mm</br><br>- 2 (o 4) tuercas M2</br><br>Colocamos el servo en la pieza y lo sujetamos utilizando los tornillos M2x10. </P> <P align="right"><FONT COLOR="#7D3C98">En las imágenes vemos el aspecto de la pieza tanto en fase de diseño como impresa --></FONT></P></br><br>Es conveniente realizar el posicionamiento del engranaje del servo de forma adecuada antes de continuar. Teniendo en cuenta que el servo puede girar 180º colocamos el engranaje con la mano o con ayuda de una de las palas del servo en tal posición que permita el movimiento correcto del brazo o del sensor de ultrasonidos.</br> |<br>Sopote para servo en fase de diseño</br><br>Sopote para servo impreso</br> |

En las imagenes siguientes vemos el soporte con el servo colocado.

<center>

| Portaservo con servo en fase de diseño | Portaservo impreso con servo |
|:-:|:-:|
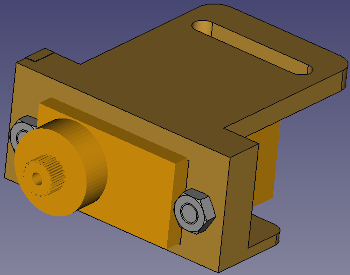
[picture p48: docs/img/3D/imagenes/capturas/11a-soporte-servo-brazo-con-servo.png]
Portaservo con servo en fase de diseño
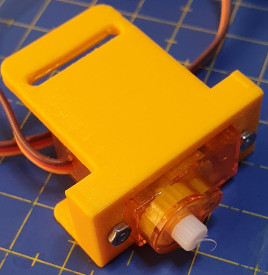
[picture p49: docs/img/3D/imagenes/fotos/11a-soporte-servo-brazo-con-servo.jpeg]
Portaservo impreso con servo
|  |  |

</center>

## <FONT COLOR=#007575>**Soporte sensor de ultrasonidos HC-SR04**</font>
Tenemos dos opciones disponibles, un soporte fijo que podemos colocar tanto en la parte superior del porta sensores IR o utilizando alguna de las ranuras de las plataformas superior o inferior, y un soporte móvil accionado por un servo pensado para colocarlo a modo de *cabeza giratoria* también en la parte superior del porta sensores de IR. En ambos casos el sensor se coloca presionando ligeramente para que encaje en las pestañas del porta sensores. En las imágenes siguientes tenemos ambos tipos de soportes tanto en modo diseño como impresos.

<center>

| Porta HC-SR04 fijo fase diseño | Porta HC-SR04 fijo impreso | Porta HC-SR04 móvil fase diseño | Porta HC-SR04 móvil impreso |
|:-:|:-:|:-:|:-:|
| Porta HC-SR04 fijo fase diseño | Porta HC-SR04 fijo impreso |Porta HC-SR04 móvil fase diseño |Porta HC-SR04 móvil impreso |

</center>

| **P6. Sensor de ultrasonidos HC-SR04** | Imágenes |
|---|:-:|
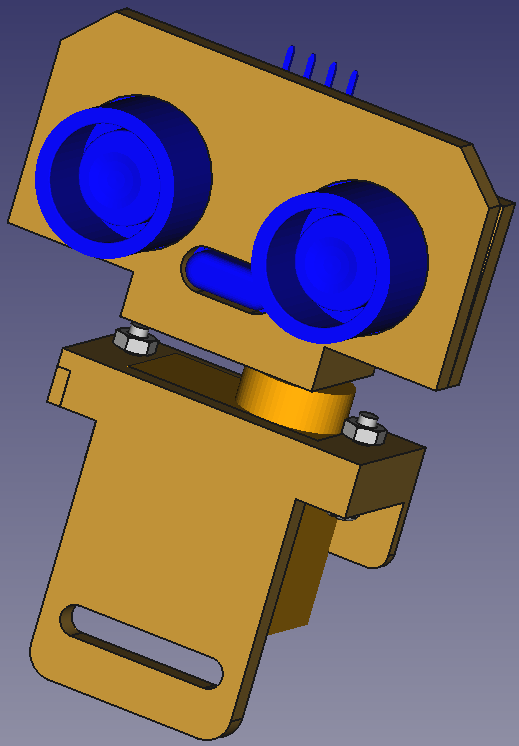
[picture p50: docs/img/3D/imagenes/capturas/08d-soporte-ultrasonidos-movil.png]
Sopote sensor ultrasonidos móvil con servo en fase de diseño
| <br>Necesitamos:</br><br>- 1 soporte fijo para sensor HC-SR04 impreso</br><br>- 1 soporte móvil para sensor HC-SR04 impreso</br><br>- 1 (o 2) pala de un brazo para el servo</br><br>- 1 (o 2) tornillos de rosca chapa de los que vienen con el servo</br><br>- 1 servo montado en su soporte</br><br>- 2 tornillos M3x10mm</br><br>- 2 tuercas M3</br><br>Colocamos el sensor de ultrasonidos en su alojamiento en el soporte fijo o móvil elegido. Si hemos escogido soporte fijo sujetamos este con dos tornillos M3x10 en el lugar escogido y si hemos escogido el soporte móvil sujetamos el soporte del sensor al servo con el tornillo de rosca chapa colocando la pala en la cabeza del servo. </P> <P align="right"><FONT COLOR="#7D3C98">En las imágenes vemos el aspecto de las piezas tanto en fase de diseño como impresas --></FONT></P></br><br>Es conveniente realizar el posicionamiento del engranaje del servo de forma adecuada antes de continuar. Teniendo en cuenta que el servo puede girar 180º colocamos el engranaje con la mano o con ayuda de una de las palas del servo en tal posición que permita el movimiento correcto del brazo o del sensor de ultrasonidos.</br> |<br>Sopote sensor ultrasonidos móvil en fase de diseño</br><br></br><br>Sopote sensor ultrasonidos móvil impreso</br><br>Sopote sensor ultrasonidos móvil impreso con servo</br> |

En las imagenes siguientes vemos la plataforma base finalizada con todas sus opciones colocadas.

<center>

| Plataforma base finalizada en fase de diseño | Plataforma base finalizada |
|:-:|:-:|
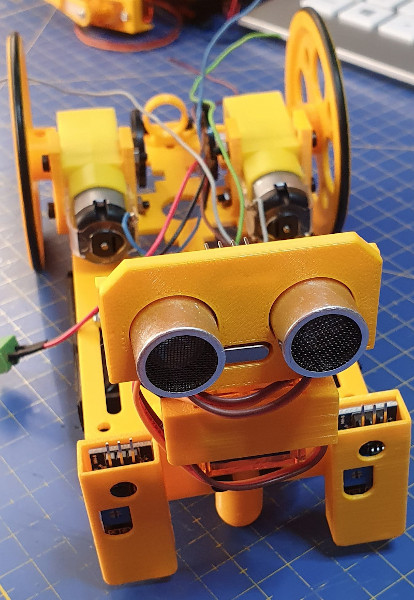
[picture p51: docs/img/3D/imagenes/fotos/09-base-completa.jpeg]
Plataforma base finalizada
| Plataforma base finalizada en fase de diseño |  |

</center>

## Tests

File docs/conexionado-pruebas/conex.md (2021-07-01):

# <FONT COLOR=#8B008B>Conexionado de los distintos elementos</FONT>
Describimos el conexionado que debemos realizar entre los distintos elementos, lo que haremos fundamentalmente en forma de gráfico o pinout.

## <FONT COLOR=#007575>**Alimentación**</font>
Antes de nada vamos a resolver las conexiones de alimentación de nuestra placa UNO y del driver de motores L298 junto con el portapilas y el interruptor. El resto de elementos se alimentarán directamente de la placa UNO. El conexionado es válido si sustituimos las cinco (o seis) pilas AA por dos baterías tipo 18650.

Para que la placa UNO y el driver queden conectados con el interruptor utilizaremos una clema de la que sacaremos un cable para el jack de alimentación del UNO y otro para el positivo del driver, siendo este cable el que previamente pasa por el interruptor procedente del portapilas. El negativo es un cable doble que va al UNO y al driver sin pasar por el interruptor.

En estas condiciones el junper *Regulador* del driver debe estar colocado en su lugar y debemos tener en cuenta que la tensión de entrada caerá en 0.7V debido al diodo protector de inversión de polaridad que lleva la placa. Esto lo podemos evitar utilizando el pin Vin de la tira de pines de alimentación, pero debemos tener en cuenta que así no hay protección y que se recomienda no usar tensiones superiores a 6V. En nuestro caso usamos 5 pilas AA con lo que partimos de una tensión de 7.5V que bajará aproximadamente a 6.8V y si usamos 2x18650 tendremos 7.2V que se quedarán en 6.5V.

En la imagen siguiente tenemos el detalle de conexionado de la alimentación para ambas placas que debemos realizar de forma cuidadosa en especial y no cambiar la polaridad de la alimentación que se ha marcado y dibujado con los colores normalizados de la misma.

<center>

| Conexionado de alimentación |
|:-:|
|  |

</center>

La forma más sencilla de conectar los elementos es utilizando un jack de alimentación con clema como el que se ve en la imagen anterior aunque también podemos utilizar un jack normal realizando las correspondientes soldaduras.

Se **<FONT COLOR=#FF0000>recomienda</FONT>** que una vez finalizadas las conexiones se revisen estas cuidadosamente, tanto en las conexiones en si mismas como en la polaridad, antes de alimentar el sistema o conectar el USB para grabar algún programa, así evitaremos en lo posible romper algo por mal conexionado.

## <FONT COLOR=#007575>**Motores DC 3 a 6V**</font>
Procedemos a conectar los motores en las bornas del driver L298 de forma que el motor izquierdo quede conectado a OUT1 - OUT2 y el derecho a OUT3 - OUT4. Por ahora no nos preocupamos de la polaridad ya que lo haremos en las pruebas y si algún motor girar en sentido contario al esperado bastará con intercambiar sus conexiones de posición. En la imagen siguiente tenemos el conexionado de forma gráfica.

<center>

| Conexionado de motores |
|:-:|
|  |

</center>

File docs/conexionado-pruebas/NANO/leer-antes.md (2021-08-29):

# <FONT COLOR=#FF0000>**Aclaraciones sobre placas Nano**</font>
Vamos a analizar y establecer las diferencias entre un Arduino Nano original y las versiones económicas de este, al menos en dos versiones de estas.

Si vamos a trabajar con placas [Arduino Nano](https://search.arduino.cc/search?tab=&q=nano) originales podemos omitir la lectura de este apartado, pero si vamos a trabajar con clones (las conocidas como nanos chinos) es **MUY IMPORTANTE** que leamos detenidamente este apartado con el fin de averiguar que placa nano es la que tenemos en nuestras manos y así poder actuar en consecuencia.

Si hay que aclarar que este estudio se realiza para la versión nano convencional implementada con microcontroladores ATMega y no para la nueva línea de productos cuyo cerebro se implementa con dispositivos microcontroladores SAMD21G18A.

## <FONT COLOR=#007575>**Análisis del problema**</font>
Conocemos que la alimentación de la placas nano se puede hacer por mini-USB, por el conector 5V o por la entrada de alimentación externa VIN, que se aconseja que esté entre 7V y 12V de corriente continua. Aconsejamos consultar el tutorial [Alimentar el Arduino: La guía definitiva](https://www.geekfactory.mx/tutoriales/tutoriales-arduino/alimentar-el-arduino-la-guia-definitiva/) de [Geek factory](https://www.geekfactory.mx/) si no sabes bien de lo que estamos hablando.

Cuando descendemos a nivel de esquema, las placas tipo Nano utilizan un diodo Schottky (diodo semiconductor que proporciona conmutaciones de menos de 1ns entre los estados de conducción directa e inversa) entre la alimentación USB y Vcc que tiene como misión evitar que pueda pasar corriente desde la placa Nano al ordenador al que la tengamos conectada a través del puerto USB cuando alimentamos con una fuente externa 6 a 12V en el pin VIN, que podría provocar daños en el mismo.

En la imagen siguiente podemos ver este diodo en el esquema de un Arduino Nano original

<center>

| Diodo Schottky USB en Arduino Nano original |
|:-:|
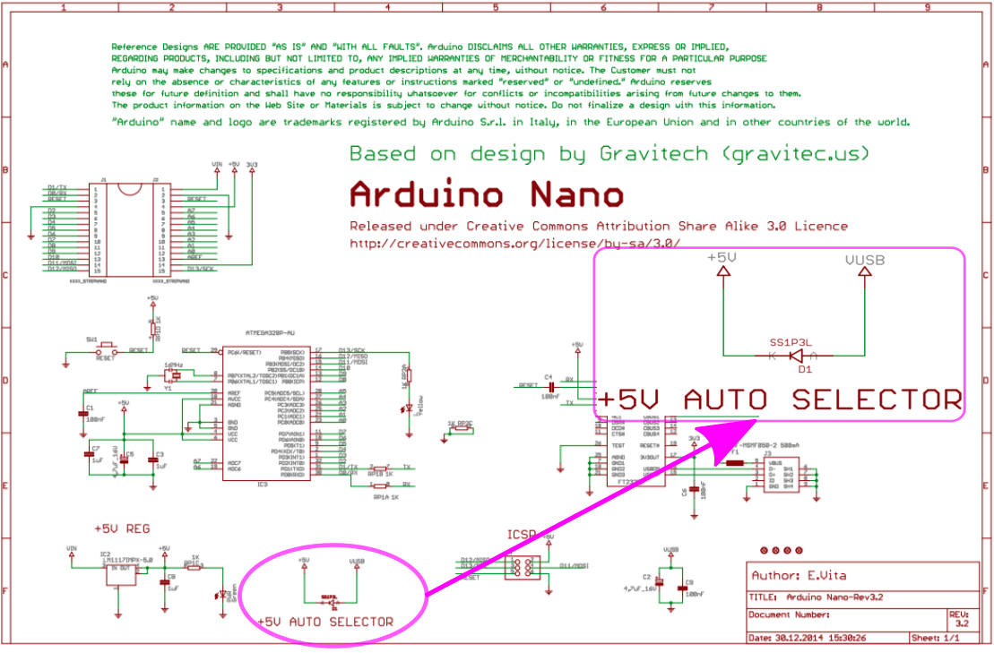
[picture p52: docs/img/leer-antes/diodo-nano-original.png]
Diodo Schottky USB en Arduino Nano original
|  |
| Imagen obtenida a partir del [esquema](https://www.arduino.cc/en/uploads/Main/Arduino_Nano-Rev3.2-SCH.pdf) encontrado en [arduino.cc](https://www.arduino.cc/) |

</center>

En la imagen anterior vemos que el diodo es un SS1P3L, en algunas versiones podemos encontrar que el diodo es un MBR0520 (ya obsoleto) y en una placa real como la de la imagen siguiente que este diodo es un SKL14 de Diotec.

<center>

| Diodo Schottky USB SKL14 en Arduino Nano original |
|:-:|
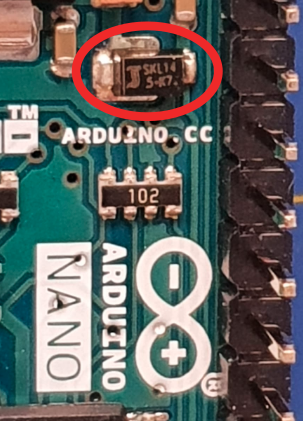
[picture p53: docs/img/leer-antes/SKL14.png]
Diodo Schottky USB SKL14 en Arduino Nano original
|  |

</center>

Si consultamos los datasheet de estos diodos nos vamos a encontrar con los valores de corriente directa media que vemos en la tabla siguiente:

<center>

| Parámetro | SS1P3L | MBR0520 | SKL14 |
|---|:-:|:-:|:-:|
| Average Forward Rectified Current | 1A | 500mA | 1A |

</center>

Si hacemos el mismo análisis para un clon como el de AZ-Delivery nos encontramos que ese diodo es un SD101CWS, tal y como vemos en la imagen siguiente:

<center>

| Diodo Schottky USB en Nano clon |
|:-:|
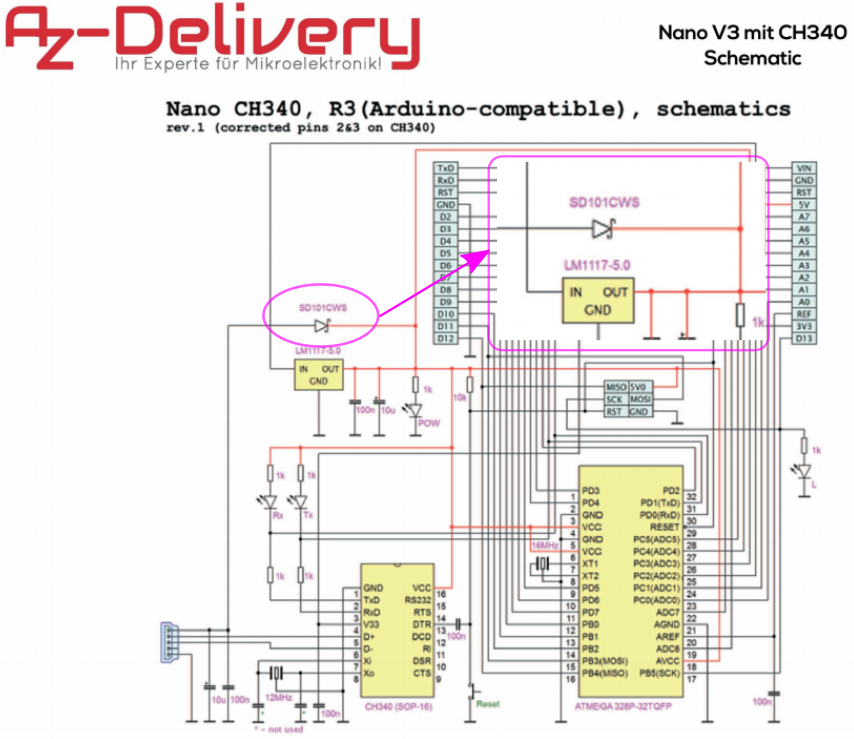
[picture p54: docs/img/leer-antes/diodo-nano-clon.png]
Diodo Schottky USB en Nano clon
|  |
| Imagen obtenida a partir del [esquema](https://cdn.shopify.com/s/files/1/1509/1638/files/Nano_V3_mit_CH340_Schematic.pdf?17911342447424002070) encontrado en [AZ-Delivery](https://www.az-delivery.de/es) |

</center>

Si consultamos el datasheet de este diodo nos vamos a encontrar con el valor de corriente directa media que vemos en la tabla siguiente:

<center>

| Parámetro | SD101CWS |
|---|:-:|
| Average Forward Current | 30mA |

</center>

Un poco mas de investigación la podemos ver en la imagen siguiente, que se corresponde con la fotografía de una placa Nano de AZ-Delivery.

<center>

| Diodo Schottky USB S4 en una Nano de AZ-Delivery |
|:-:|
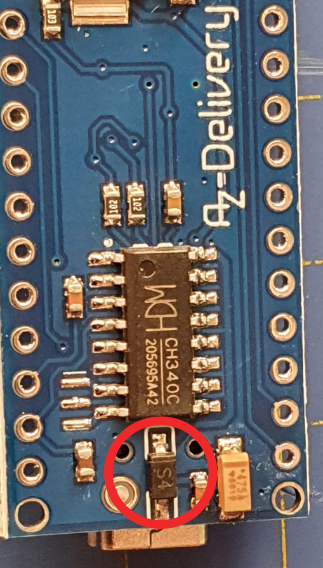
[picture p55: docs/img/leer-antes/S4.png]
Diodo Schottky USB S4 en una Nano de AZ-Delivery
|  |

</center>

Una búsqueda del datasheet de este componente nos lleva a obtenerla de [Diodes](https://www.diodes.com/) y en este pdf obtenemos los datos que vemos en la imagen siguiente:

<center>

| Datasheet del diodo S4 |
|:-:|
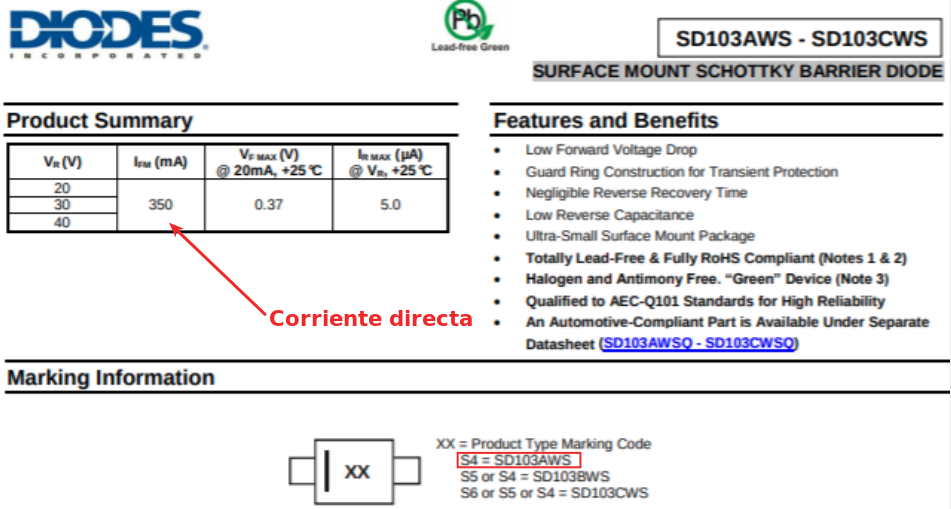
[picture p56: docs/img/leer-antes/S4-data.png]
Datasheet del diodo S4
|  |
| Imagen obtenida a partir del datasheet de [Diodes](https://www.diodes.com/assets/Datasheets/ds30101.pdf) |

</center>

Observamos claramente que la corriente directa del diodo está por debajo de las especificaciones requeridas para una placa Nano por lo que debemos asegurarnos, cuando adquirimos este tipo de placas, del diodo que llevan y que al menos presente las especificaciones de 500mA en adelante.

La experiencia indica que, aunque con estas placas podemos trabajar grabando el firmware, desconectando el USB y alimentándola con una fuente externa, tarde o temprano dejaremos conectado el USB, accionaremos la alimentación externa y provocaremos una circulación de corriente (si tenemos conectados suficientes dispositivos a la placa) mayor a la que soporta el diodo que se quemará y dejará la placa inservible.

## <FONT COLOR=#007575>**Recomendaciones**</font>
Lógicamente la primera va a ser trabajar con placas originales que nos ofrecerán todas las garantías por su contrastada calidad y su precio tampoco es demasiado elevado. Por ejemplo [BricoGeek](https://tienda.bricogeek.com/arduino/12-arduino-nano-8058333490342.html) es un distribuidor que envía con bastante rapidez a precios muy razonables.

En segundo lugar la recomendación sería la placa de Keyestudio ks0173 que distribuye oficialmente para España [Innova Didactic](https://shop.innovadidactic.com/es/standard-placas-shields-y-kits/691-keyestudio-nano-3-0-chip-ch340-cable-usb.html) por un precio de unos 7€ y que también tiene una distribución muy rápida.

En tercer lugar, aunque lógicamente existen otros muchos fabricantes de clones, sería Elegoo que en España podemos comprar a través de [Amazon](https://www.amazon.es/dp/B0716T2L77) un kit de tres placas muy bien embaladas y por unos 14€.

Las versiones de Keyestudio (derecha) y Elegoo (izquierda) se construyen con un diodo tipo B2 tal y como vemos destacado en la imagen siguiente:

<center>

| Placas con diodo B2 |
|:-:|
| Placas con diodo B2 |

</center>

B2 es el código de dispositivo de los diodos tipo MBR0520LT1G, SBR80520LT1G, MBR0520LT3G, SBR80520LT3G tal y como podemos observar en la siguiente imagen:

<center>

| Datasheet diodo tipo B2 |
|:-:|
| Datasheet diodo tipo B2 |
| Imagen obtenida a partir del datasheet de [On Semiconductor](https://www.onsemi.com/pdf/datasheet/mbr0520lt1-d.pdf) |

</center>

En esta hoja de datos podemos comprobar que la corriente directa de este diodo es la que se indica a continuación:

<center>

| Parámetro | MBR0520LT1G B2 |
|---|:-:|
| Average Forward Current | 500mA |

</center>

***
Es decir, la recomendación final sería que antes de comprar a la ligera este tipo de producto no nos guiemos solamente por su precio y miremos también la calidad.
***

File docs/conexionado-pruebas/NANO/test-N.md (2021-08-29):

# <FONT COLOR=#8B008B>Pruebas básicas de funcionamiento</font>
Básicamente los ejemplos que utilizaremos para esta versión Nano son los mismos que los utilizados para la versión UNO realizando los cambios a la placa adecuada, que en nuestro caso va a ser una Nano con Old bootloader.

## <FONT COLOR=#007575>**Alimentación**</font>
Colocamos las pilas AA en su lugar respetando la polaridad de las mismas y accionamos el interruptor. Si todo es correcto en la placa shield y en la del driver L298 se debe encender un diodo LED rojo y en la placa Nano un LED verde, todos ellos indicativos de que están alimentadas, tal y como observamos en la imagen siguiente:

<center>

| Primer encendido |
|:-:|
| Primer encendido |

</center>

Reutilizamos el programa [blink.bloc](../UNO/tests/blink.bloc) para probar también que se graba correctamente firmware en la placa NANO. Para ello debemos seleccionar la placa adecuada, tal y como vemos en la imagen siguiente.

<center>

| Programa blink.bloc |
|:-:|
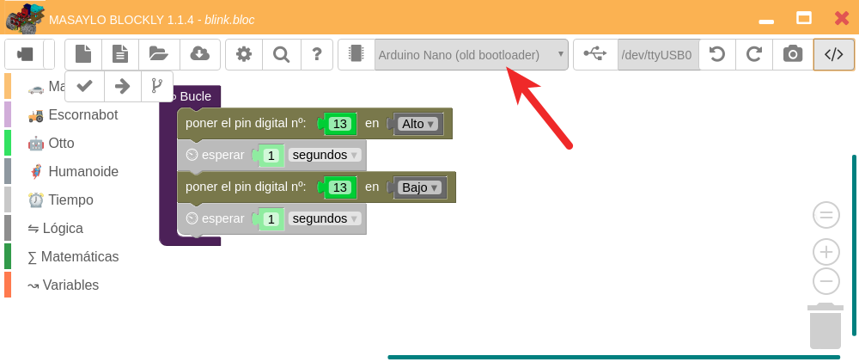
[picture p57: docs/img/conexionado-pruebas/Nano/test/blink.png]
Programa blink.bloc
|  |

</center>

Si cargamos el programa y dejamos sin accionar el interruptor observaremos como parpadea el LED asociado al pin 13, de color rojo, en la placa Nano pero la placa del driver no está alimentada y por tanto su LED permanece apagado. En la animación siguiente vemos el parpadeo del LED y el resultado de accionar el interruptor.

<center>

| Animación que muestra el funcionamiento del programa blink.bloc y del interruptor |
|:-:|
| Animación que muestra el funcionamiento del programa blink.bloc y del interruptor |

</center>

Este GIF se ha creado a partir de un video en formato mp4 utilizando FFMPEG y GIMP y la información obtenida en [este enlace](https://ubunlog.com/gif-animados-vlc-ffmpeg-gimp/).

## <FONT COLOR=#007575>**Pruebas idénticas a las realizadas en la versión UNO**</font>
Para las pruebas siguientes podemos simplemente cargar los ejemplos dados para la versión UNO y simplemente cambiando el tipo de placa ya podemos proceder a cargarlos y comprobar el funcionamiento de los elementos en cuestión.

* Motores
* Zumbador
* Sensores de infrarrojos
* Sensor de distancia HC-SR04
* Servomotores
* Encoder infrarrojos FC-03

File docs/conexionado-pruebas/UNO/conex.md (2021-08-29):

# <FONT COLOR=#8B008B>Conexionado de los distintos elementos</FONT>
Describimos el conexionado que debemos realizar entre los distintos elementos, y lo haremos fundamentalmente en forma de gráfico y utilizando el pinout mostrado en la imagen siguiente. La fuente de esta imagen la tenemos en este [archivo svg](../../img/conexionado-pruebas/UNO/Masaylo-UNO-pinout.svg)

<center>

| Masaylo-CRG UNO pinout |
|:|
| Masaylo-CRG UNO pinout |

</center>

## <FONT COLOR=#007575>**Alimentación**</font>
Antes de nada vamos a resolver las conexiones de alimentación de nuestra placa UNO y del driver de motores L298 junto con el portapilas y el interruptor. El resto de elementos se alimentarán directamente de la placa UNO. El conexionado es válido si sustituimos las cinco (o seis) pilas AA por dos baterías tipo 18650.

Para que la placa UNO y el driver queden conectados con el interruptor utilizaremos una clema de la que sacaremos un cable para el jack de alimentación del UNO y otro para el positivo del driver, siendo este cable el que previamente pasa por el interruptor procedente del portapilas. El negativo es un cable doble que va al UNO y al driver sin pasar por el interruptor.

En estas condiciones el jumper *Regulador* del driver debe estar colocado en su lugar y debemos tener en cuenta que la tensión de entrada caerá en 0.7V debido al diodo protector de inversión de polaridad que lleva la placa. Esto lo podemos evitar utilizando el pin Vin de la tira de pines de alimentación, pero debemos tener en cuenta que así no hay protección y que se recomienda no usar tensiones superiores a 6V. En nuestro caso usamos 5 pilas AA con lo que partimos de una tensión de 7.5V que bajará aproximadamente a 6.8V y si usamos 2x18650 tendremos 7.2V que se quedarán en 6.5V.

En la imagen siguiente tenemos el detalle de conexionado de la alimentación para ambas placas que debemos realizar de forma cuidadosa en especial y no cambiar la polaridad de la alimentación que se ha marcado y dibujado con los colores normalizados de la misma.

<center>

| Conexionado de alimentación |
|:-:|
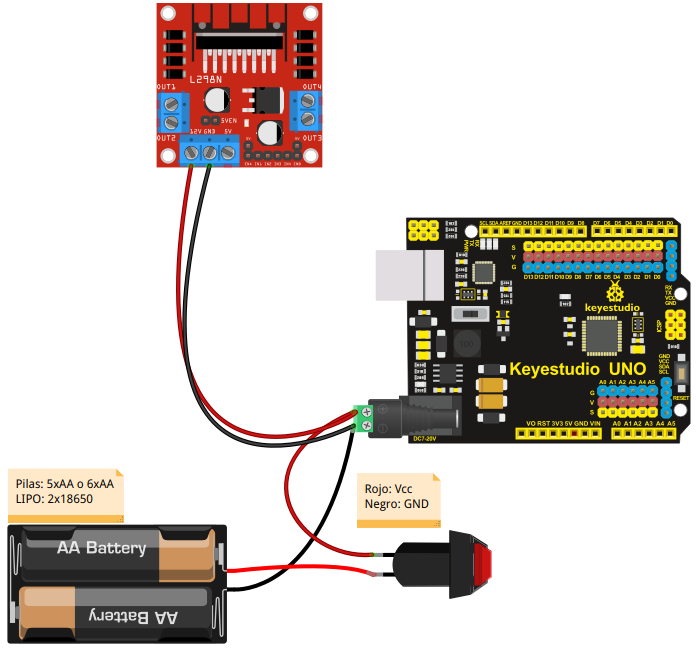
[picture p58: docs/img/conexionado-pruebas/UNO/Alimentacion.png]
Conexionado de alimentación
|  |

</center>

La forma más sencilla de conectar los elementos es utilizando un jack de alimentación con clema como el que se ve en la imagen anterior aunque también podemos utilizar un jack normal realizando las correspondientes soldaduras.

Se **<FONT COLOR=#FF0000>recomienda</FONT>** que una vez finalizadas las conexiones se revisen estas cuidadosamente, tanto en las conexiones en si mismas como en la polaridad, antes de alimentar el sistema o conectar el USB para grabar algún programa, así evitaremos en lo posible romper algo por mal conexionado.

## <FONT COLOR=#007575>**Motores DC 3 a 6V**</font>
Procedemos a conectar los motores en las bornas del driver L298 de forma que el motor izquierdo quede conectado a OUT1 - OUT2 y el derecho a OUT3 - OUT4 que son los pines encargados de entregar energía a los motores. Por ahora no nos preocupamos de la polaridad ya que lo haremos en las pruebas y si algún motor girar en sentido contrario al esperado bastará con intercambiar sus conexiones de posición. En la imagen siguiente tenemos el conexionado de forma gráfica.

<center>

| Conexionado de motores |
|:-:|
| Conexionado de motores |

</center>

Los pines de control de cada motor se conectan como se indica en la gráfica, de forma que ENA será el control PWM del motor izquierdo que se hará en el pin 6, e IN1 e IN2 los conectamos según el sentido de giro adecuado a los pines 7 y 8. Para el motor derecho el pin PWM es el 11 que irá a ENB y los IN3 e IN4 a los pines 12 y 13.

## <FONT COLOR=#007575>**Zumbador**</font>
Usamos el pin D1 o TxD y su Vcc asociado para conectarlo. En principio esta conexión no debe interferir en la grabación de programas en la placa que siempre se realiza utilizando los pines D0 y D1 de la misma, pero si nos da algún problema basta con que desconectemos el pin D0 del sensor en uno de sus extremos, procedamos a grabar el programa correspondiente y una vez cargado este volvemos a conectar el pin en su lugar. Si no queremos estar escuchando pitidos de manera continuada cuando subimos código a la placa o cuando usamos el monitor serie también debemos desconectar esta patilla. Alternativamente y en caso de no usar la funcionalidad Bluetooth podemos conectar el buzzer a uno de los pines reservados para esta funcionalidad en el pinout. En la imagen siguiente podemos ver el conexionado de estos elementos de forma gráfica junto con los conectados anteriormente.

<center>

| Conexionado de conjunto incluyendo zumbador |
|:-:|
| Conexionado de conjunto incluyendo zumbador |

</center>

En la imagen siguiente observamos una pareja de cables, uno blanco que va al pin D1 y uno negro que va a GND.

<center>

| Conexionado del zumbador |
|:-:|
| Conexionado del zumbador |

</center>

## <FONT COLOR=#007575>**Pines de entrada analógica**</font>
Antes de conectar los sensores de infrarrojos, que irán a los pines analógicos (aunque su salida es digital), vamos a explicar cómo usar los pines analógicos como pines digitales en las placas Arduino. La explicación original en inglés la podemos encontrar en el [enlace "Analog Input Pins"](https://www.arduino.cc/en/Tutorial/Foundations/AnalogInputPins#.U0mLZ_l_tyU).

**Convertidor A/D**

Los controladores ATmega utilizados para Arduino contienen un convertidor de analógico a digital integrado de 6 canales (8 canales en el Mini y Nano y 16 en el Mega) con una resolución de 10 bits, devolviendo números enteros de 0 a 1023. Si bien la función principal de los pines analógicos para la mayoría de los usuarios es leer sensores analógicos, los pines analógicos también tienen toda la funcionalidad de los pines de entrada/salida de propósito general (GPIO) (lo mismo que los pines digitales 0-13).

Por tanto, si necesitamos más pines de entrada y salida de propósito general, y todos los pines analógicos no están en uso, estos pueden usarse para GPIO.

**Mapeo de pines**

Los pines analógicos se pueden usar de manera idéntica a los pines digitales, usando los alias A0 (para la entrada analógica 0), A1, etc. Por ejemplo, el código para configurar el pin A0 como salida y poner en alto sería:

~~~
pinMode(A0, OUTPUT);
digitalWrite(A0, HIGH);
~~~

**Resistencias de pull-up**

Los pines analógicos también tienen resistencias pull-up, que funcionan de manera idéntica a las de los pines digitales. Se habilitan emitiendo un comando del tipo:

`pinMode(A0, INPUT_PULLUP);  // set pull-up on analog pin 0`.

Hay que tener en cuenta que activar un pull-up afectará a los valores entregados por `analogRead()`.

**Advertencias**

El comando `analogRead()` no funcionará correctamente si el pin lo hemos configurado previamente como salida. 
Si hemos puesto el pin en estado alto estando configurado como salida, la resistencia de pull-up se configurará de nuevo cuando se vuelva a cambiar a entrada.

La hoja de datos de ATmega advierte que el cambio de pines analógicos a digitales puede introducir [jitter o ruido no deseado](https://es.wikipedia.org/wiki/Jitter#:~:text=Se%20denomina%20jitter%20o%20fluctuaci%C3%B3n,se%C3%B1al%20de%20ruido%20no%20deseada.&text=El%20jitter%20es%20la%20primera%20consecuencia%20de%20un%20retraso%20de%20la%20se%C3%B1al.) en las lecturas analógicas del resto de pines. Se aconseja, después de poner los pines analógicos en modo digital, agregar un retardo corto antes de usar `analogRead()`.

## <FONT COLOR=#007575>**Sensores de infrarrojos**</font>
Una vez vista la explicación sobre pines analógicos utilizados como digitales diremos que vamos a conectar el sensor de infrarrojos izquierdo al pin A0 y el derecho al pin A1. Hay que tener especial cuidado en que los pines marcados con VCC y GND se conecten a los pines V y G respectivamente de la placa UNO. En la imagen siguiente podemos ver el conexionado de estos elementos de forma gráfica junto con los conectados anteriormente.

<center>

| Conexionado del conjunto incluyendo los sensores de infrarrojos  |
|:-:|
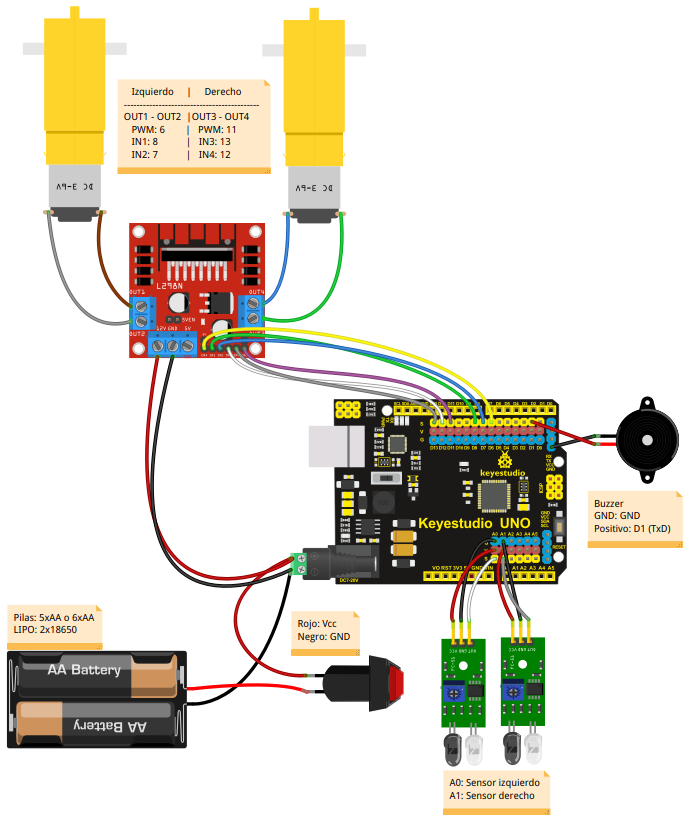
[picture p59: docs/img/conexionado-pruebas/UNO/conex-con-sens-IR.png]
Conexionado del conjunto incluyendo los sensores de infrarrojos
|  |

</center>

En la imagen siguiente vemos el detalle de conexionado de los sensores de infrarrojos.

<center>

| Detalle del conexionado de los sensores de infrarrojos  |
|:-:|
| Detalle del conexionado de los sensores de infrarrojos |

</center>

Una fotografía del detalle del conexionado en el robot la vemos a continuación.

<center>

| Fotografía del conexionado de los sensores de infrarrojos  |
|:-:|
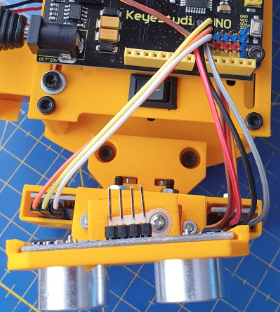
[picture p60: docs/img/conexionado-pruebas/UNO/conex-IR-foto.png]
Fotografía del conexionado de los sensores de infrarrojos
|  |

</center>

## <FONT COLOR=#007575>**Sensor de distancia HC-SR04**</font>
De nuevo utilizamos dos pines analógicos como digitales por lo que debemos tener en cuenta lo referido anteriormente sobre el tema. Vamos a conectar el Trigger del sensor al pin A2 que deberemos configurar como salida y el pin Echo a A3 que deberemos configurar como entrada. En caso de utilizar MasayloBlockly o la librería descrita en este tutorial estas definiciones estarán ya realizadas. En la imagen siguiente podemos ver el conexionado de estos elementos de forma gráfica junto con los conectados anteriormente. Se han omitido intencionadamente los cables de alimentación del sensor para mayor claridad de la imagen.

<center>

| Conexionado del conjunto incluyendo el sensor de ultrasonidos HC-SR04 |
|:-:|
| Conexionado del conjunto incluyendo el sensor de ultrasonidos HC-SR04 |

</center>

En la imagen siguiente vemos el detalle de conexionado del sensor de ultrasonidos HC-SR04 incluidos los pines de alimentación.

<center>

| Detalle del conexionado del sensor de ultrasonidos HC-SR04 |
|:-:|
| Detalle del conexionado del sensor de ultrasonidos HC-SR04 |

</center>

Una fotografía del detalle del conexionado en el robot la vemos a continuación.

<center>

| Fotografía del conexionado del sensor de ultrasonidos HC-SR04 |
|:-:|
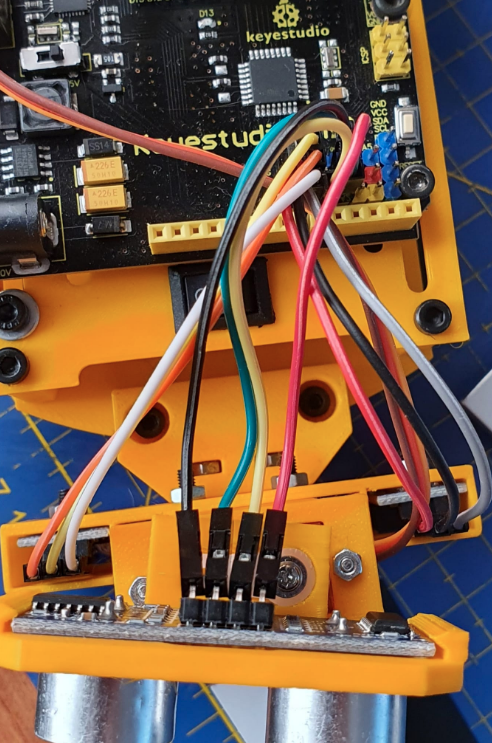
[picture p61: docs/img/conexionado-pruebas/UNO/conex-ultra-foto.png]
Fotografía del conexionado del sensor de ultrasonidos HC-SR04
|  |

</center>

## <FONT COLOR=#007575>**Servomotores**</font>
En este caso los pines que utilizaremos son los digitales 4 y 5, el primero para el brazo y el segundo para la cabeza. En la imagen siguiente podemos ver el conexionado de estos elementos de forma gráfica junto con los conectados anteriormente. Se han omitido de nuevo las conexiones de alimentación.

<center>

| Conexionado del conjunto incluyendo los servos de brazo y cabeza |
|:-:|
| Conexionado del conjunto incluyendo los servos de brazo y cabeza |

</center>

En la imagen siguiente vemos el detalle de conexionado de los dos servos SG90.

<center>

| Detalle del conexionado de los servos de brazo y cabeza |
|:-:|
| Detalle del conexionado de los servos de brazo y cabeza |

</center>

Una fotografía del detalle del conexionado en el robot la vemos a continuación.

<center>

| Fotografía del conexionado de los servos de brazo y cabeza |
|:-:|
| Fotografía del conexionado de los servos de brazo y cabeza |

</center>

## <FONT COLOR=#007575>**Encoder infrarrojos FC-03**</font>
En este caso los pines que utilizaremos son los digitales 2 y 3, que son los pines que admiten interrupciones en las placas tipo UNO, Nano, Mega, Mini y Leonardo. En la imagen siguiente (se omiten los cables de alimentación para mayor claridad) podemos ver el conexionado de estos elementos de forma gráfica junto con los conectados anteriormente.

<center>

| Conexionado del conjunto incluyendo los encoders |
|:-:|
| Conexionado del conjunto incluyendo los encoders |

</center>

En la imagen siguiente vemos el detalle de conexionado de los dos encoder FC-03.

<center>

| Detalle del conexionado de los encoder FC-03 |
|:-:|
| Detalle del conexionado de los encoder FC-03 |

</center>

Una fotografía del detalle del conexionado en el robot la vemos a continuación.

<center>

| Fotografía del conexionado de los encoder FC-03 |
|:-:|
| Fotografía del conexionado de los encoder FC-03 |

</center>

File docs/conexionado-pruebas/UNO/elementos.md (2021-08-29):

# <FONT COLOR=#8B008B>Descripción de placas y sensores</font>
En este apartado vamos a realizar una descripción básica de las distintas placas, sensores y elementos que se utilizan en la construcción del robot.

## <FONT COLOR=#007575>**Placa Keyestudio UNO Ks0172**</font>
Se trata de la placa [Ks0172](https://wiki.keyestudio.com/Ks0172_keyestudio_UNO_with_Pin_Header_Interface) basada en Arduino UNO con el microcontrolador ATmega328P que incorpora conectores de 3 pines que incluyen la patilla asociada y la alimentación y que facilita el conexionado de elementos sin necesidad de utilizar protoboard. En la imagen siguiente podemos ver esta placa con sus descripciones básicas y este es el [enlace al archivo fuente](../../img/conexionado-pruebas/UNO/uno.svg).

<center>

| Placa Keyestudio UNO Ks0172 |
|:-:|
| Placa Keyestudio UNO Ks0172 |

</center>

<FONT COLOR="#FF0000"><FONT SIZE="6"> IMPORTANTE:</FONT></FONT>

El interruptor deslizante permite escoger entre las alimentaciones de 5V o 3.3V. En nuestro caso nos aseguraremos de que está en la **posición 5V**.

También es importante tener disponible un gráfico con la funcionalidad de cada pin o diagrama pinout como el que vemos en la imagen siguiente y este es el [enlace a su archivo fuente](../../img/conexionado-pruebas/UNO/Ks0172-keyestudio-UNO-pinout.svg)

<center>

| Pinout de la Placa Keyestudio UNO Ks0172 |
|:-:|
| Pinout de la Placa Keyestudio UNO Ks0172 |

</center>

## <FONT COLOR=#007575>**Placa Drivers L298**</font>
Esta placa está basada en el chip L298N y permite controlar la velocidad y el sentido de giro de dos motores de corriente continua o un motor paso a paso bipolar con un consumo máximo de dos amperios. Cuenta con diodos de protección y un regulador LM7805 que suministra 5V a la parte lógica del integrado L298N. Se disponen jumpers de selección para habilitar cada una de las salidas del módulo (A y B). La salida A esta conformada por OUT1 y OUT2 y la salida B por OUT3 y OUT4. Los pines de habilitación son ENA y ENB (Enable A y Enable B) respectivamente. En la siguiente imagen vemos esta placa con sus descripciones básicas y este es el [enlace al archivo fuente](../../img/conexionado-pruebas/UNO/L298.svg).

<center>

| Placa L298 |
|:-:|
| Placa L298 |

</center>

Este módulo con el L298N nos permite alimentar nuestro Arduino a partir de la salida de 5V con un límite de 500 mA. Debemos también tener presente que el módulo entrega una tensión a los motores en torno a 3V menor que la tensión a la que lo alimentamos.

Los pines *Vin* y *GND* son los de alimentación del módulo con una tensión que puede ir de 3V a 35V. El pin *Vlog* (Vlógico) tiene dos modos de funcionamiento dependiendo de que el jumper *Regulador* esté o no colocado. Las condiciones de funcionamiento son:

* **Jumper colocado:** El regulador LM7805 está activado y en Vlog habrá una tensión de 5V siempre que el módulo esté alimentado con una tensión máxima de hasta 12V. Si lo alimentamos con una tensión superior tendremos que quitar el jumper y alimentar con 5V la lógica del módulo a través de este pin.
* **Jumper sin colocar:** El regulador LM7805 está desactivado y tenemos que alimentar la lógica del módulo a través de Vlog.

Debemos tener <FONT COLOR="#FF0000">¡Cuidado!</FONT> si introducimos corriente por Vlog con el jumper de regulación colocado podemos provocar daños en el módulo.

El resto de conexiones se utilizan para el control de motores y para el caso de motores DC su utilización es la siguiente:

* **Salidas para motores:** Entregan la energía para mover los motores y debemos conectarlo de forma que cuando marquemos, por ejemplo, mover adelante ambos motores giren en el mismo sentido. Si no lo hacen basta con invertir la polaridad de la conexión.
* **Pines IN1 a IN4:** IN1 e IN2 permiten controlar el sentido de giro del motor A mientras que IN3 e IN4 lo hacen con el del motor B. En la tabla siguiente se resume el funcionamiento de estos pines.

<center>

| IN1 | IN2 | IN3 | IN4 | Sentido de Giro |
|:-:|:-:|:-:|:-:|---|
| High | Low | High | Low | Directo |
| Low | High | Low | High | Inverso |
| Low | Low | Low | Low | Paro |

</center>

* **Velocidad de giro:** Tenemos que quitar los jumpers y usar los pines ENA y ENB. Estos pines debemos conectarlos a dos salidas PWM de la placa Arduino para poder enviarle un valor entre 0 y 255 que controle la velocidad de giro. Con los jumpers colocados, los motores girarán siempre a la misma velocidad.

## <FONT COLOR=#007575>**Motores DC 3 a 6V**</font>
Motor de continua de 3V a 6V con doble eje y caja reductora. El doble eje facilita la colocación de un encoder óptico para realizar un control de velocidad en lazo cerrado.

En la tabla siguiente se resumen los principales parámetros de estos motores con una reductora 48:1 para distintas tensiones de alimentación.

<center>

| | 3V | 5V | 6V |
|---|:-:|:-:|:-:|
| Velocidad sin carga | 125 rpm | 200 rpm | 230 rpm |
| velocidad con carga | 95 rpm | 160 rpm | 175 rpm |
| Torque | 7.8 Ncm | 9.8 Ncm  | 10.8 Ncm |
| Consumo | 100 a 130 mA | 120 a 140 mA | 130 a 150 mA |

</center>

El aspecto físico de estos motores lo vemos en la imagen siguiente.

<center>

| Motores DC 3 a 6V |
|:-:|
| Motores DC 3 a 6V |

</center>

## <FONT COLOR=#007575>**Zumbador**</font>
Si queremos reproducir sonidos de forma sencilla y económica podemos utilizar un zumbador o buzzer pasivo como el que vemos en la imagen siguiente.

<center>

| Zumbador pasivo |
|:-:|
| Zumbador pasivo |

</center>

El dispositivo suele venir con una pegatina que debemos retirar para que el sonido salga con toda su potencia del mismo. Esta pegatina tiene utilidad en procesos de fabricación automatizada para proteger al buzzer en la fase de lavado.

Normalmente no tienen polaridad, pero si está marcada en la carcasa o es distinguible por la diferente longitud de los pines lo mejor es respetarla, siendo normalmente el pin marcado el positivo o patilla mas larga.

El buzzer pasivo, a diferencia del activo, no tiene un oscilador interno y esto obliga a generar la frecuencia desde Arduino, para ello disponemos de la función [tone()](https://www.arduino.cc/reference/en/language/functions/advanced-io/tone/) que implementa el IDE.

## <FONT COLOR=#007575>**Sensores de infrarrojos**</font>
Hemos optado por poner al robot una pareja de sensores de reflexión fotoeléctrica con distancia de detección ajustable entre 2 y 30cm (20 y 300mm), conocido como sensor de infrarrojos FC-51, como el que vemos en la imagen siguiente, donde se indica el potenciómetro de ajuste de distancia, el diodo emisor de IR y el fototransistor o detector de reflexión. Respecto a la distancia de detección indicar que la citada anteriormente es la que la inmensa mayoría de vendedores ponen y, aunque hay algunos que reducen esta distancia bastante, es algo que debemos experimentar nosotros mismos teniendo en cuenta las condiciones de luminosidad en las que estemos trabajando.

<center>

| Modelo de sensor IR escogido |
|:-:|
| Modelo de sensor IR escogido |

</center>

Recordemos el funcionamiento básico del sistema. El LED infrarrojo emite luz infrarroja, o sea, de menor frecuencia (o mayor longitud de onda) que la que nuestros ojos nos permiten ver, es decir, para nosotros es invisible. El sensor que hemos elegido funciona cuando esta luz choca contra una superficie negra que la reflejará y llegará al fototransistor. Existen muchas clases de sensores de este tipo y hemos escogido este por su amplio rango de ajuste y su posibilidad de montaje vertical. Utilizando un par de estos sensores podemos seguir una linea detectando si se sale por la derecha o por la izquierda de la misma y rectificar la dirección de avance hasta conseguir estar de nuevo en la línea.

Este sensor tiene 3 pines de conexión, Vcc o 5V y GND para la alimentación y D0 u OUT como salida de señal que indicará si está llegando o no el reflejo del LED al fototransistor. En el esquema de la imagen siguiente se puede estudiar el funcionamiento electrónico de esta plaquita.

<center>

| Esquema sensor infrarrojos |
|:-:|
| Esquema sensor infrarrojos |

</center>

El LM393 está configurado como comparador entre el nivel de tensión ajustado mediante VR1 que es entregado al terminal inversor y el nivel de entrada en el terminal no inversor, que va a depender de si el fototransistor recibe o no reflexión del infrarrojo emitido por el LED, si está recibiendo reflexión el fototransistor se encenderá el LED indicador de estado y tenemos el estado bajo o LOW en D0. Si no se recibe reflexión el LED no se iluminará y se envía un estado alto o HIGH a D0.

Mediante el potenciómetro ajustamos la sensibilidad del fotorreceptor.

## <FONT COLOR=#007575>**Sensor de distancia HC-SR04**</font>
El sensor genera y emite una serie de tonos de ultrasonidos a una frecuencia de 40 kHz (no perceptibles al oído humano) que si rebotan en una superficie vuelven y son captados por un micrófono receptor de ultrasonidos que incorpora el propio sensor. Midiendo el tiempo que tardan en volver los tonos enviados podemos calcular la distancia a la que se encuentra el objeto sobre el que han rebotado. El propio circuito realiza los cálculos necesarios para determinar la distancia a la que está la superficie. El sistema es similar al que usan algunos animales como ballenas, murciélagos y delfines, para localizar obstáculos y presas.

El HC-SR04 es un sensor de distancia de baja precisión, en teoría con un rango de medición de 2cm a 400 cm, con una resolución de 0.3cm, pero en la práctica se limita a un rango entre 20cm y 2 metros.

El aspecto del HC-SR04 es muy característico y se reconoce con facilidad porque tiene dos "ojos" que realmente son los dispositivos de emisión y recepción de ultrasonidos que integra este módulo, y es justo por esto por lo que hemos dotado al robot de una cabeza giratoria que en el funcionamiento parecerá que el robot mira a un lado y otro.

En la imagen siguiente vemos el aspecto real del sensor y el principio de funcionamiento de forma gráfica.

<center>

| Aspecto del HC-SR04 y principio de funcionamiento |
|:-:|
| Aspecto del HC-SR04 y principio de funcionamiento |

</center>

Las características técnicas más relevantes del HC-SR04 son:

* Dispone de 4 pines, dos son para alimentación (Vcc) y masa (GND), disparador (Trigger) y receptor (Echo). En la imagen siguiente se aprecian claramente como están distribuidos estos pines en el sensor.

<center>

| Pinout del HC-SR04 |
|:-:|
| Pinout del HC-SR04 |
| Imagen basada en la publicada en [theengineeringprojects](https://www.theengineeringprojects.com/) |

</center>

* Alimentación: 5v
* Frecuencia de ultrasonidos: 40 Khz
* Consumos: en stand-by menor de 2mA y trabajando en torno a 15mA
* Ángulo: menor de 15º

Veamos ahora en que se basan los cálculos que realiza el sensor. En principio lo que hace, como ya se ha indicado, es contar el tiempo desde que se envia el pulso hasta que se recibe respuesta con lo que se puede determinar la distancia. Recordemos que:

<center>

$velocidad=\dfrac{espacio}{tiempo}\Rightarrow espacio=velocidad\cdot tiempo$

</center>

La velocidad es la del sonido es de 343 m/s a 20 ºC y un 50% de humedad relativa. A nosotros nos va a interesar expresar esta velocidad en cm/us, para lo que hacemos lo siguiente:

<center>

$343\dfrac{m}{s}\cdot 100\dfrac{cm}{m}\cdot \dfrac{1}{1000000}\dfrac{s}{\mu s}=0.0343\dfrac{cm}{\mu s}\Rightarrow espacio-ida=0.0343\cdot tiempo$

</center>

Es decir, el sonido tarda 0.0343 microsegundos en recorrer un centímetro, que será el tiempo que tarda el sonido en ir desde el amisor al objeto en el que rebota. Teniendo en cuenta que desde que se emite el pulso, rebota y es recibido el espacio recorrido será aproximadamente el doble que el calculado podemos expresar la distancia o espacio recorrido como:

<center>

$espacio=\dfrac{espacio-ida}{2}=0.01715\cdot tiempo$

</center>

Ecuación que nos permite saber la distancia a la que se encuentra un determinado objeto.

## <FONT COLOR=#007575>**Servomotores**</font>
Los servomotores, abreviado servos, son motores de corriente continua que además tienen una reductora con el fin de disminuir su velocidad de giro y aumentar el par motor en el eje. También incorporan sistema electrónico de control que permite hacerlos girar un determinado ángulo. Esa electrónica permite al servo saber en todo momento cual es su posición. Generalmente giran menos de una vuelta completa, 180º es bastante común, aunque tienen un ángulo variable según el modelo, pero existen ya servos de rotación continua que giran 360 grados.

Existen infinidad de modelos de servomotor y en nuestro caso vamos a utilizar Micro Servos del tipo 9g SG90. En la imagen siguiente vemos el aspecto y los elementos que incorporan este tipo de servos.

<center>

| Aspecto y elementos de los servos 9g SG90 |
|:-:|
| Aspecto y elementos de los servos 9g SG90 |

</center>

Los servos tienen un funcionamiento muy parecido y la programación suele variar muy poco de unos a otros, aunque siempre es conveniente mirar el [datasheet](../../img/conexionado-pruebas/UNO/9g-sg90-datasheet.pdf) del que vamos a utilizar para mayor seguridad.

Debido a que la resolución de la señal PWM que podemos conseguir con una placa tipo UNO el ángulo de giro que podremos mover un servo será mayor de un grado, aunque el servo puede moverse con una resolución mayor.  Las características de la señal PWM nos indican que debemos generar un pulso de trabajo entre 1 ms y 2 ms y con un periodo de 20 ms (50 Hz), es decir, solamente podremos cambiar de posición del servo cada 20 ms.

Los microservos se pueden alimentar directamente de la placa UNO dado que su consumo es lo suficientemente bajo para ello, pero si es necesario, dependiendo del modelo de servo, habrá que alimentarlo con una fuente externa teniendo siempre la precaución de que las GNDs de la placa UNO y del servo queden interconectadas.

Los colores usuales de los tres cables que salen del servo son los siguientes:

* Negro o Marrón: GND
* Rojo: Alimentación
* Blanco o Naranja: Señal de control del servo (pulso enviado al servomotor)

En la imagen siguiente se corrobora esta información.

<center>

| Colores de los cables en los servos 9g SG90 |
|:-:|
| Colores de los cables en los servos 9g SG90 |

</center>
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

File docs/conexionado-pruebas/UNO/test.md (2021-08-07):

# <FONT COLOR=#8B008B>Pruebas básicas de funcionamiento</font>
Una vez analizados y conectados los distintos elementos iremos haciendo pequeños programas bien mediante la aplicación `Masaylo Blockly` basada en `Blocklino de Fontaine Jean Philippe`, y pensada para programar robots utilizando un entorno gráfico o de programación por bloques, o bien utilizando el IDE de Arduino. En el apartado de software se pueden encontrar los enlaces de descarga y toda la información de la aplicación.

## <FONT COLOR=#007575>**Alimentación**</font>
Colocamos las pilas AA en su lugar respetando la polaridad de las mismas y accionamos el interruptor. Si todo es correcto en ambas placas se debe encender un diodo LED rojo indicativo de que están alimentadas, tal y como observamos en la imagen siguiente:

<center>

| Primer encendido |
|:-:|
| Primer encendido |

</center>

En este punto vamos a probar también que se graba correctamente firmware en la placa UNO a partir de `Masaylo Blockly 1.1.1 Beta o posterior`. Para ello hemos creado y almacenado el programa [blink.bloc](../UNO/tests/blink.bloc) que vemos en la imagen siguiente.

<center>

| Programa blink.bloc |
|:-:|
| Programa blink.bloc |

</center>

Si cargamos el programa y dejamos sin accionar el interruptor observaremos como parpadea el LED asociado al pin 13 en la placa UNO pero la placa del driver no está alimentada y por tanto su LED permanece apagado. En la animación siguiente vemos el parpadeo del LED y el resultado de accionar el interruptor.

<center>
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

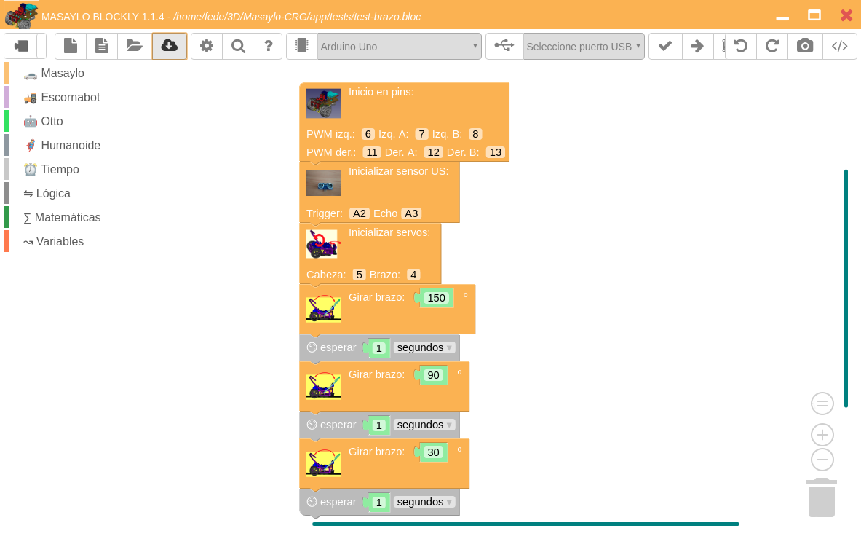
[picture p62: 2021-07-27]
docs/img/conexionado-pruebas/UNO/test/demo-brazo.png

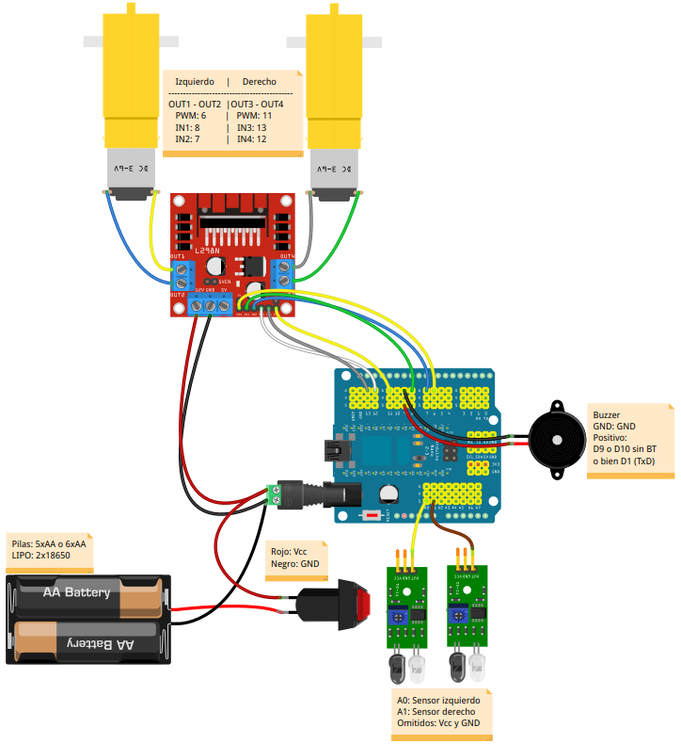
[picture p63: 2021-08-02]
docs/img/conexionado-pruebas/Nano/conex-con-sens-IR.png

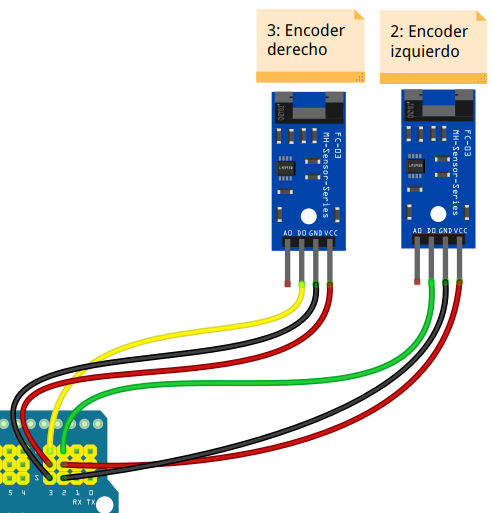
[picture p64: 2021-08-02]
docs/img/conexionado-pruebas/Nano/conex-encoders.png

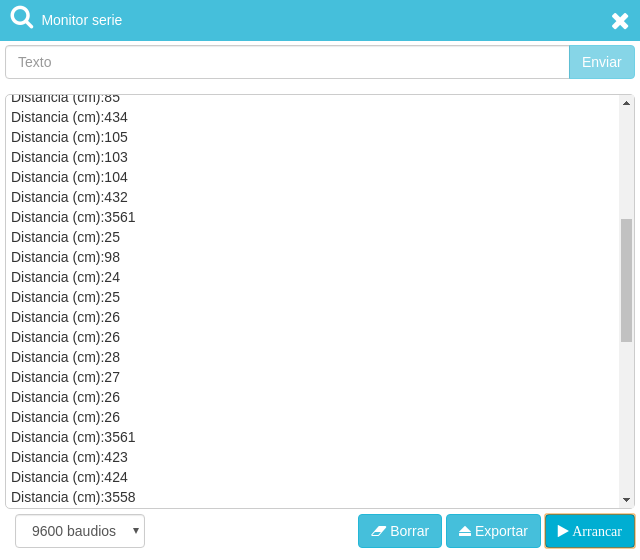
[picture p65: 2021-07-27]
docs/img/conexionado-pruebas/UNO/test/HC-SR04-resultado.png

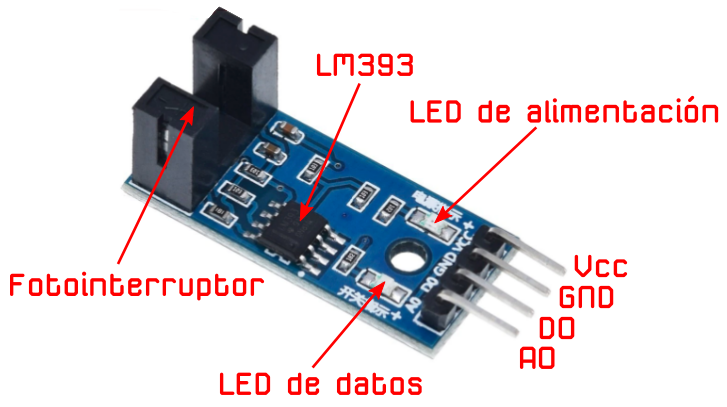
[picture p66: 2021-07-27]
docs/img/conexionado-pruebas/UNO/partes-FC-03.png

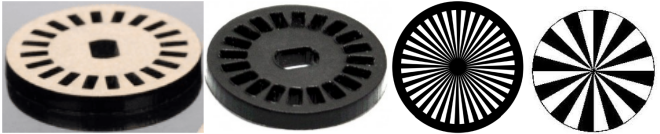
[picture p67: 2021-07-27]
docs/img/conexionado-pruebas/UNO/discos-encoder.png

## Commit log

2021-06-13 Primera subida de 3D
    [ballcaster.step, ballcaster.stl, base-servo-src.FCStd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]
2021-06-14 Primera subida de ensamble
2021-06-15 Otro formato de realizar el paso a paso
2021-06-24 ensamble acabado pendiente de revision
2021-07-06 actualizacion ultrasonidos
    [soportes-ultrasonidos.FCStd, ultrasonidos-fijo.step, ultrasonidos-fijo.stl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]
2021-07-07 añadir ruedas nuevas
    [rueda-dos-juntas-ancha-eje-motor-mayor.step, rueda-dos-juntas-ancha-eje-motor-mayor.stl, rueda-dos-juntas-eje-motor-mayor.step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]
2021-07-07 actualizado con step el tema ruedas
2021-07-13 Cambios en 3D
    [rueda-dos-juntas-ancha-eje-motor-mayor.step, rueda-dos-juntas-ancha-eje-motor-mayor.stl, rueda-dos-juntas-eje-motor-mayor.step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]
2021-07-27 Primer acabado UNO
    [soporte-ballcaster-media.FCStd, soporte-ballcaster-media.step, soporte-ballcaster-media.stl]
2021-08-02 Actualización a falta de test del Nano
2021-08-08 Incorporación de la librería
2021-08-09 Subida de todo lo de Antonio
2021-09-05 Ultimos cambios de Pedro
2021-11-24 Ensambles, merchandising, medios
    [ensamble3.FCStd]
2021-11-29 articulo periodico la tribuna CR
2022-06-12 Nuevo brazo y ballcaster
    [brazo-modificado-src.FCStd, brazo-modificado.step, brazo-modificado.stl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]
